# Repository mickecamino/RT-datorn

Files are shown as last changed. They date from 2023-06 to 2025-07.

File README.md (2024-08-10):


# RT-datorn
## En 6809-dator designad av Åke Holm (CÅ-Elektronik) på 80-talet. Den presenterades i tidningen Radio & Television, därav namnet RT-datorn. Operativsystemet var FLEX 9 eller FLEX 3.01 från Technical Systems Consultants 
### Med tillstånd av Åke Holm att publicera alla detaljer om RT-datorn
Två versioner finns av denna dator:

Den "gamla" som publicerades i ett antal artiklar i tidningen Radio & Television

Den "nya" som fanns i en artikel i tidningen Elektronikvärlden nr 4 1983.

## Följande kort fanns till den "gamla" RT-datorn:
* CÅ-790  - Videoterminal
* CÅ-800  - Första versionen av moderkortet
* CÅ-801  - Andra versionen av moderkortet
* CÅ-6819 - CPU-kort
* CÅ-6848 - Minneskort 48kb med dynamiska RAM-kretsar
* CÅ-8001 - ACIA, 2 st serieportar
* CÅ-8002 - PIA, 2 parallella portar
* CÅ-8003 - KCS-modem 300/1200 baud
* CÅ-8004 - Programmerbar timer med 6840
* CÅ-8005 - Digitalklocka med MM5318
* CÅ-8006 - HEX-display & tangenter
* CÅ-8008 - 16 ingångars 8-bitars A/D-omvandlare
* CÅ-8010 - EPROM-programmerare
* CÅ-8013 - Korthållsmodem 300 baud
* CÅ-8014 - Centronics-parallell
* Cå-8015 - Ny version av klock-kort med MSM5832
* CÅ-8016 - Ljudeffektskrets med SN76477
* CÅ-8017 - Flexskivekort
* CÅ-8018 - IEEE-488-bus anpassning
* CÅ-8020 - DEBUG-kort
* CÅ-8025 - EPROM-kort
* CÅ-8027 - Flyttalsprocessor AM9511
* CÅ-8030 - Okänt kort, donerat av Åke Holm. Funktion okänd.
* CÅ-8034 - Okänt kort, donerat av Åke Holm. Funktion okänd.
* CÅ-8043 - Färg-tv som dataskärm
* CÅ-8091 - Lab-kort med PIA
* CÅ-8092 - Lab-kort för ACIA/SSDA/ADLC
* CÅ-8095 - Förlängningskort för 22-polig buss
* CÅ-9000 - Förlängningskort för CPU-kort

## Följande kort fanns till den "nya" RT-datorn:

* CÅ-812 - CPU-kort
* CÅ-813 - Kommunikation
* CÅ-814 - Minneskort 48 kB med dynamiska RAM-kretsar
* CÅ-815 - Video-terminalkort
* CÅ-816 - EPROM-kort
* CÅ-817 - Diskett-interface
* CÅ-831 - Terminalkort enkelt
* CÅ-833 - Nyare kommunikationskort/RTC med MSM5832, ACIA och Centronics-port
* CÅ-834 - Minneskort med statiska RAM-kretsar
* CÅ-836 - Nydesignat 192 kb EPROM-kort med 1 kb RAM 
* CÅ-837 - Diskettinterface med Double Density

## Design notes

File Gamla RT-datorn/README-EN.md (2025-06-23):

## The following arcticles were published in the Swedish magazine Radio & Television
```
* Video terminal CA-790
* Part 1 - RT 1979-8
* Part 2 - RT 1979-9

* CPU and peripheral cards    
* Part 1  - RT 1979-12  - CA-6819 CPU board
* Part 2  - RT 1980-1   - CA-800 motherboard, CA-8001 ACIA (serial board)
* Part 3  - RT 1980-2   - CA-8004 Timer, CA-8091 PIA Lab board
* Part 4  - RT 1980-3   - CA-8017 Floppy interface
* Part 5  - RT 1980-5   - CA-8006 HEX terminal
* Part 6  - RT 1980-6/7 - CA-8003 cassette modem
* Part 7  - RT 1980-10  - CA-8005 Real Time Clock
* Part 8  - RT 1981-12  - CA-8010 EPROM-programmer
* Part 9  - RT 1981-1   - CA-8025 EPROM board
* Part 10 - RT 1981-3   - CA-8018 IEEE board
* Part 11 - RT-1981-9   - CA-8043 Color-TV as monitor

```

## The following boards was available to the "old" RT-computer:
* CA-790  - Video terminal
* CA-800  - First version of motherboard
* CA-801  - Second version of motherboard
* CA-6819 - CPU board
* CA-6848 - Memory board2 48kB with DRAM
* CA-8001 - ACIA, 2 st serial ports
* CA-8002 - PIA, 2 parallel ports
* CA-8003 - KCS-modem 300/1200 baud
* CA-8004 - Programmable timer with 6840
* CA-8005 - Real Time Clock with MM5318
* CA-8006 - HEX-display & keyboard
* CA-8008 - 16 input 8-bita A/D-converter
* CA-8010 - EPROM-programmer
* CA-8013 - 300 baud modem
* CA-8014 - Centronics-parallel
* CA-8015 - New Real time Clock with MSM5832
* CA-8016 - Sound board with SN76477
* CA-8017 - Floppy controller
* CA-8018 - IEEE-488-bus
* CA-8020 - DEBUG board
* CA-8025 - EPROM board
* CA-8027 - Floating Point Processor with AM9511
* CA-8030 - Unknown board, donated by Åke Holm. Function unknown
* CA-8034 - Unknown board, donated by Åke Holm. Function unknown
* CA-8043 - Color-TV as monitor
* CA-8091 - Lab board with PIA
* CA-8092 - Lab board for ACIA/SSDA/ADLC
* CA-8095 - Riser board for 22-pin bus
* CA-9000 - Riser board for CPU card

### The peripheral boards position on the motherboard determines the address:
RT-computer addressing
* J1  - E000-E00F = CA-8001 ACIA
* J2  - E010-E01F = CA-8017 Floppy controller
* J3  - E020-E02F = 
* J4  - E030-E03F = CA-8004 Timer 6840
* J5  - E040-E04F = 
* J6  - E050-E05F = CA-8005 RTC
* J7  - E060-E06F = CA-8010 EPROM-programmer
* J8  - E070-E07F = 
* J9  - E080-E08F = CA-8008 A/D-converter
* J10 - E090-E09F = 
* J11 - E0A0-E0AF = 
* J12 - E0B0-E0BF = CA-8003 cassette modem
* J13 - E0C0-E0CF = CA-8025 EPROM-card
* J14 - E0D0-E0DF = 
* J15 - E0E0-E0EF = CA-8006 HEX-terminal card

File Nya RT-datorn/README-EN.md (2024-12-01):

# The New RT-computer
## A FLEX 6809 computer designed by Åke Holm (CÅ-Elektronik) during the 1980's. It was featured in the magazine Radio & Television, hence the name RT-computer.
### With permission by Åke Holm to publish all details about the RT-computer

## The following boards were made for the "new" RT-computer:

* CÅ-812 - CPU-board  
The CPU-board featured static RAM addressed at $C000 - DFFF.  
Two sockets for EPROM's addressed at $F000 to FFFF. The CPU-board handles the decoding for the peripheral boards located at address $E000 - $E0FF. An extra RAM is addressed between $E100 and $E3FF to be used for the monitor and terminal software without interfering with the operating system FLEX 9.1.  

* CÅ-813 - I/O  
The new board for serial communication is called CÅ-813 and it replaces the older boards 8001, 8014 and 8015.  
It features a programmable serial communication IC for V24, a printer connection with parallel interface (Centronics) and a Real Time Clock with battery backup.  
The connection for printer and serial is via a 60-pin connector. 36 pins for the printer and 24 for the serial interface.  
See also CÅ-833

* CÅ-814 - memory board  
The memory board 814 replaces CÅ-6848. It is identical with one exception, the refresh for the dynamic memory chips is made continuously, instead as before, with 32 kHz. The memory size is 48 kB.  
Sea also CÅ-834

* CÅ-815 - Video terminal
The terminal is a completely new design. It is a memory mapped terminal, 24 lines and 80 columns. The board features the Motorola MC6845, display memory and a PIA for connecting the keyboard via a 26-pin connector. The pin out for the keyboard is identical with the CÅ-790. The display memory is located between $E800 and $EFFF, the CPU on board 812 is responsible for all terminal functions. All characters between computer and terminal is done without serial communication. The speed is much faster due to this. The character setup in the terminal is Swedish. 

* CÅ-816 - EPROM-board  
The new EPROM-board is called 816 and has 16 EPROM-sockets for 2532 EPROM's, each EPROM contains 4 kb. A total of 64 kb permanent memory is possible.. 
The board can hold for example the operating system FLEX and a BASIC interpreter. The addressing of the EPROM board is done via one single address. With a small software routine, loading from the boards EPROM to computer RAM is really simple.  
The board replaces the 8025-board.  
Se also CÅ-836  

* CÅ-817 - Floppy Controller  
The driver IC's for floppy drives on board 817 is equal to the board 8017. Up to four floppy drives, either single or double sided, single density can be connected.  
See also CÅ-837.  

* CÅ-831 - Terminal board - simple  
The simple hexadecimal terminal 8006 is replaced by 831, almost identical except that 831 also have a PIA for lab use.  

* CÅ-833 - I/O  
A newer design that replaces CÅ-813.  
Serial communication with 6850, a parallel printer output (Centronics) and a Real Time Clock with battery backup.  

* CÅ-834 - memory board  
New memory board for static memory, 6116 2k or EPROM 2716. Replaces CÅ-814.  

* CÅ-836 - 192 kb EPROM-board with 1 kb RAM.  
A new board for the RT-computer, designed by me. Three 27512 EPROM's gives 192 kb resident program memory in the computer, 1 kb RAM addressed at $E400-E7FF for a command table used by FLEX.   
With a small program, re-written by me based on a program from the magazine MPU-laren 1983-2, creates a command table for FLEX to load utilities from EPROM instead of floppy drives.  
FLEX can also be stored on this card and loaded from a new X command in CBUG. NOTE! Requires the updated CBUG4.4.  

* CÅ-837 - Floppy Controller with support for Double Density  
Replaces CÅ-817

### Memory mapping
```
Adres Function             board
$FFFF ----------------------------
      2k EPROM             CPU 812
$F800 ----------------------------
      2k EPROM             CPU 812
$F000 ----------------------------
      2k terminal RAM      CRT 815
$E800 ----------------------------
      1k RAM                   836
$E400 ----------------------------
      768 bytes RAM        CPU 812
$E100 ----------------------------
      CRTC + PIA           CRT 815
$E0F0 ----------------------------
      spare
$E0DF ----------------------------
      EPROM #3             816/836
$E0D0 ----------------------------
      EPROM #2             816/836
$E0C0 ----------------------------
      EPROM-board #1       816/836
$E0B0 ----------------------------
      spare
$E01F ----------------------------
      Floppy Controller    817/837
$E010 ---------------------------
      I/O                  813/833
$E000 ----------------------------
      8k static RAM        CPU 812
$C000 ----------------------------
      48k dynamic RAM      814/834
$0000 ----------------------------
```

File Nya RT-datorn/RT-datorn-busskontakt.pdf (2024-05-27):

C64 Europakontakt
1a | GND | GND | 1c
2a | GND | GND | 2c
3a | GND | GND | 3c
4a | -12V | -12V | 4c
5a | +12V | +12V | 5c
6a | -------- | EXT-RESET | 6c
7a | A | B | 7c
8a | BA | HALT | 8c
9a | -------- | -------- | 9c
10a | E400 | E800 | 10c
11a | A14 | A15 | 11c
12a | A12 | A14 | 12c
13a | A10 | A11 | 13c
14a | A8 | A9 | 14c
15a | A6 | A7 | 15c
16a | A4 | A5 | 16c
17a | A2 | A3 | 17c
18a | A0 | A1 | 18c
19a | I/O-SEL | R/W | 19c
20a | RESET | E | 20c
21a | IRQ | GND | 21c
22a | GND | D0 | 22c
23a | GND | D1 | 23c
24a | GND | D2 | 24c
25a | GND | D3 | 25c
26a | GND | D4 | 26c
27a | GND | D5 | 27c
28a | GND | D6 | 28c
29a | GND | D7 | 29c
30a | +5V | +5V | 30c
31a | +5V | +5V | 31c
32a | +5V | +5V | 32c

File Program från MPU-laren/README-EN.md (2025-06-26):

# Program from MPU-laren
## A collection of software presentd in MPU-laren 
Hare are some programs presented in MPU-laren from # 1 - 1978 to the last number #1 - 1990 
### 1978-1
```
MASTER.BAS  - Mastermind - text based
MONLAND.BAS - Classic game - land the lunar lander on the moon
```
### 1979-2
```
EIGHTMEN.BAS - Arcade game
```
### 1979-3
```
FODELSED.BAS - Date information for birthday
FODELSED.TXT - Information about the program (in Swedish)
```
### 1979-4
```
QUEST.BAS     - Adventure game
HEX.BAS       - Convert HEX to DECIMAL
```
### 1980-1
```
DJUR.BAS      - Guess the animal
DJURBIBL.SYS  - library for DJUR.BAS
```
### 1980-2
```
GENEO.BAS     - Genealogy program, Swedish
WHIST.BAS     - Card Game
```
### 1980-3
```
OTHELLO.BAS   - Othello
```
### 1980-4
```
INFO.TXT      - Address register, info text, NOTE: Swedish Only
EJCT-82.TXT   - Address register, other terminal than CT-92
DEL-1.BAS     - Address register, part 1
DEL-2.BAS     - Address register, part 2
HUVUD-1.BAS   - Address register, main program 1
HUVUD-2.BAS   - Address register, main program 2

SHOOTSTA.BAS  - Shoot stars - space game
KYRKA.BAS     - prints a church in ASCII on a matrix printer
```
### 1981-1
```
GOBANG.BAS    - Tic-tac-Toe with 19 x 19 squares
PATCHTS.ASM   - Patch a byte on specific track ans sector
```
### 1981-2
```
CLOCK.ASM     - IRQ-based clock
SYSTES.ASM    - System test of FLEX 9
```
### 1981-3
```
LOTTO.BAS     - Lotto program
RELOCATE.ASM  - Program for relocating binary files
```
### 1981-4
```
MASTER.BAS    - Mastermind
MATEMAT.BAS   - Match game
```
### 1982-1	
```
CLOCKSET.ASM  - Software for setting up the MSM5832 RTC
DIR.ASM       - Better version than CAT for listing files
FLEXPAT.ASM   - Patch for FLEX 2.65, read MSM5832
UNDEL.ASM     - Undeletes files
VOXMEM.ASM    - Program that speech - needs VS-1 Speaker Board
VOXMEM1.ASM   - Program that speech - needs VS-1 Speaker Board - alternative voice
```
### 1982-2
```
BACKUP.ASM    - Backup-program - backup from one diskette to another (0 to 1)
LOGG.BAS      - Log program for HAM radio
LOGG790.BAS   - Log program for HAM radio, for CÅ-790 terminal
```
### 1983-2
```
PROM.ASM      - Program that download PROM based files to RAM
PROM.TXT      - Information about PROM.ASM
```
### 1984-2
```
PIA.BAS       - Program to help initialize PIA
```
### 1984-3
```
BOK8.BAS      - Simple book keeping software
BOK8.TXT      - Information about the program.
```
### 1985-3
```
DSKSPD.ASM    - Program for measuring the speed of a diskette. For the CÅ-8017
```

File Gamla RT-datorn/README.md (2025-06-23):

## Följande artiklar publicerades i Radio & Television
```
* Videoterminalen CÅ-790
* Del 1 - RT 1979-8
* Del 2 - RT 1979-9

* CPU och periferikort    
* Del 1  - RT 1979-12  - CÅ-6819 CPU-kort
* Del 2  - RT 1980-1   - CÅ-800 moderkort, CÅ-8001 ACIA (seriekort)
* Del 3  - RT 1980-2   - CÅ-8004 Timer, CÅ-8091 PIA Labbkort
* Del 4  - RT 1980-3   - CÅ-8017 Flexskiveinterface
* Del 5  - RT 1980-5   - CÅ-8006 HEX terminalkort
* Del 6  - RT 1980-6/7 - CÅ-8003 kassettmodem
* Del 7  - RT 1980-10  - CÅ-8005 Realtidsklocka
* Del 8  - RT 1980-12  - CÅ-8010 EPROM-programmerare
* Del 9  - RT 1981-1   - CÅ-8025 EPROM-kort
* Del 10 - RT 1981-3   - CÅ-8018 IEEE-kort
* Del 11 - RT-1981-9   - CÅ-8043 Färg-TV som dataskärm
```

## Följande kort fanns till den "gamla" RT-datorn:
* CÅ-790  - Videoterminal
* CÅ-800  - Första versionen av moderkortet
* CÅ-801  - Andra versionen av moderkortet
* CÅ-6819 - CPU-kort
* CÅ-6848 - Minneskort 48kB med dynamiska RAM-kretsar
* CÅ-8001 - ACIA, 2 st serieportar
* CÅ-8002 - PIA, 2 parallella portar
* CÅ-8003 - KCS-modem 300/1200 baud
* CÅ-8004 - Programmerbar timer med 6840
* CÅ-8005 - Digitalklocka med MM5318
* CÅ-8006 - HEX-display & tangenter
* CÅ-8008 - 16 ingångars 8-bitars A/D-omvandlare
* CÅ-8010 - EPROM-programmerare
* CÅ-8013 - Korthållsmodem 300 baud
* CÅ-8014 - Centronics-parallell
* Cå-8015 - Ny version av klock-kort med MSM5832
* CÅ-8016 - Ljudeffektskrets med SN76477
* CÅ-8017 - Flexskivekort
* CÅ-8018 - IEEE-488-bus anpassning
* CÅ-8020 - DEBUG-kort
* CÅ-8025 - EPROM-kort
* CÅ-8027 - Flyttalsprocessor AM9511
* CÅ-8030 - Okänt kort, donerat av Åke Holm. Funktion okänd.
* CÅ-8034 - Okänt kort, donerat av Åke Holm. Funktion okänd.
* CÅ-8043 - Färg-tv som dataskärm
* CÅ-8091 - Lab-kort med PIA
* CÅ-8092 - Lab-kort för ACIA/SSDA/ADLC
* CÅ-8095 - Förlängningskort för 22-polig buss
* CÅ-9000 - Förlängningskort för CPU-kort

### Kortens placering i moderkortet bestämmer dess adress:
RT-datorns addressering
* J1  - E000-E00F = CÅ-8001 ACIA
* J2  - E010-E01F = CÅ-8017 Flexskivekort
* J3  - E020-E02F = 
* J4  - E030-E03F = CÅ-8004 Timer 6840
* J5  - E040-E04F = 
* J6  - E050-E05F = CÅ-8005 RTC
* J7  - E060-E06F = CÅ-8010 EPROM-programmerare
* J8  - E070-E07F = 
* J9  - E080-E08F = CÅ-8008 A/D-omvandlare
* J10 - E090-E09F = 
* J11 - E0A0-E0AF = 
* J12 - E0B0-E0BF = CÅ-8003 kassettmodem
* J13 - E0C0-E0CF = CÅ-8025 EPROM-kort
* J14 - E0D0-E0DF = 
* J15 - E0E0-E0EF = CÅ-8006 HEX-terminalkort

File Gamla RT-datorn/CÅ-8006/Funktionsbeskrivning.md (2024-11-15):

# Funktionsbeskrivning

- De tidigare avsnitten i denna serie har direkt syftat till en komplett dator med terminal av videotyp och flexskivesystem för högnivåspråk. 
- Den som är nybörjare vill förmodligen göra en mjukstart och börja med en billigare dator utan avancerad terminal och flexskiva. 
- I avsnittet beskriver vi därför ett litet periferikort som terminal för nybörjaren. Med det samt ett processorkort enligt RT 1979 12 , monterade på ett moderkort, får man en liten dator som kan användas för utbildning och maskinkodsprogrammering. Funktionerna är i många avseenden samma som Motorolas D2-kit.  

Den som har tänkt att bygga en hobbydator enligt RT:s byggserie kommer snart underfund med att det fordras en terminal av något slag för att man skall kunna kommunicera med datorn. Terminalen kan vara en videoterminal med tangentbord och bildskärm eller en teletypemaskin av något slag. Båda typer är relativt dyra jämfört med de grundkomponenter som datorn består av. För att erbjuda en billigare grundvariant av datorn har ett nytt periferikort konstruerats. Det ger tillsammans med processorkortet, som beskrevs i RT 1979 nr 12, och moderkortet, som beskrevs i RT 1980 nr 1, en fungerande dator med ett litet tangentbord och sex lysdiodindikatorer. Funktionerna påminner starkt om Motorolas D2-kit, men det finns vissa förbättringar ifråga om expansionsmöjligheter och programhanteringen av tangenter och indikatorer. Indikatorkortet skall placeras i kontakten J15 på moderkortet. I sockeln IC34 på processorkortet placeras Eprom-kretsen med monitorprogrammet ECBUG och datorn är klar att användas.  

Med monitorprogrammet kan man ändra i minnesceller, beräkna offset för relativ adressering, lägga in brytpunkter, starta program och med ett anpassningskort för kassettspelare spela in och av data på en vanlig audiokassett. Det finns även en variant av monitorprogrammet för den som direkt vill arbeta med 6809-processorn. Monitorn kallas FOBUG och har samma kommandon som ECBUG. För att bruka datorn behövs till att börja med endast 1 k RAM på adress $A000-A3FF. 
## Periferikortets funktion 
Principschemat för det kombinerade indikator- och tangent-bordskortet återfinns i fig 1.  

För att ge en enkel programhantering och ökad användbarhet i andra tillämpningar än just terminalfunktionen används två specialkretsar från ***National Semiconductor***. Den ena kretsen har beteckningen MM74C917 och är en anpassningskrets för lysdiodindikatorer. På ena sidan av kretsen ansluts data och adress-signaler från mikroprocessorn och på den andra sidan sex lysdiodindikatorer av 7-segmenttyp. Kretsen innehåller minnen för de olika indikatorerna samt multiplexfunktion för att minska antalet förbindelser mellan indikatorerna och kretsen. Från mikroprocessorns synvinkel adresseras varje lysdiod-indikator som en minnescell av "write only"-typ. I kretsen sker hexadecimal avkodning av de fyra databitarna D0-D3 till de sju segmenten på indikatorerna. Databit 7 används för att tända decimalpunkten på varje indikator.  
I fig 2 finns blockschema för MM74C917 återgivet.  

Den andra specialkretsen har beteckningen MM74C923 och dess blockschema återfinns i fig 3.  

Till kretsen ansluts de 20 tangenterna i matrisform. IC2 är en avkodare, som ger varje funktion på kortet sin unika adress. De sex lysdiodindikatorerna har adresserna $80E0-80E5, data från tangentbordet hämtas på adress $80E6 och indikering på att någon tangent är nedtryckt finns på adress $80E8. De tre högsta adresserna $80EA, $80EC samt $80EE är lediga. I programmet ECBUG används dock utgången $80EE för att ge en puls till en "BELL"-krets av något slag. Tonsignaleringen används för att indikera fel i exempelvis "memory change"-rutinen.  

När någon tangent har tryckts ned, kommer utgången DA på IC3 att gå till hög nivå och ställa RS-vippan IC4 så att utgången på stift 3 blir hög. När processorn läser på adress $80E8, blir databit 7 låg, eftersom T7 fungerar som en grind. När basen är hög och emittern låg, blir kollektorn också låg. Adressen används vid test för att undersöka om någon tangent har tryckts ner. När data sedan hämtas kommer en läspuls på utgången stift 12 på IC2. Denna puls återställer RS-vippan IC4 och lägger ut värdet från IC3 över dess ingång OE (output enable). På databussen får man då ett hexadecimalt tal mellan $E0 och $F3 eftersom de tre högsta databitarna alltid är "1".  

Kretskortet återfinns i skala 1:1 i fig 4 sett från komponentsidan, och komponentplaceringen återfinns i fig 5. Om man vill placera indikatorerna och tangenterna i en låda för sig, kapas kortet vid den heldragna linjen och de båda kortdelarna förbinds med flatkabel. På grund av att indikatorerna är multiplexade bör flatkabeln inte vara längre än 50-60 cm, eftersom störningar annars kan komma in på tangentbordskretsen IC3. Om kortet skall monteras odelat i den enklare datorlådan kan man ta upp ett hål i fronten och placera ett rött filter framför lysdiodindikatorerna. Av fig 5 framgår var de olika uppmärkta tangenterna skall lödas in. Först måste dock alla byglingar, markerade med vita linjer, lödas. Indikatorerna löds direkt på kretskortet. Vill man kunna byta dem, bör emellertid socklar användas. IC1 och IC3 är av MOS-typ och skall ej sättas i förrän alla andra komponenter är inlödda. När kortet är färdigmonterat kan man prova datorn. På moderkortet skall indikatorkortet placeras i en kontakt på position J15. Kortet vänds så att lödsidan är vänd åt kontaktposition J14. I någon av kontakterna J16-21 placeras ett processorkort med MC6808. I sockel IC34 placeras monitorprogrammet ECBUG och i socklarna IC10 och IC11 skall två 2114-kretsar sitta. Byglingarna "RAM-adress" på processorkortet kopplas för A-B, och alla fyra byglarna vid omkopplaren S1 skall vara på plats. Omkopplaren S2 för vektorval kopplas för EC, dvs  den fjärde sektionen från vänster skall slås till. För den som skall använda MC 6809 gäller, att sektion fem (FO) också skall slås till. Monitorprogrammet för 6809 placeras i sockel IC26 och de båda kondensatorerna C1-2 samt kristallen X1 löds in innan IC36 sätts i hållaren. När spänningarna ansluts (+5, +12 och -12 V), skall de sex indikatorerna visa 0.00000 och decimalpunkten blinka långsamt på den första indikatorn. 
Monitorprogrammets funktioner 
De 20 tangenterna märkta 0-9 samt A, B, C, D, E, F, L, P, R och S används för att mata in hexadecimala tal för data och adresser samt för olika kommandon. För att ge en viss likhet med de monitorprogram vilka har en bildskärm som presentationsenhet har vissa funktioner införts för att förenkla handhavandet för användaren. Detta har även den fördelen, att det blir relativt lätt att vänja om sig vid senare övergång till en bildskärmsterminal. De fyra första indikatorerna används av monitorprogrammet för att visa adresser och andra 16-bitars tal. De två övriga används för att visa data och 8-bitars tal. Båda monitorprogrammen har samma kommandon och identiska egenskaper. Till varje monitorprogram medföljer en programlistning med kommentarer. När punkten på första indikatorn blinkar långsamt innebär det att programmet är i kontrollslingan och väntar på ett kommando. Det finns då åtta kommandon att välja mellan: 
- A, Alter Memory: 
Minnesmanipulering. Efter att ha tryckt pa A blinkar punkten med högre hastighet och det är nu bara att knappa in en 4-ställig hexadecimal adress till den minnescell man vill undersöka. Adressen visas på de fyra första indikatorerna och data i adressens minnescell på de två sista indikatorerna. Nu finns det fyra vägar att fortsätta på: Om data skall ändras på den aktuella minnespositionen gör man så enbart genom att ange två hexadecimala tecken (0-9, A-F). Om det nya värdet fastnar i minnet, dvs  om det fanns RAM-minne på den adressen, visas det nya värdet ett kort ögonblick varefter programmet stegar vidare till efterföljande minnesposition och visar datainnehållet i den minnescellen. Inmatning av maskinkod från en lista blir på det sättet enkel. Om man bara vill undersöka vad som finns i de olika minnes-cellerna, kan man stega genom minnet med L-tangenten. Med P-tangenten kan man stega baklänges i minnet. För att återgå till kontrollslingan trycker man på R. Om man försöker ändra data på en adress där det inte finns något RAM; det kanske är ROM, EPROM eller ett "write only"-register i en periferikrets, ger datorn en BELL-puls och ingen ändring av minnesadressen sker. Det är användbart särskilt om man skall mata in olika tal i en periferikrets register för att prova dess utgångar. Med S-tangenten kan man på ett enkelt sätt beräkna offset för relativ adressering. Det är annars ett tidsödande arbete, speciellt vid handskrivna program i maskinkod. Om vi exempelvis befinner oss i minnesposition A200 med instruktionen 26 (BEQ), skall på den efterföljande minnespositionen stå offset-värdet till den adress dit vi skall hoppa, om föregående instruktion gav ett resultat som blev noll. Vi antar, att adressen är A1BE. På minnesposition A201 trycker vi på S-tangenten och knappar in adressen A1BE. På dataindikatorn står därefter BC, vilket är det uträknade 2-komplements offsettal som datorn behöver för att hamna på rätt adress vid programmets körning. Eftersom det uträknade och visade offsetvärdet skall läggas in på den angivna minnesadressen så gör programmet det åt oss, varefter nästa minnesadress med innehåll visas på indikatorerna. Problemet med 2-komplement-offset behöver inte längre bekymra den som gör program i maskinkod med funktionen. Om det skulle visa sig att den inmatade adressen ligger för långt ifrån, anges det med en BELL-puls utan ändring av minnesadressen. 
- B, Set Breakpoint: 
En brytpunkt är ett slags programstopp, vilket används under avlusning (eng "debugging") av program. Funktionen åstadkoms genom att man ersätter den ursprungliga opkoden med opkoden för SWI. När programmet kommer till SWI, avbryts det och registren skrivs ut (se nedan under R). Inläggning av SWI sker automatiskt vid E- eller C-kommando. Borttagning av SWI sker också automatiskt, såvida inte programmet avbryts med ett tryck på reset-knappen. I så fall får man för hand ändra de minnesceller som var försedda med brytpunkter. Maximalt fem brytpunkter kan samtidigt anges. En brytpunkt inmatas genom att man trycker på B och en adress. Efter det återgår programmet till kontrollslingan. 

- C, Continue: 
Används för att fortsätta efter en brytpunkt. När registren har visats och programmet är i kontrollslingan, trycker man på C. Stackpekaren laddas då med det ursprungliga värdet, varefter en RTI utförs och programmet fortsätter. 
- D, Delete Breakpoints: 
Tar bort alla definierade brytpunkter från monitorprogrammets tabell. 
- E, Execute Program: 
Används för att starta program på en viss adress, t ex E 0100, vilken går till adress $0100 och startar det program som finns där. Eventuella brytpunkter har dessförinnan placerats in på sina platser. 
- L, Load: 
Ladda minnet med data från kassett. Rutinen förutsätter att ett KCS-modem finns placerat i kontakten J3 på moderkortet. Data följer Motorolas Si-format. Under laddningen visas adress till varje datainspelning på adressindikatorn och varje dataord återges på dataindikatorn. Det innebär, att man vet var i minnet laddning sker och att data verkligen kommer in. Laddningen avslutas när koden S9 kommer in från kassetten, varvid programmet återgår till kontrollslingan. 
- P, Punch Data: 
Spela in data mellan två adresser på kassett. Förutsätter KCS-modem, se ovan. Initieras genom att man efter P anger start- och slutadress för det minnesblock som skall spelas in. Eftersom data sänds så fort sista tecknet har matats in, bör man starta bandspelaren så fort P-tangenten har tryckts ner. Under inspelningen visas adress och data på indikatorerna på samma sätt som vid laddningsfunktionen. När alla data är utmatade, avslutas det hela med koden S9. Att lagra data enligt det här formatet har den stora fördelen att kassetterna kan användas och spelas upp även över andra terminaler utan att man behöver tillgripa specialrutiner. 
- R, Register Display: 
Tangenten visar registren i processorns stack. Först visas på dataindikatorn CC-registret (condition code), med ett tryck på S-knappen visas sedan i tur och ordning B-ackumulatorn, A-ackumula-torn, X-registret, PC-värdet och S-värdet. Vid fortsatt tryckning på S-knappen upprepas det hela och programmet återgår till kontrollslingan med R-knappen. För 6809-utförandet av monitorprogrammet presenteras registren i följande ordning: CC, A, B, DP, X, Y, U, PC och S. Till denna rutin kommer programmet automatiskt vid SWI, NMI och IRQ om RAM-vektorerna för dem ej har ändrats av användaren. Eftersom det kan komma att finnas flera varianter av monitorprogrammen återger vi inga adresser till dem eller andra rutiner. Adresserna framgår dock tydligt av programlistan. Övningsprogram Monitorprogrammet använder RAM-adresserna $A000- AO7F för att lagra konstanter och variabler. Till att göra egna program har man alltså minnesområdet $A080-A3FF fritt. I monitorprogrammet finns rutiner för att exempelvis presentera A-ackumulatorns innehåll på dataindikatorn, för att mata ut ett 16-bitars värde från indexregistret på adressindikatorn och för att hämta in ett tecken från tangentbordet. Rutinerna kan användas i egna program. Det blir därvid ganska enkelt att göra ett program för digitalklocka t ex. Att använda datorn som enbart digitalklocka är dock inte avsikten. Det är ändå en bra övning till att förstå mikroprocessorns arbetssätt och för att lägga en grund till mera avancerad programmering. I nästa avsnitt presenteras KCS-modemet för lagring av data på band.

### Fig 1
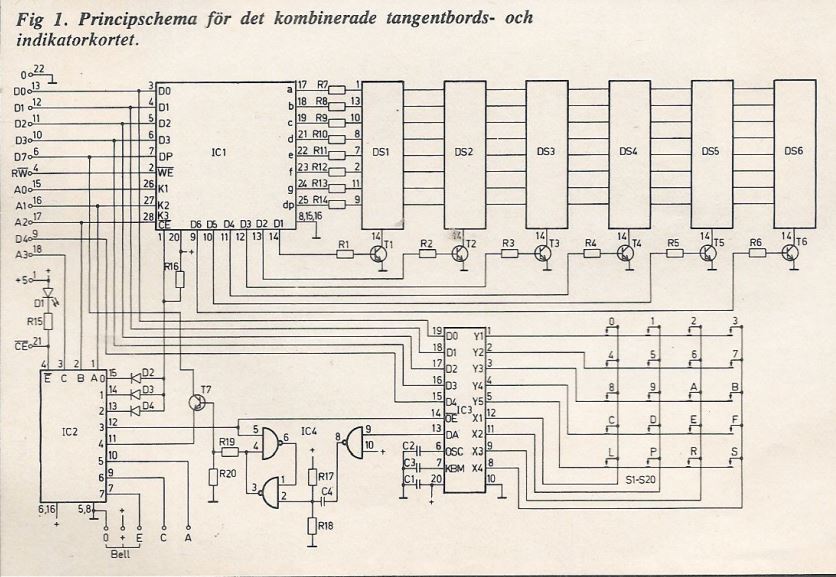
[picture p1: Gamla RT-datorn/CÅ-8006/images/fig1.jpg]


### Fig 2
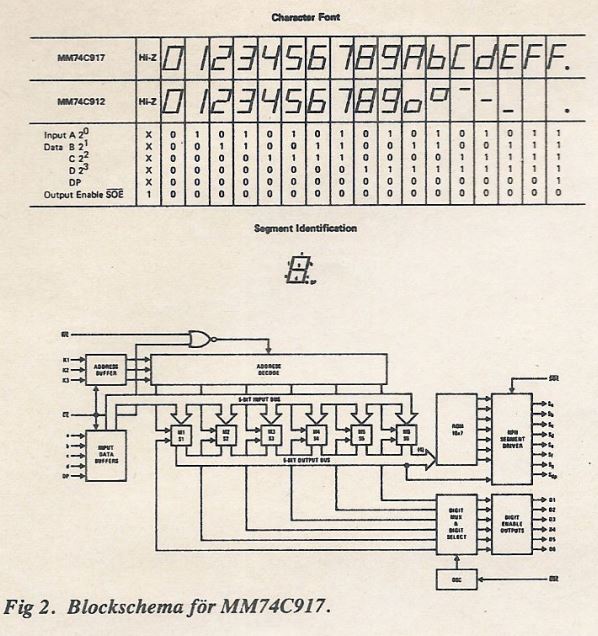
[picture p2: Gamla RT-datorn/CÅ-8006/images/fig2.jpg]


### Fig 3
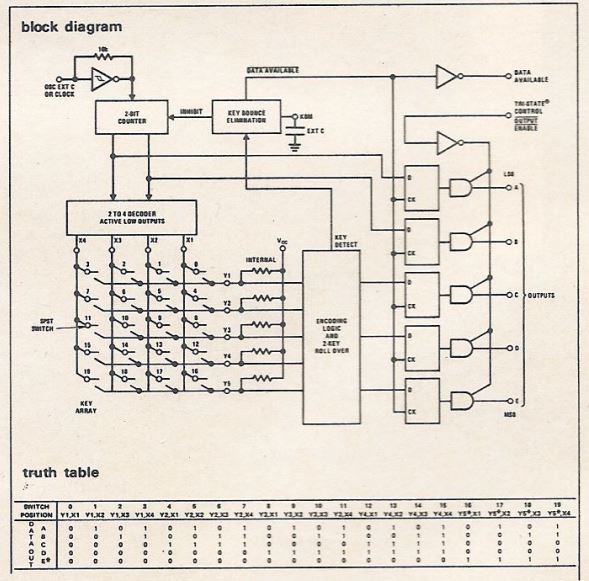
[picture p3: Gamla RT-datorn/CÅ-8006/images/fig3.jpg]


### Fig 4
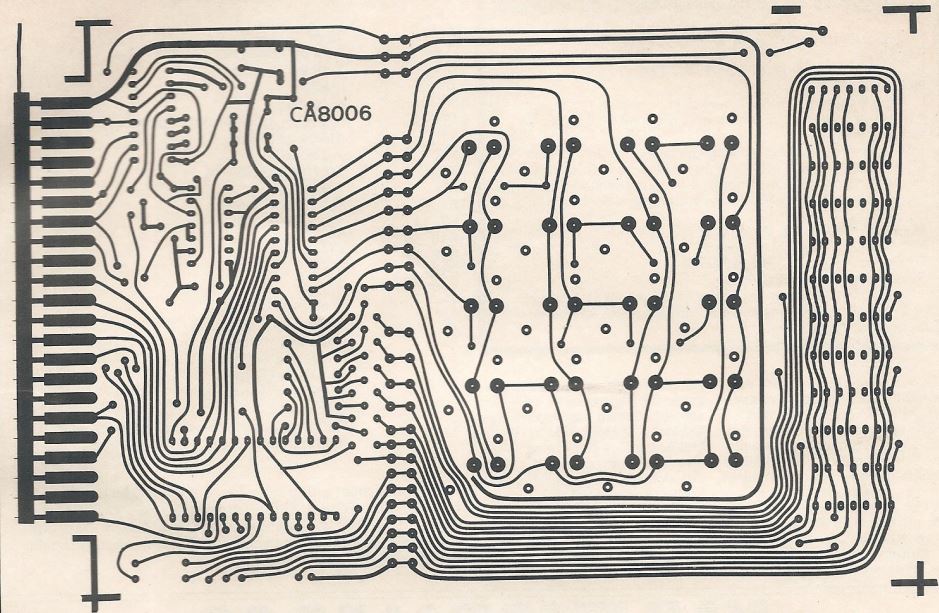
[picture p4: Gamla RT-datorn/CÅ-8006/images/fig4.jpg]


### Fig 5
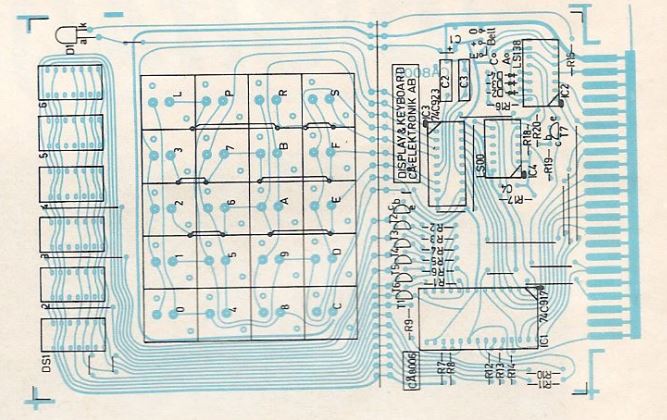
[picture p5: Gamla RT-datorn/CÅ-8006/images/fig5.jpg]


Kompletta satser enligt ovan kan beställas från CÅ-Elektronik AB, box 2010, 135 02 Tyresö, tel, 08-XXX XX XX, från Telko i Stockholm, Göteborg och Malmö, samt från Digitronic. En komplett sats med ett monitorprogram kostar 448 kr exkl. moms.  

Ett bygge av en komplett dator kräver följande:  
1 st moderkort typ 800, beskrivet i RT 1980 nr I. Pris 370 kr.  
1 st CPU-kort typ 6819, beskrivet i RT 1979 nr 12. Pris 945 kr.  
1 st indikatorkort typ 8006, beskrivet i detta RT-nummer, pris 448 kr, inklusive monitorprogram för 6808.  
Priserna är inklusive moms.  
Med dessa tre kort och en lämplig nätdel som lämnar +5 V 1,5 A, +12 V 100 mA och -12 V 100 mA har man grunddelarna till ett datorbygge med obegränsade expansionsmöjligheter. En del av de kort som behövs för utbyggnaden har redan beskrivits i RT.  
De är:  
Minneskort 16 k RAM, RT 1978 nr 11.  
Videoterminal, RT 1979 nr 8 och 9.  
Timerkrets och labkort, RT 1980 nr 2.  
Flexskiveanpassning, RT 1980 nr 3.  
I kommande nummer skall ytterligare kort till datorbygget beskrivas. Kort och komponenter till datorserien kan beställas från bl a Telko.

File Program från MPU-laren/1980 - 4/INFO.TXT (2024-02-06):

* * ADRESSREGISTER av ]ke Sten{ng * *

Det h{r programmet {r det f|rsta adressregistret i MPU-laren f|r TSC-basic och random datafil,
men hoppas att det inte {r det sista.
L|sningarna {r ju som alltid m}nga och det finns f|rst}s smartare s{tt att l|sa detta problem.
Om Du har ett adressprogram s} l}t oss f} se det!

F|r den som |nskar finns en upps{ttning av programmen p} PD-68, eller
skicka en diskett och adresserat kuvert till:

]ke Sten{ng
Ljungbergsv. 25
564 00  Bankeryd
------------------------------------------------------------

   Inneh}llsf|rteckning:
A) Allm{n beskrivning.
B) Anv{nda variabler.
C) Detaljbeskrivning.
D) Annan terminal {n CT-82.
E) F|rslag till l{mpliga filer p} disketterna i drive 0 och drive 1.
F) Bin{rfil f|r SORT/MERGE. Sorterar ],[,\\ i r{tt ordning.
G) Adresslista fr}n DEL-1, subrutin 3000.
H) Adresslista med SORT/MERGE i bokstavsordning.
I) Adresslista fr}n DEL-2, subrutin 3000.
J) Listning av samtliga basicprogram.
   HUVUD-1.BAS
   DEL-1  .BAS
   HUVUD-2.BAS
   DEL-2  .BAS
------------------------------------------------------------
 1
A) * * Allm{n beskrivning * *

Program 1. F|r max 320 namn (1 namn/sektor)
Program 2. F|r max 640 namn (2 namn/sektor)

Adressregistren {r avsedda f|r FLEX 2.0, TSC:s basic, minifloppy, CT-82 terminal och en printer (CENTRONICS 779).
Anv{ndarminnet m}ste vara 32 k plus minne f|r DOS.
F|r den som har annan terminal {n CT-82, se punkt D).
P} Centronics 779 {r teckenbredden st{llbar med en potentiometer.
Har man bara en teckenbredd m}ste rutinerna 3000 i DEL-1 och DEL-2 arrangeras om.
Programmen {r skrivna som kundregister, men {r l{tta att {ndra till
medlemsregister eller annat register!

Varje adressregister best}r av tv} BASIC programm, HUVUD-program och DEL-program plus en DATA-fil.
Man kan g} fr}n det ena basicprogrammet till det andra genom ett kommando.

HUVUD-programmet har hand om inmatning av nya namn, {ndring av variabler och borttagning av ett eller flera namn.
Rutinerna LISTNING och ETT NAMN I TAGET kan visas p} sk{rm.
Ingen printerrutin finns i HUVUD-programmet.

DEL-programmet {r endast ett utskriftsprogramm, antingen till printer eller p} sk{rm.
Rutinen LISTNING VERTIKALT kan anv{ndas f|r etiketter (en rad).
LISTNING ETT NAMN/TV} RADER kan anv{ndas f|r en fullst{ndig lista p} alla namn.

Inget av registren har automatisk ut|kning av datafilens sektorer.
Man f}r vid uppstartning reda p} hur m}nga sektorer som finns i datafilen och om den beh|ver ut|kas.
S{kerhet finns ocks} s} att man inte kan mata in fler namn {n det finns sektorer, ut|kning beg{rs d}!
Man f}r p} detta s{tt full kontroll |ver datafilens storlek.

Datafilen kan sorteras enligt n{stan varje |nskem}l, t.ex i bokstavsordning (eller annan ordning), efter postnummer eller
telefonnummer osv.
F|r denna sortering anv{nds TSC:s SORT/MERGE.
Att sortera inom basicprogrammen och med 32 k minne vore f|rst}s smart!
Kanske n}gon har en l|sning p} detta, t.ex. med "nycklar"!?
I punkt H) har parametrarna f|r sorteringen satts i en bin{rfil som
kallas PARA-1A f|r HUVUD-1.BAS.
Kommandot f|r sortering i punkt H) blir d}: +++P,PSORT,0.PARA-1A,REG-1.DAT.
Filerna p} disketterna m}ste d} vara ordnade enl punkt E).

Om max antal namn skall skrivas in, f}r disketten endast inneh}lla COPY.CMD och CAT.CMD
plus datafilen som d} l{mpligen ut|kas till full storlek vid f|rsta uppstartningen.
En kort presentation av de b}da adressregistrens kapacitet f|ljer nu:

Adressregister f|r 320 namn.
Varje kund anv{nder 1 sektor=252 tecken.
Vid inmatningen tilldelas kunden ett unikt nummer.
Om kunden tas bort blir numret vakant till n{sta inmatning av ny kund.
Datum f|r varje inmatning skrivs automatiskt in f|r varje kund.
I detta register finns det plats f|r fler variabler d} 87 tecken i varje
sektor inte anv{nds i programmet.

Programmets inmatningsrutin inneh}ller:
Efter- o f|rnamn ell f|retag  max 30 tecken
C/O                           max 20 tecken
Gata ell Box                  max 30 tecken
Postadress                    max 25 tecken
Tel nr                        max 13 tecken
Land                          max 25 tecken
Reserv                        max 87 tecken

Adressregister f|r 640 namn.
Varje kund anv{nder 1/2 sektor=126 tecken.
Vid inmatningen tilldelas kunden ett unikt nummer.
Om kunden tas bort blir numret vakant till n{sta inmatning av ny kund.
Datum skrivs ej in (f}r ej plats).

Programmets inmatningsrutin inneh}ller:
Efter- o f|rnamn ell f|retag  max 30 tecken
C/O                           max 20 tecken
Gata ell Box                  max 30 tecken
Postadress                    max 25 tecken
Tel nr                        max 13 tecken
------------------------------------------------------------

B) * * Anv{nda variabler * *

A,A$,AA$,A1$ = KUNDNUMMER (med b|rjan fr}n 1001)
  B$,BB$,A1$ = NAMN eller F\\RETAG
  C$,CC$,C1$ = C/O
  D$,DD$,D1$ = GATA eller BOX
  E$,EE$,E1$ = POSTADRESS
  F$,FF$,F1$ = LAND
  G$,GG$,G1$ = TEL NR

      TR,TR$ = Totala antal anv{nda records, inkl subrecords och borttagn.
      BO,BO$ = Antal borttagningar.
      SE,SE$ = Antal sektorer i datafilen.

  S$,SS$,S1$ = Datumstr{ng utan f|r- o efterspace, ]]-MM-DD.
      YY,YY$ = ]r
      MM,MM$ = M}n
      DD,DD$ = Dag

          KA = Kundantal
          Z4 = Ut|kningsvariabel f|r sektorer i datafilen.
          Z5 = Recordr{knare
           E = Recordnummer
           S = V{ljer subrecord 1 eller 2 i program 2.
         DA$ = Datafilens namn i rad 85.
         FA$ = Firmans namn i rad 86.
         AN$ = Anv{ndarens namn ell firma i rad 87
          AN = R{knar tecken i AN$
         CR$ = S{tter 0D sist i varje record f|r SORT/MERGE.
          UT = Om UT=1 m}ste datafilen ut|kas.
           H = Menyvariabel
           G = Till sk{rm eller printer.
         (Y) = F|r minnesintagning.
    B,D,Q,Q1 = R{knare f|r minnesintag. D ger antal namn till minne.
          SI = Sidnummer
         W,U = FOR NEXT variabel.
         AB$ = INPUTLINE variabel (div).

       T1-T5 = TAB-variabler i rutin 3000, rad 3315:
                                                            SID (T1=88)
NAMN         GATA (T3=31)         POSTADRESS (T4=62)        C/O (T5=88)
KUNDNR       DATUM                TEL NR                    LAND
------------------------------------------------------------

C) * * Detaljbeskrivning * *

Rad 35-45: St{ller CT-82 i mode 82*20, baude 38400, keyp.=numerisk.
Rad 50: DP=0
Rad 55-75: G|r en datumstr{ng utan f|r- o efterspace, ]]-MM-DD.

Rad 90,100,300-320: Programmet s|ker f|rst efter en gammal datafil och om inte den finns
g}r programmet genom rad rad 90 till rad 300.
D{r st{ngs den |ppnade filen och OPEN g|r en ny fil av storleken 4 sektorer
och SE s{tts d} till 10 sektorer som i rad 315 skrivs in i:
          program 1 i RECORD 1, SE$
          program 1 i RECORD 2, subrecord 1 RB$

Rad 120: FIELD. I program 1 anv{nds FIELD en g}ng vid programmets uppstartning. I program 2 m}ste FIELD initieras varje
g}ng subrecord skall {ndras.
D{rf|r {r FIELD som RETURN-rutin.
F|r |kad snabbhet i inmatningen av nya namn finns en separat FIELD i 3161.

Genom att st{lla S=1 eller 2 kan man f} FIELD att v{lja subrecord 1 ell 2.
I FIELD "126 ASZ$" f}r varje subrecord 126 tecken.

Rad 140-150: Tomma eller tidigare inskrivna variabler f|r:
TR= Totala antalet anv{nda RECORDS,inkl subrecords o borttagning(ar)
    som |kas i inmatningsrutinen.
BO= Antal borttagningar.
SE= Antal sektorer i datafilen som skrivs in dels vid f|rsta upp-
    startningen i rad 315 och senare vid varje ut|kning i 190-200.
TR minus BO blir kundantalet KA.
Rad 153,162: Se INMATNING.
Rad 164: Om SE <= totala RECORDS + 10 (som ut|kningsreserv), s}
visas "B\\R DATAFILEN UT\\KAS".

S\\KT RECORD:
I program 1 st{lls RECORD enkelt genom t.ex,
Z5=3:E=Z5:GET #1, RECORD E
I program 2 m}ste {ven subrecord 1 eller 2 best{mmas enl:
Oj{mnt kundnummer= subrecord 1
J{mnt  kundnummer= subrecord 2
        Subrecord= S     S=1   S=2
                          kundnr
            RECORD 1     1       2
            RECORD 2     3       4
            RECORD 3     5       6
            RECORD 4     7       8
                         osv
ex. rutinen EN KUND I TAGET:

I rad 1100 (Z5=A-1000) f}r man ett tal som {r ett kundnummer minus 1000.
Om talet {r st|rre {n TR g}r programmet tillbaks till 1080, annars unders|ks
i rad 1110 om talet {r oj{mnt "IF Z5/2<>INT(Z5/2) osv".
Vid oj{mnt tal blir subrecord=1 och s|kt RECORD blir d} det oj{mna talet
+1 dividerat med 2. (Z5+1)/2.
D{refter g}r programmet till FIELD (GOSUB 120) f|r initiering.

Om talet {r j{mnt s} st{lls i rad 1120 S=2 och talet divideras med 2
s} har man s|kt RECORD och subrecord.

LISTNING VERTIKALT:
F|r att slippa ha floppyn ig}ng hela tiden tar programmet in 25 namn i minnet,
rad 2300-2390 och skickar sedan ut dessa namn till sk{rm eller printer.
Rad 2335-2340 ordnar s} att listningen ej |verstiger kundantalet KA.

INMATNING:
Programmet g}r olika v{gar beroende p} om det {r 1) F|rsta inmatningen
 2) Annan inmatning (utan BO), 3) Om n}gon borttagning skett.

Inmatningen hindras helt om vissa flaggor st{llts!
Om KA=0 kan endast inmatningsrutinen anv{ndas!

1) F|rsta inmatning: Genom rad 3020 st{lls RECORD och kundnummer (i program 2 {ven subrecord).
I rad 3100 f|rs 20 namn (eller mindre) till minnet och sedan |ver till disketten.
Genom LSET skrivs de olika variablerna in p} disketten fr}n inmatningsrutinen 3300.
TR$, BO$, SE$, Z$ och RB$(program 2) s{tts tomma i varje RECORD d{rf|r att inget f{lt
f}r best} av null om datafilen skall anv{ndas i SORT/MERGE.
Till sist skrivs aktuella data till TR, BO, SE in i resp RECORD enl FIELD-listningen.

2) Annan inmatning: Om inmatning skett tidigare och ingen borttagning finns
s} g}r programmet till 3025 resp 3025,3026 (program 2).
TR {r nu st|rre {n 0 s} d{rf|r anv{nds samma unders|kning (i program 2) som i EN KUND I TAGET f|r att hitta RECORD resp subrecord.
H{r m}ste dock RECORDS och subrecords |kas med 1, d} det ju {r f|ljande RECORD som skall anv{ndas.

3) Om borttagning skett tidigare anv{nds rutinen 3030-3085(3090).
H{r sker en sekventiell s|kning i 3045(3046).
Ny inmatning i det vakanta numret sker sedan p} vanligt s{tt.
Rutinen anv{nds s} l{nge n}got vakant nummer finns (rad 3080 resp 3085).
F|r att kunna skriva in nya namn efter borttagning och filen {r slut
(UT=1) finns rad 3002,3102.
Genom att hoppa |ver 3007 (som st{nger f|r inmatning vid UT=1) kan nu
ett nytt namn l{sas in p} ett vakant nummer.
Ett stopp m}ste dock s{ttas i 3102, annars kan man forts{tta att l{sa in helt nya namn
efter en inmatning i borttagningsrutinen.
I 3085 s{tts ju TR+1 och genom att d} s{tta TR+5 i 3102 s} {r stoppet klart
och ny inmatning i 3105 kan aldrig n}s.
Fr}n 3211 g}r programmet direkt till 520 (MENY), d} man i detta fall
inte beh|ver veta om datafilen {r slut eftersom vakant(a) nummer finns.

Inmatningsrutinen 3300: Rad 3305-3327 skrivs ut direkt och sedan g}r
cursorn till f|rsta variabeln.
Snedstreck (/) visar max tecken som kan anv{ndas.
I rad 3330 g}r cursorn upp 5 resp 6 rader och sedan till h|ger 46 steg,
och i 3335 kopplas cursorn till.
Aktuell variabel skrivs nu in och cursorn st{ngs av.
D{refter g}r cursorn en rad ner, 46 till h|ger osv.

Programmen 1 och 2 kan ta emot max 320 resp 640 namn.
F|r att hindra vidare inmatning (disketten slut), s} s{tts flaggor f|r detta i 162,3005,3132.

Inmatningen f}r ju inte heller |verstiga antal sektorer i datafilen.
Detta r{knas ut och flaggor s{tts f|r att f|rhindra inmatning och ursp}rning i 153,3007,3133 och i 3212.
Om inmatning |nskas i detta fall beg{rs ut|kning av datafilen.
DOS-systemet ger datafilen 2 tomma sektorer allra f|rst i filen och kan ej anv{ndas f|r data.
Sj{lva basicprogrammen s{tter som s{kerhet 2 tomma sektorer sist i varje datafil.
D{rf|r " +4 " i dessa flaggrutiner.

BORTTAGNING: Samtliga variabler enl inmatningsrutinen 3300 s{tts h{r tomma.
BO |kas med 1 vid varje borttagning och BO skrivs in i resp RECORD.

[NDRING: Varje inmatningsvariabel kan {ndras i denna rutin.

LISTNING, ETT NAMN/TV] RADER: Principen med sekventiell s|kning {r densamma som i LISTNING,VERTIKALT.
Utskriften {r till f|r 72 raders papper i bana.
Sidnumrering ing}r.
------------------------------------------------------------
D) * * Annan terminal {n CT-82 * *

[ndra enl f|ljande i HUVUD-programmen:
Ta bort rad 35-45.
Ta bort rad 2040.
2700 IF C=KA THEN 520
10010 END

[ndra enl f|ljande i DEL-programmen:
Ta bort rad 35-45.
2070 IF G=1 THEN 2300
3070 IF G=1 THEN 3300
10010 END
Ta bort rad 2882 och 3882.

Ta bort 3300-3375 och 5800-5890 och ers{tt med f|ljande:
F|r HUVUD-1.BAS g{ller hela rutinerna enl nedan.
F|r HUVUD-2.BAS , ta bort 3360-3365 och 5880-5890.
3300 PRINT:PRINT"* * INMATNING * *":PRINT
3305 PRINT"NR";A
3310 INPUT "MAX 30 TECKEN!  EFTER- o F\\RNAMN ell F\\RETAG ";BB$
3315 IF LEN(BB$)>30 THEN PRINT CHR$(7):PRINT">30 G\\R OM":GOTO 3310
3320 PRINT "MAX 20 TECKEN!  C/O (skriv {v C/O).......... ";:INPUT LINE CC$
3325 IF LEN(CC$)>20 THENP RINT CHR$(7):PRINT">20 G\\R OM":GOTO 3320
3330 PRINT "MAX 30 TECKEN!  GATA ell BOX (skriv {v BOX). ";:INPUT LINE DD$
3335 IF LEN(DD$)>30 THEN PRINT CHR$(7):PRINT">30 G\\R OM":GOTO 3330
3340 PRINT "MAX 25 TECKEN!  POSTADRESS.................. ";:INPUT LINE EE$
3345 IF LEN(EE$)>25THEN PRINT CHR$(7):PRINT">25 G\\R OM":GOTO 3340
3350 PRINT "MAX 13 TECKEN!  TEL NR...................... ";:INPUT LINE GG$
3355 IF LEN(GG$)>13THEN PRINT CHR$(7):PRINT">13 G\\R OM":GOTO 3350
3360 PRINT "MAX 25 TECKEN!  LAND........................ ";:INPUT LINE FF$
3365 IF LEN(FF$)>25 THEN PRINT CHR$(7):PRINT">25 G\\R OM":GOTO 3360
3370 PRINT:PRINT"TRYCK RETURN F\\R FORTSATT INMATNING!"
3375 PRINT "SKRIV 'S' F\\R SLUT!";:INPUT LINEAB$:PRINT:RETURN

5800 PRINT B$;"  -[NDRAS TILL";
5810 INPUT BB$:LSET B$=BB$:RETURN
5820 PRINT C$;"  -[NDRAS TILL";
5830 INPUT LINE CC$:LSET C$=CC$:RETURN
5840 PRINT D$;"  -[NDRAS TILL";
5850 INPUT LINE DD$:LSET D$=DD$:RETURN
5860 PRINT E$;"  -[NDRAS TILL";
5870 INPUT LINE EE$:LSET E$=EE$:RETURN
5875 PRINT G$;"  -[NDRAS TILL";
5876 INPUT LINE GG$:LSET G$=GG$:RETURN
5880 PRINT F$;"  -[NDRAS TILL";
5890 INPUT LINE FF$:LSET F$=FF$:RETURN

5800-5890 b|r kanske begr{nsas enl INMATNING med max tecken!
------------------------------------------------------------

E) * * F|rslag till l{mpliga filer i drive 0 och drive 1. * *

CATALOG OF DRIVE NUMBER 0
DISK: ADRESS-1  #1

 NAME   TYPE  SIZE  PRT

ERRORS  .SYS     9
FLEX2   .SYS    25
PRINT   .SYS     1
CAT     .CMD     5
LIST    .CMD     3
COPY    .CMD     5
TTYSET  .CMD     2
RENAME  .CMD     1
DELETE  .CMD     2
ASN     .CMD     1
BUILD   .CMD     1
P       .CMD     1
EXEC    .CMD     1
DATE    .CMD     2
LINK    .CMD     1
NEWDISK .CMD     7
MAKEDISK.TXT     1
BASIC   .CMD    56
RENUMBER.CMD     2
CT-82   .CMD     1    (\\nskad uppstartning av CT-82 terminal)
TIME    .CMD     1
STARTUP .TXT     1    (t.ex.  ASN,W=1,S=0:BASIC,0.HUVUD-1 )
COLL    .BIN     1
SRTMRG  .SYS    19
SORT    .CMD    14
PSORT   .CMD     3
HUVUD-1 .BAC    36    (Kompilerat program)
DEL-1   .BAC    22
PARA-1A .BIN     2

SECTORS LEFT = 114

CATALOG OF DRIVE NUMBER 1
DISK: REG-1  #2

 NAME   TYPE  SIZE  PRT

COPY    .CMD     5
CAT     .CMD     5
REG-1   .DAT   326

SECTORS LEFT = 4
-------------------------------------------------------------
F) * * Bin{rfil f|r SORT/MERGE * *

               * NAME: COLL.BIN
               * ALTERNATE COLLATING SEQUENCE FILE FOR SORT/MERGE
               * RIGHT SORT OF SWEDISH ],[,\\. By ]. Sten{ng
               *
                        OPT    NOG
 0600                   ORG    $0600
 0600 41                FCC    /ABCDEFGHIJKLMNOPQRSTUVWXYZ][\\/
 061D 61                FCC    /abcdefghijklmnopqrstuvwxyz}{|/
 063A 30                FCC    /0123456789/
 0644 21                FCC    /!"#$%&'()*+/
 064F 2C                FCB    $2C,$2D,$2E,$2F
 0653 3A                FCC    /:;<=>?@/
 065A 5E                FCC    /^_/
 065C 60                FCB    $60,$7E,$7F
 065F 00                FCB    0,1,2,3,4,5,6,7,8,9,10,11,12
 066C 0D                FCB    13,14,15,16,17,18,19,20,21,22
 0676 17                FCB    23,24,25,26,27,28,29,30,31
                        END

NO ERROR(S) DETECTED

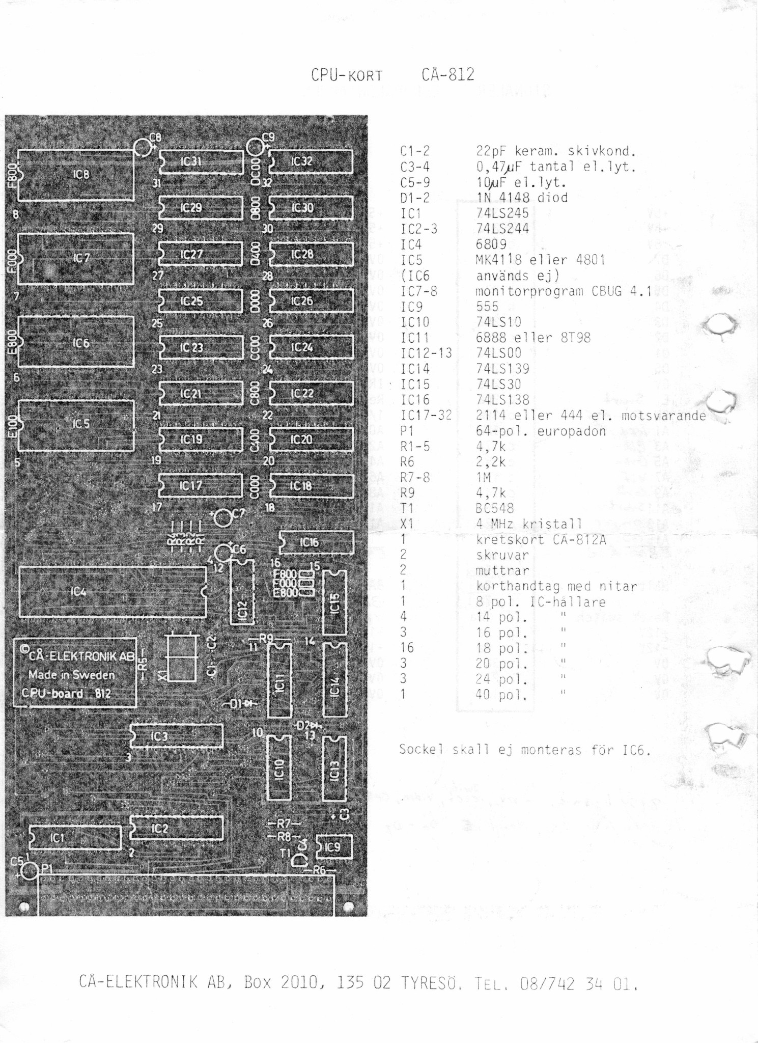
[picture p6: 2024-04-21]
Nya RT-datorn/CÅ-812/CÅ-812-info.jpg

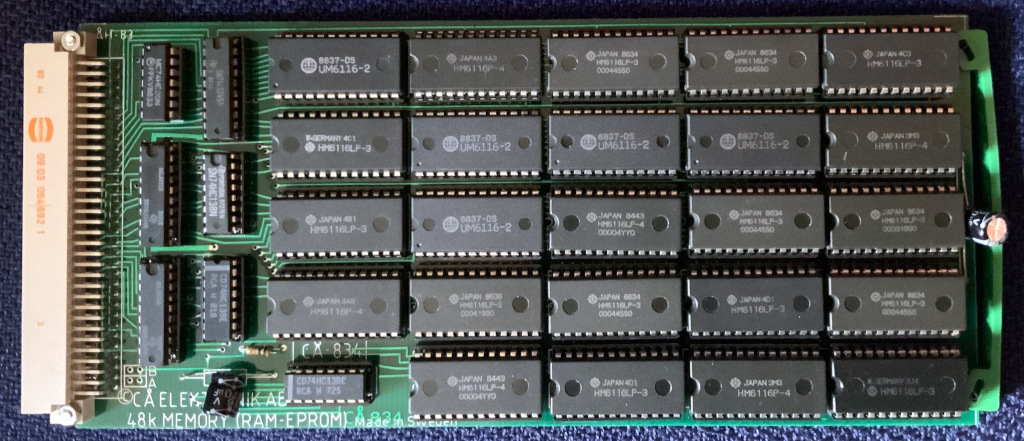
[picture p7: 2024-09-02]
Nya RT-datorn/CÅ-834/CÅ-834-bestyckat.jpg

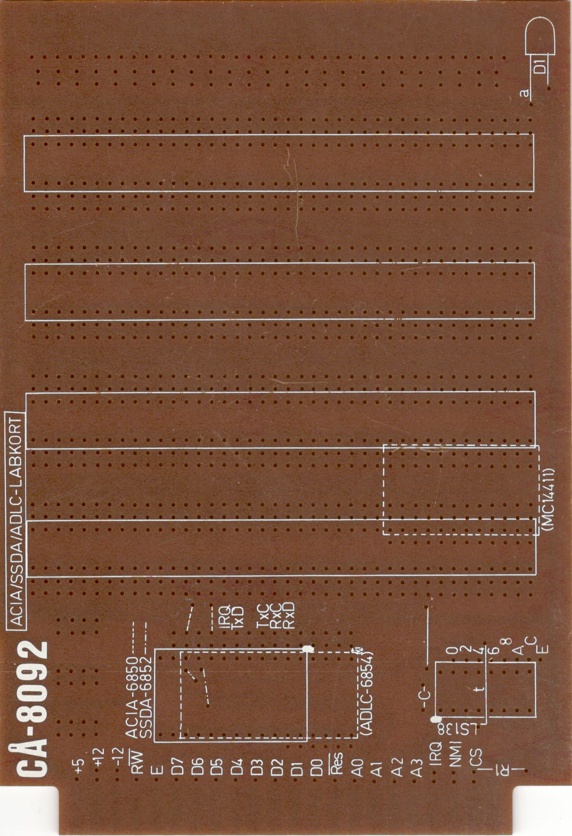
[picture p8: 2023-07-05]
Gamla RT-datorn/CÅ-8092/CÅ-8092.jpg

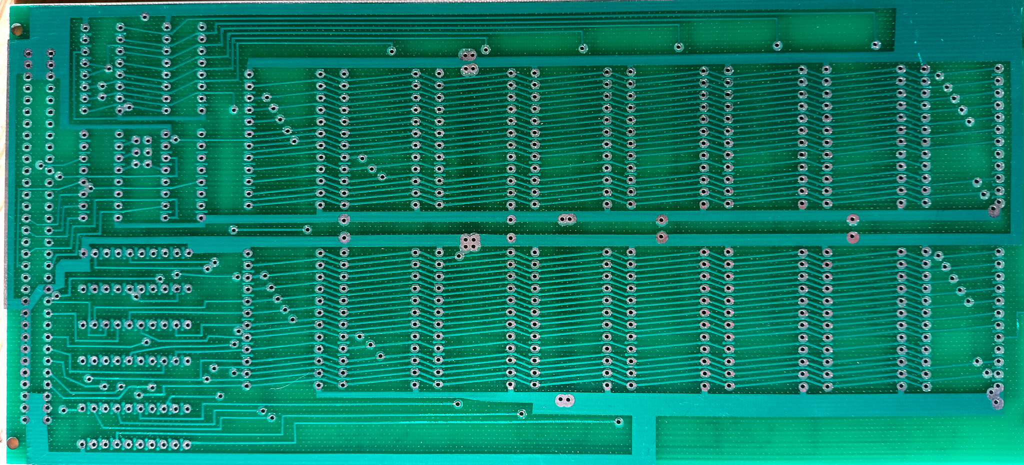
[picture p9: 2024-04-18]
Nya RT-datorn/CÅ-816/CÅ-816-pcb-back.jpg

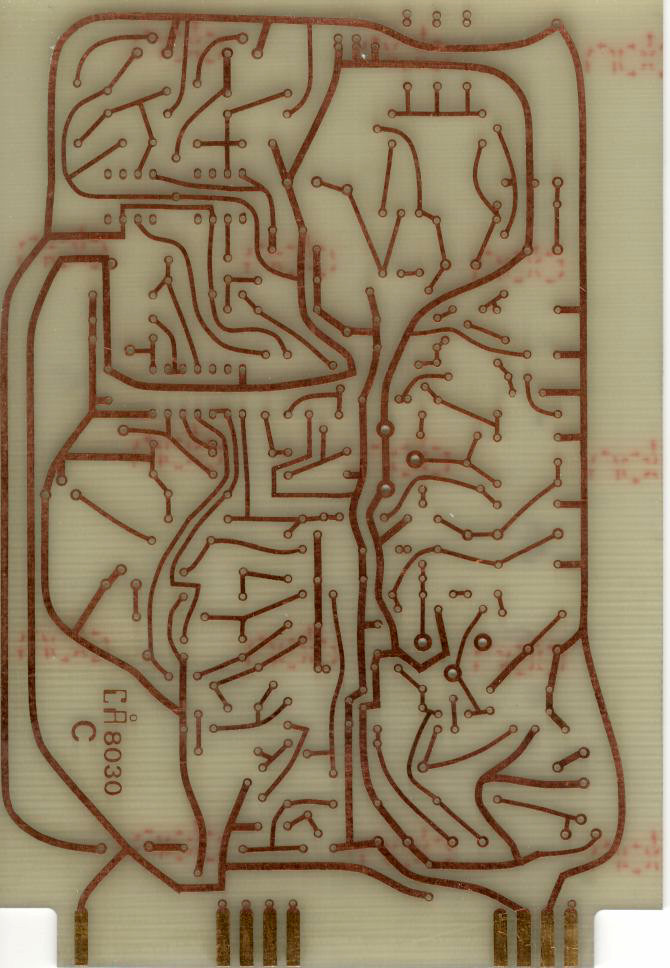
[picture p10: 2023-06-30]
Gamla RT-datorn/CÅ-8030/CÅ-8030-baksida.jpg

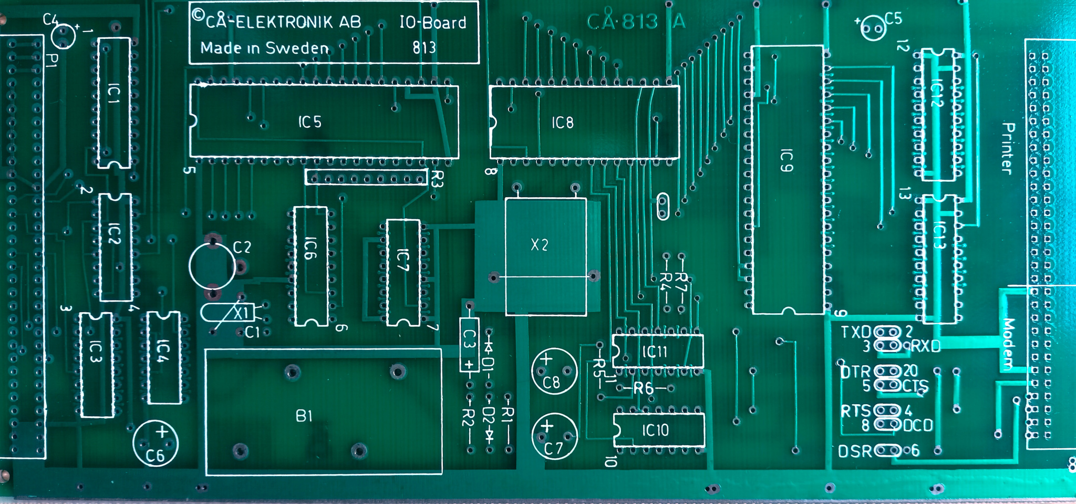
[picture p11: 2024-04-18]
Nya RT-datorn/CÅ-813/CÅ-813-pcb-front.jpg

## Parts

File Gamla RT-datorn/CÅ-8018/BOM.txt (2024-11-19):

C1      47 uF 25 V el lyt
Dl      röd lysdiod
IC1     MC 68488 (Motorola)
IC2     74LS240
IC3     74LS00
IC4-7   MC 3448A (Motorola)
R1      220 ohm
R2      4,7 k
R3      7x4,7 k
SI      8-pol dip-omkopplare
l       kretskort CÅ-8018
1       IC-hållare l4-pin
4       IC-hållare l6-pin
l       IC-hållare 20-pin
1       IC-hållare 40-pin

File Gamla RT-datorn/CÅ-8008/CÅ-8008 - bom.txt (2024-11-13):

CÅ-8008 BOM
C1  - 0,1 uF polyester
C2  - 220 pF styrol
D1  - röd lysdiod
IC1 - 6821
IC2 - ADC 0817 eller ADC 0816
IC3 - 4001 eller 4011
(IC4 - 74LS138)
R1  - 220 ohm
R2  - 4,7 k
R3 - R18 - 100 k trimpot

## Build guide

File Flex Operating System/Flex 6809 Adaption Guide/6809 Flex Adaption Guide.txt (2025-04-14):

6809 FLEX™ Adaptation Guide

Technical Systems Consultants, Inc.

6809 FLEX™ Adaptation Guide

Copyright © 1980 by
Technical Systems Consultants, Inc.
111 Providence Road
Chapel Hill, North Carolina 27514
All Rights Reserved.

™FLEX is a trademark of Technical Systems Consultants, Inc.

COPYRIGHT INFORMATION
This entire manual is provided for the personal use and enjoyment of the purchaser. Its
contents are copyrighted by Technical Systems Consultants, Inc., and reproduction, in
whole or in part, by any means is prohibited. Use of this program, or any part thereof,
for any purpose other than single end use by the purchaser Is prohiwteds

DISCLAIMER
The supplied software is intended for use only as described in this manual. Use of
undocumented features or parameters may cause unpredictable results for which Technical
Systems Consultants, Inc. cannot assume responsibility. Although every effort has been
made to make the supplied software and its documentation as accurate and functional as
possible, Technical Systems Consultants, Inc. will not assume responsibility for any
damages incurred or generated by such material. Technical Systems Consultants, Inc.
reserves the right to make changes In such material at any time without notice.

DISCLAIMER
PLEASE READ BEFORE OPENING THE DISKETTE ENVELOPE!
This version of FLEX is not for beginners. It is assumed that the user
has a good knowledge of assembly programming and of his hardware.
Technical Systems Consultants, Inc, cannot and will not be held
responsible for the adaptation of FLEX nor for the operation of the
resulting product. FLEX has been proven in the field for over two years
and the adaptation procedure has been tested on numerous systems.
For
these reasons:
NO TECHNICAL ASSISTANCE FOR THE ADAPTATION OF FLEX WILL
BE PROVIDED BY TECHNICAL SYSTEMS CONSULTANTS, INC!
Knowing this, read the FLEX Adaptation Guide thoroughly and make a
decision as to whether or not you are capable of performing the
adaptation without assistance. If not, Technical Systems Consultants,
Inc, will refund your money (less shipping and damage charges) if you
return the manual and diskettes IN THEIR UNOPENED ENVELOPE.
Once the
diskette envelope has been opened, no returns will be accepted!

iii

TABLE of CONTENTS
Section

Page

1.0 Introduction
. . . . . . . . . . . . . . . . . . . . . . . .
1.1 Important Documents
1.2 What You Receive
1.3 System Requirements
1.4 How to Use the Adaptation Guide

1
1
1
1
2

2.0 The FLEX Disk Operating System
. . . . . . . . . . . . . . .
2.1 Disk Operating System Concepts
2.2 A Brief Overview of FLEX Adaptation
2.3 FLEX Disk Format

3
3
4
5

3.0 The Console I/O Driver Package
. . . . . . . . . . . . . . .
3.1 Console Driver Routine Descriptions
3.2 Implementing the Console I/O Drivers

6
6
8

4.0 The Disk Driver Package
. . . . . . . . . . . . . . . . . .
4.1 The Disk Driver Routines
4.2 Disk Driver Routine Specifications
4.3 Developing the Disk Driver Routines
4.4 Overflowing the Disk Driver Area

9
9
10
12
14

5.0 Testing the Disk Driver Routines
. . . . . . . . . . . . . .
5.1 Preparing a Disk
5.2 Tests Without Using a Supplied Disk
5.3 Testing the READ Routine
5.4 Testing the WRITE Routine
5.5 Testing the VERIFY Routine

15
15
16
17
19
21

6.0 Bringing Up the Initial Version of FLEX
. . . . . . . . . .
6.1 Loading FLEX with QLOAD
6.2 Testing FLEX with Read-Only Commands
6.3 Testing FLEX with Write Commands
6.4 Using this Version of FLEX

22
22
23
23
24

7.0 Preparing a Bootable Version of FLEX

. . . . . . . . . . . .

25

8.0 Bootstrap Loading of FLEX
. . . . . . . . . . . . . . . . .
8.1 The Concept of Bootstrap Loading
8.2 Writing a ROM Boot Program
8.3 Writing a FLEX Loader Program
8.4 Hints on a Two Sector FLEX Loader

26
26
27
28
29

9.0 The NEWDISK Routine
. . . . . . . . . . . . . . . . . . . .
9.1 The General NEWDISK Procedure
9.2 A Western Digital NEWDISK Example
9.3 Hints on a Non-Western Digital NEWDISK
9.4 Sector Interleaving

30
30
33
33
34

vii

TABLE of CONTENTS (Continued)
Section

Page

10.0 Printer Spooling and Interrupt Handling
. . . . . . . . .
10.1 Hardware Requirements
10.2 Firmware Requirements
10.3 Console I/O Drivers for Printer Spooling
10.4 Disk Driver Changes for Printer Spooling

36
36
36
37
38

11.0 Advanced Disk Adaptation
. . . . . . . . . . . . . . . . .
11.1 Double-Sided Disks
11.2 Double-Density Disks
11.3 Other Disk Configurations
11.4 NEWDISK Routines

39
39
40
42
42

12.0 Additional Customization
. . . . . . . . . . . . . . . . .
12.1 Setting a Default MEMEND
12.2 Altering the FLEX Date Prompt
12.3 Replacing Printer Spooler Code
12.4 Mapping Filenames to Upper Case

43
43
43
44
45

13.0 Miscellaneous Suggestions
. . . . . . . . . . . . . . . . .
13.1 Replacement Master FLEX Disks
13.2 Initialized Disks Available
13.3 The FLEX Newsletter
13.4 Single Drive Copy Program
13.5 Give Us Some Feedback

46
46
46
46
47
47

APPENDICES
Appendix A - 6809 FLEX Memory Map
. . . . . . . . . . . . . . .
Appendix B - Disk Formats
. . . . . . . . . . . . . . . . . . .
Appendix C - READ/WRITE Test Utility
. . . . . . . . . . . . . .
Appendix D - Quick FLEX Loader Utility
. . . . . . . . . . . . .
Appendix E - Skeletal FLEX Loader
. . . . . . . . . . . . . . .
Appendix F - Skeletal NEWDISK Routine
. . . . . . . . . . . . .
Appendix G - Sample Adaptation for SWTPc MF-68
. . . . . . . . .
1) Console I/O Driver Package
2) Disk Driver Package
3) ROM Boot Program
4) FLEX Loader Program
5) NEWDISK Program

viii

48
49
51
55
57
59
75
78
81
86
87
90

6809 FLEX Adaptation Guide
1.0 INTRODUCTION

1.1 Important Documents
There are two very important documents which ABSOLUTELY MUST be read
before continuing. The first is a yellow disclaimer document and the
second is a green copyright information sheet. They should be the first
two sheets of this manual. These two documents are perhaps the most
important reading in the entire set of FLEX documentation and it is
imperative that the user read and fully understand them
before
attempting any adaptation of FLEX.
1.2 What You Received
The general version of FLEX should include the following items:
1) FLEX Adaptation Guide
2) FLEX User's Guide
3) FLEX Advanced Programmer's Guide
4) Text Editing System Manual
5) Assembler Manual
6) Two diskettes sealed in an envelope
7) Yellow Disclaimer Sheet
8) Green Copyright Information Sheet
9) Loose-leaf binder
If you
are
immediately.

missing

any of these items, contact our order department

1.3 System Requirements
In order to perform the adaptations and to run FLEX, there are certain
hardware and software or firmware requirements. Specifically they are:
1) Computer system with 8K of RAM at $C000 and at least 12K of
RAM beginning at location $0000.
2) A system console or terminal such as a CRT terminal or printer
terminal.
3) A single 8 or 5 1/4 inch disk drive with controller capable of
running soft-sectored format with 256 byte sectors.
4) A monitor ROM or some program affording the ability to begin
execution at any desired point and to enter code into the
system. This coding may be done by hand, but some sort of
storage method such as cassette or paper tape would be
helpful. Additionally, since the user is required to write
several routines, an editor/assembler package will make the
adaptation much easier.

Page 1

Section 1

6809 FLEX Adaptation Guide
1.4 How to use the Adaptation Guide
This
manual contains all of the necessary instructions for the
adaptation of FLEX to any system meeting the requirements listed above.
This adaptation is not a simple step, however, and you may save some
headaches by beginning the process in the correct order as explained
shortly.
Before attempting to install FLEX, the manuals should be read
and understood. A good order for reading the manuals is to read section
2 of this Adaptation Guide titled 'The FLEX Disk Operating System', then
read the FLEX User's Guide (not necessarily reading all the command
descriptions therein), and then read the remainder of this Adaptation
Guide. After reading all this material, be sure to re-read the yellow
disclaimer sheet and decide whether you are capable of performing the
adaptations.
One suggestion that will be made often in this manual is to keep things
simple. Since you are starting from the ground up, it will be best to
keep all routines simple at first.
Once things are running in the
simplest, lowest level form, it will be much easier, using the now
available FLEX facilities, to improve the routines and add new devices.

Page 2

Section 1

6809 FLEX Adaptation Guide
2.0

The FLEX DISK OPERATING SYSTEM

2.1 Disk Operating System Concepts
For those users who are new to disk operating systems, it might be
appropriate to briefly discuss some basic concepts. There are two major
reasons to have an operating system. First is that it relieves the
programmer from the task of writing the low-level I/O and file
management routines each time a piece of software is written. That work
has all been done by the authors of the operating system allowing the
user to concentrate on his application software. The second major
reason is that it removes all hardware interfacing from the application
program. This, of course, makes application programs shorter and easier
to write, and has the added advantage of making the application program
transportable to any computer system running the same operating system.
The advantages of software transportability should be immediately
obvious.
The FLEX Disk Operating System was originally designed to support a
single-user system with floppy disks. As we shall see however, it is
not restricted to floppy disks only. FLEX contains routines to handle
all the "low-level" tasks associated with maintaining data on disks.
Rather than having to write programs which must keep track of what data
is where on the disk, worry about how much space is available, control
the selection of drives, seek to tracks, load the head, etc., the
programmer can let FLEX take care of these duties and merely keep track
of his data by named files. A "file" is simply a collection of data
which is stored on the disk under a unique "filename". It can contain
anything from a source listing to a collection of data from a BASIC
program to the text for a letter. FLEX maintains a directory on track 0
(the outermost track) which contains the name and starting address
(track and sector number) of each file stored on the disk. The user
program can call on FLEX routines to create such files, write data to
them, read data from them, delete them, load them into memory, rename
them, etc. FLEX also has several user-accessible "convenience" routines
which have nothing to do with the disk, but allow the user to do things
like print a string, get a decimal number from the input line, classify
a character, etc. In general, FLEX is a very powerful tool which saves
application programs (and programmers) from doing a lot of housekeeping
chores.

Page 3 - Section 2

6809 FLEX Adaptation Guide
2.2 A Brief Overview of FLEX Adaptation
To make things more clear as you progress through the adaptation
procedure, let's go through a brief summary of the steps involved.
The
whole idea of the adaptation process is to perform the necessary steps
to interface FLEX to your particular hardware. The main body or core of
FLEX does not care what kind of hardware it is running on. It
communicates with the actual hardware through two packages of routines
which must be user written and which are unique for various hardware
configurations. The core of FLEX doesn't change - only these two
hardware interface packages. These packages are a set of low-level disk
driver routines and a set of console or terminal I/O routines.
Throughout the manual we will refer to these packages as the DISK
DRIVERS and the CONSOLE DRIVERS respectively. As an example, when FLEX
wants to read a sector of information from the disk, the core of FLEX
doesn't care what kind of disk it is or where it is located.
The core
of FLEX simply asks the disk driver package to read sector number 4 on
track number 18 and expects it to do whatever it must to read that
sector.
Thus the heart of the adaptation process is writing the
routines for the Console Driver and Disk Driver packages.
(1) The first step is to write "Console I/0 Driver" and "Disk Driver"
routines for interfacing to the system console or termina l and to the
disk controller.
The development of these routines may be carried out
in a number of ways. If the user has access to another 6809 development
system with editor and assembler, he should by all means take advantage
of that power. Alternatively, it may be necessary to write the routines
on the system being adapted. This implies that either some sort of tape
editor and assembler must be used or the routines must be hand-assembled
into object code.
In either case, it is convenient to have a mass
storage device on-line to save and load the drivers during development.
(2) Once the drivers are written, they must be fully tested.
is provided to aid in testing the Disk Drivers.

A program

(3) After the drivers have been proven functional, a short program is
supplied which will allow FLEX to be loaded in from disk. The FLEX on
disk has no drivers, but when loaded into memory will make use of the
resident, user supplied drivers.
Once this FLEX is in memory and
running, any of the features of FLEX can be utilized. For example the
disk editor and assembler can be used to develop the remaining software
required for a complete system.
(4) The user will now save his drivers on disk and append them onto the
core of FLEX to produce a complete version of FLEX on the disk.
(5) In order to load the full version of FLEX, a couple of bootstrap
loader routines are required. Once these are written and tested, the
FLEX system is basically complete and may be easily booted up at will.
(6) There is one further routine that must be user supplied which
communicates directly with the disk hardware.
That is the "NEWDISK"
routine which initializes a blank disk to the format required by FLEX.
Page 4 - Section 2

6809 FLEX Adaptation Guide
When the NEWDISK routine is functional, the user has a complete, fully
interfaced version of FLEX!
At this point the user may go back and
upgrade the initial driver packages to include advanced features such as
double-sided double-density disks, printer spooling, hard disks, etc.
Appendices E and F have listings of skeletal bootstrap loader and
NEWDISK routines. The source listings of these routines are also on the
supplied FLEX disks. Once FLEX is running, the user may wish to make
use of these source files as a starting point for his own loader and
NEWDISK routines.
2.3 FLEX Disk Format
There is a defined format for FLEX disks which is essentially IBM floppy
disk compatible, but uses 256 bytes per sector. Track number 0 (the
outermost track) is reserved for system information and directory.
The
remainder is available for user files. Each file may be thought of as a
chain of sectors which are linked together.
This
linking
is
accomplished by placing the track and sector address of the next sector
in the chain into the first two bytes of a sector's data. The third and
fourth bytes of each sector are reserved for a value used in random file
accessing techniques. Thus each data sector on the disk is actually
only capable of holding 252 bytes of user data. The last sector in a
file chain has a forward link (track and sector address) of zero which
marks it as the last sector. All the sectors on the disk which are not
part of a file are linked together in the same fashion as a file, but
are collectively called the "free-chain" and are not treated as a normal
file. The directory, which starts with sector number 5 on track 0, is
also just a chain of sectors. This chain initially contains all the
sectors from number 5 up on track 0, but can grow out onto other tracks
if necessary.
Track 0 sector 3 is called the "System Information
Record" and maintains certain data about the disk such as where the
free-chain is located, the number of sectors per track, the disk name,
etc. Sectors 1 and 2 on track 0 are reserved for a bootstrap loader.
Further details about disk formats for double-sided and double-density
disks may be found in Appendix B.

Page 5 - Section 2

6809 FLEX Adaptation Guide
3.0

The CONSOLE I/O DRIVER PACKAGE

In order to operate FLEX, it is necessary to have a system console or
terminal connected to the computer. This unit can be a CRT terminal,
printing terminal, or most any keyboard/display device. Since this
device can differ from installation to installation, it is necessary
that the user adapt his particular console to FLEX. This adaptation is
done through the Console I/O Driver package or simply the Console
Drivers.
Anytime FLEX must perform input or output to the system
console, it does so by using the routines provided in this package.
As we shall see later, FLEX has the ability to perform printer spooling.
Printer spooling requires the use of interrupts and a hardware interval
timer. This timer can vary from installation to installation as can the
interrupt routine handling procedure. Thus the interrupt handling and
timer control routines must be user supplied. These routines are also
included in what is called the Console I/O Driver package even though
they really are not associated with the console. In this section, we
will merely point out where these interrupt routines are located.
Full
descriptions will be given in a later section. It is not necessary to
have them in order to bring up FLEX and in fact many users will not be
able or will not desire to implement the printer spooling feature.
3.1 Console Driver Routine Descriptions
A small portion of the 8K space where FLEX resides has been set aside
for the Console Drivers. This area begins at $D370 and runs through
$D3E4.
If the user's driver routines do not fit in this space, the
overflow will have to be placed somewhere outside the 8K FLEX area.
To
inform FLEX where each routine begins, there is a table of addresses
located between $D3E5 and $D3FC. This table has 12 two-byte entries,
each entry being the address of a particular routine in the Console I/O
Driver package. It should look something like this:
* CONSOLE I/O DRIVER VECTOR TABLE
INCHNE
IHNDLR
SWIVEC
IRQVEC
TMOFF
TMON
TMINT
MONITR
TINIT
STAT
OUTCH
INCH

ORG
FDB
FDB
FDB
FDB
FDB
FDB
FDB
FDB
FDB
FDB
FDB
FDB

$D3E5
XXXXX
XXXXX
XXXXX
XXXXX
XXXXX
XXXXX
XXXXX
XXXXX
XXXXX
XXXXX
XXXXX
XXXXX

TABLE STARTS AT $D3E5
INPUT CHARACTER W/O ECHO
IRQ INTERRUPT HANDLER
SWI3 VECTOR LOCATION
IRQ VECTOR LOCATION
TIMER OFF ROUTINE
TIMER ON ROUTINE
TIMER INITIALIZATION
MONITOR ENTRY ADDRESS
TERMINAL INITIALIZATION
CHECK TERMINAL STATUS
OUTPUT CHARACTER
INPUT CHARACTER W/ ECHO

The 'XXXXX's represent the address of the particular routine listed.
Page 6 - Section 3

6809 FLEX Adaptation Guide
The individual routines associated with actual console I/O are described
here. Those associated with the timer and interrupts are deferred to a
later section. They will simply be disabled for now.
INCH

Address at $D3FB
This routine should get one ASCII input character from the
terminal and return it in the 'A' accumulator with the parity
bit (the highest order bit) cleared. If no character has been
typed when the routine is started, it must wait for the
character.
The character should also be echoed to the output
device. Only 'A' and the condition codes may be modified.

INCHNE

Address at $D3E5
This routine inputs a single character exactly like the INCH
routine described above with the one exception that it does
NOT echo the input character to the output device.
As with
INCH, only 'A' and the condition codes may be modified.

OUTCH

Address at $D3F9
This routine should output the character found in the 'A'
accumulator to the output' device.
If the output device
requires the parity bit to be cleared, that can be done here.
No registers should be modified except condition codes.

STAT

Address at $D3F7
This routine checks the status of the input device.
That is
to say, it checks to see if a character has been typed on the
keyboard. If so, a Not-Equal condition should be returned (a
subsequent BNE instruction would cause a branch). If no
character has been typed, an Equal to zero condition should be
returned.
No registers may be modified except condition
codes.

TINIT

Address at $D3F5
This routine performs any necessary
initialization
for
terminal I/O to take place. All registers may be destroyed
except for the stack pointer.

MONITR

Address at $D3F3
This is the address to which execution will transfer when FLEX
is exited via the MON command. It is generally the reentry
point of the system's monitor ROM. If no monitor is present,
this address could be set to FLEX's warm start ($CD03) which
effectively nullifies this command.

The remaining routines are all associated with interrupt handling and
timer control for printer spooling.
For now these routines should
simply be disabled.
The three timer control routine vectors (TMINT,
TMON, TMOFF) should point to an RTS instruction. The interrupt handler
routine vector (IHNDLR) should point to an RTI. The two interrupt
vector addresses (SWIVEC and IRQVEC) should point to some area in ROM or
some unused address space such that when FLEX tries to store values into
those points, nothing will happen. An example of these routines may be
found in Appendix G.
Page 7 - Section 3

6809 FLEX Adaptation Guide
3.2 Implementing the Console I/O Driver Routines
At this point, the user should develop the driver routines described
above. The code produced should be entered into the memory spaces
named.
If using a terminal which is interfaced through an ACIA (which is the
preferred type), the code can be identical to that given in the sample
Console Drivers found in Appendix G.
The only change that may be
required would be the address of the ACIA defined in the EQU statement
near the beginning.
Note that it may be possible to utilize I/O routines already contained
in your system's monitor ROM.
If those routines fully meet the
specifications given above, you could simply place the address of each
applicable ROM routine into the vector table.
Once the routines have been entered, test them fully to ensure that they
are functioning properly.

Page 8 - Section 3

6809 FLEX Adaptation Guide
4.0

The DISK DRIVER PACKAGE

All communication between FLEX and the disk hardware controller(s) is
done through a set of 10 routines which comprise the Disk Driver
Package.
The main body or core of FLEX is totally isolated from the
disk controller except via these driver routines. In other words, FLEX
does not care what the disk controller or drives look like. It simply
calls on these routines and expects them to do all interfacing with the
disk hardware.
Since the disk hardware can vary from installation to
installation, the user must supply these disk driver routines for his
particular
system.
They control the very basic, low-level disk
operations associated with reading and writing physical disk sectors.
All file handling and character-at-a-time I/O which FLEX performs is
built upon these simple driver routines.
4.1 The Disk Driver Routines
There is memory set aside for the drivers from DE00 to DFFF hex.
If
necessary, the routines can overflow into other portions of memory such
as the top of the user RAM area or on top of the printer spooling
section of FLEX if that function will not be used. There are hints
later in the manual for where and how to overflow the allotted driver
routine space.
The individual routines can be placed anywhere, but in
order for FLEX to know where they are, a jump table must be defined in
the area from $DE00 to $DE1D. It appears as follows.
*
* DISK DRIVER ROUTINE JUMP TABLE
*
DE00
ORG $DE00
DE00 7E XXXX
READ
JMP XXXXX
Read a single sector
DE03 7E XXXX
WRITE
JMP XXXXX
Write a single sector
DE06 7E XXXX
VERIFY JMP XXXXX
Verify last sector written
DE09 7E XXXX
RESTORE JMP XXXXX
Restore head to track #0
DE0C 7E XXXX
DRIVE
JMP XXXXX
Select the specified drive
DE0F 7E XXXX
CHKRDY JMP XXXXX
Check for drive ready
DE12 7E XXXX
QUICK
JMP XXXXX
Quick check for drive ready
DE15 7E XXXX
INIT
JMP XXXXX
Driver initialize (cold start)
DE18 7E XXXX
WARM
JMP XXXXX
Driver initialize (warm start)
DE1B 7E XXXX
SEEK
JMP XXXXX
Seek to specified track
A full description of each of the above mentioned routines follows.
Each lists the necessary entry parameters and what exit conditions must
exist. Note that "(Z)" represents the Zero condition code bit and "(C)"
represents
the Carry condition code bit.
All other letters in
parentheses represent CPU registers. In most cases the B register is
reserved for "Error Conditions" upon return. If there is no error, the
B register may be.destroyed. The "Error Condition" referred to is the
status returned by a Western Digital 1771 or 1791 floppy disk controller
chip. Those statuses are briefly described here. An error is indicated
by a "1" in the indicated bit position.
Page 9 - Section 4

6809 FLEX Adaptation Guide
BIT
7
6
5
4
3
2
1
0

READ
not ready
0
0
not found
CRC error
lost data
0
0

If the Western Digital chip is
simulated by the user s routines.

WRITE
not ready
write protect
0
not found
CRC error
lost data
0
0
not

used,

OTHER
not ready
write protect
0
seek error
CRC error
0
0
0
these

statuses must be

4.2 Disk Driver Routine Specifications
Each description lists any necessary entry parameters and the proper
state of certain registers on exit. Unless stated otherwise, the 'Y',
'U', and 'S' registers must NOT be altered by any of the routines.
READ

This routine reads the specified sector into memory at the
specified address.
This routine should perform a
seek
operation if necessary. A sector is 256 bytes in length.
ENTRY - (X) = Address in memory where sector is to be placed.
(A) = Track Number
(B) = Sector Number
EXIT - (X) May be destroyed
(A) May be destroyed
(B) = Error condition
(Z) = 1 if no error
= 0 if an error

WRITE

This routine writes the information from the specifed memory
buffer area to the disk sector specified. This routine should
perform a seek operation if necessary. A sector is 256 bytes
in length.
ENTRY - (X) = Address of 256 memory buffer containing data
to be written to disk
(A) = Track Number
(B) = Sector Number
EXIT - (X) May be destroyed
(A) May be destroyed
(B) = Error condition
(Z) = 1 if no error
= 0 if an error

VERIFY

The sector just written to the disk is to be verified to
determine if there are CRC errors. No seek is required as
this routine will only be called immediately after a write
single sector operation.
ENTRY - No entry parameters
EXIT - (X) May be destroyed
(A) May be destroyed
(B) = Error condition
Page 10 - Section 4

6809 FLEX Adaptation Guide
(Z) = 1 if no error
= 0 if an error
RESTORE

A restore operation (also known as a "seek to track 00") is to
be performed on the specified drive. The drive is specified
in the FCB pointed to by the contents of the X register. Note
that the drive number is the 4th byte of the FCB.
This
routine should select the drive before executing the restore
operation.
ENTRY - (X) = FCB address (3,X contains drive number)
EXIT - (X) May be destroyed
(A) May be destroyed
(B) = Error condition
(Z) = 1 if no error
= 0 if an error

DRIVE

The specified drive is to be selected. The drive is specified
in the FCB pointed to by the contents of the X register. Note
that the drive number is the 4th byte of the FCB.
ENTRY - (X) = FCB address (3,X contains drive number)
EXIT - (X) May be destroyed
(A) May be destroyed
(B) = $0F if non-existent drive
= Error condition otherwise
(Z) =1 if no error
=0 if an error
(C) =0 if no error
=1 if an error

CHKRDY

Check for a drive ready condition. The drive number is found
in the specified FCB (at 3,X). If the user's controller turns
the drive motors off after some time delay, this routine
should first check for a drive ready condition and if it is
not ready, should delay long enough for the motors to come up
to speed, then check again. This delay should be done ONLY if
not ready on the first try and ONLY if necessary for the
particular drives and controller!
If the hardware always
leaves the drive motors on, this routine should perform a
single check for drive ready and immediately return the
resulting status.
Systems which do not have the ability to
check for a drive ready condition should simply always return
a ready status if the drive number is valid.
ENTRY - (X) = FCB address (3,X contains drive number)
EXIT - (X) May be destroyed
(A) May be destroyed
(B) = Error condition
(Z) = 1 if drive ready
= 0 if not ready
(C) = 0 if drive ready
= 1 if not ready

Page 11 - Section 4

6809 FLEX Adaptation Guide
QUICK

This routine performs a "quick" drive ready check.
Its
function is exactly like the CHKRDY routine above except that
no delay should be done. If the drive does not give a ready
condition on the first check, a not ready condition is
immediately returned. Entry and exit are as above.

INIT

This routine performs any necessary initialization of the
drivers during cold start (at boot time).
Actually, any
operation which must be done when the system is first booted
can be done here.
ENTRY - No parameters
EXIT - A, B, X, Y, and U may be destroyed

WARM

Performs any necessary functions during FLEX warmstart. FLEX
calls this routine each time it goes thru the warm start
procedure
(after
every command).
As an example, some
controllers use PIA's for communication with the processor.
If FLEX is exited with a CPU reset, these PIA's may also be
reset such that the controller would not function properly
upon
a jump to the FLEX warm start entry point. This routine
could re-initialize the PIA when the warm start was executed.
ENTRY - No parameters
EXIT - A, B, X, Y, and U may be destroyed

SEEK

Seeks to the track specified in the 'A' accumulator. In
double-sided systems, this routine should also select the
correct side depending on the sector number supplied in 'B'.
ENTRY - (A) = Track Number
(B) = Sector Number
EXIT - (X) May be destroyed (See text)
(A) May be destroyed (See text)
(B) = Error condition
(Z) = 1 if no error
= 0 if an error

4.3 Developing the Disk Driver Routines
It should be reiterated that the best approach to use in writing these
disk driver routines is one of simplicity in the beginning. The first
set of drivers written should be for a single-sided, single-density
floppy disk.
Once these drivers are fully functional and FLEX is
up-and-running, it will be much easier to upgrade them to double-sided
or double-density and to add hard disks or whatever.
The READ and WRITE single sector routines are the heart of the Disk
Driver Package. As mentioned, they must perform a seek operation to the
proper track. It will probably be easiest and most efficient to call on
the SEEK routine described above to perform this operation. If this is
the case, it is important that the user ensure that the exit conditions
of the SEEK routine are compatible with the READ and WRITE routines.
For example, it may be desirable for the SEEK routine to preserve the X
register so that READ and WRITE can assume the memory address for the
Page 12 - Section 4

6809 FLEX Adaptation Guide
sector remains intact across a seek call.
The READ and WRITE routines need not be concerned with retries when
errors are encountered.
FLEX
takes
care
of
this
operation
automatically.
CHKRDY and QUICK are used by FLEX to determine if a disk is ready to
carry out some operation. If not, FLEX will report a "drive not ready"
error. Some systems (many minifloppy systems) do not provide the
ability to check for a drive being ready. If this is the case, the best
solution is to simply be sure the drive specified is a valid number and
if so, immediately signal the drive as ready. Thus if a drive is not
actually ready when accessed, it will most likely "hang up" waiting for
a disk to be inserted and the door closed.
In multi-drive systems, it is important that the drivers keep tabs on
which track each drive is left on. This is at least true in the case of
the Western Digital controller chips. On these chips, there is only one
track register and that is for the currently selected drive. If the
user selects another drive and seeks to some track on it, when he comes
back to the first drive he will not know which track he is on. To
overcome this, it will probably be necessary to keep a list of what
track each drive was last on. Whenever the current drive is changed,
the current track for that drive should be saved and the track which the
new drive was last on should be picked up and put in the controller's
actual track register.
The SEEK routine itself should not attempt any reading. Specifically,
it should not attempt to read the sector ID field to determine if it is
actually at the correct track. It simply seeks until it is positioned
over what it thinks is the correct track. If something is wrong and it
is not really on the correct track, the read or write routine will find
out about it and report such an error. Now if this is the case (the
drivers have lost track of what track they are actually on), all should
eventually be corrected by FLEX. When FLEX gets a read or write error
(which may be due to being on the wrong track), it retries several times
on the same track. If none of these tries are successful, FLEX performs
a restore operation and then re-seeks to the specified track. After
re-seeking, FLEX attempts several more reads or writes and if still
unsuccessful, the whole procedure of restoring and re-seeking is
repeated. A total of three such re-seeks and associated retries are
attempted before FLEX finally gives up and reports a read or write
error. It is the restoring and re-seeking that will get the drivers
back on the right track number if they were lost. When a restore
operation is performed, the controller knows exactly which track it is
on (track 0) and can start anew with this correct track number.
If there is enough room, the user may wish to put a check in the SEEK
routine to assure that an illegal track number is not specified. In
such a case, SEEK would have to know what the highest track number
should be and if a supplied track number is greater, an error should be
returned. This error would be a record not found type error.

Page 13 - Section 4

6809 FLEX Adaptation Guide
The RESTORE routine is the only one which must perform a drive select
before carrying out its function (except of course for DRIVE whose
function is to select a drive). All other routines can assume that the
drive has been selected before they were called.
Once the disk driver routines have been written, they should be entered
into memory in the space provided. Also, be sure the jump table is
entered into memory as shown. You should now have a set of Console I/O
Drivers and Disk Drivers in memory. At this point you are ready to test
the routines.
4.4 Overflowing the Disk Driver Area
If the user is unable to fit his disk driver routines in the space
allotted ($DE00 to $DFFF except for the jump table), it is possible to
overflow the routines into other areas.
As long as the jump table
points to the beginning of each routine, they can be placed anywhere in
memory.
Obviously, it would be best if the routines can be fit in the
reserved space. If not, they could overflow into one of three places:
the upper end of user memory, the printer spooler area (if printer
spooling is not implemented), or additional RAM memory placed above
FLEX's $DFFF upper limit.
If the third case is possible. there is
absolutely no problem as that memory would not be used by FLEX or any of
its support software. Using the printer spooler area is a good solution
if the printer spooling feature will not be implemented, but there is
one complication.
FLEX has assembled code in the printer spooler area
and when FLEX is loaded, this code is loaded.
Thus if the user has
placed driver routine code in this area, loading FLEX will overwrite
that code. In later versions of the drivers, this is no real problem
since the drivers will be appended onto the end of the FLEX file. This
means that the drivers would be loaded over the top of any FLEX code if
assembled to the same addresses.
For more information on using the
printer spooler area, see Section 12.
At this stage of the development of FLEX, the best place to overflow the
drivers (assuming there is no RAM above FLEX) is at the top of user
memory. For example, if you have 32K of user memory (besides the 8K for
FLEX), you might reserve 256 bytes from 7F00 to 7FFF for drivers. Since
your initial drivers are stored in memory, this would put the overflow
out of the way such that no code in FLEX will load over your drivers.
One caution about this technique - it requires that a different MEMEND
value be set. For our example, the new MEMEND should be $7EFF.
For
more information on changing the MEMEND value. consult the FLEX Advanced
Programmer's Guide or see Section 12.
These same overflow techniques can also be applied to the Console I/O
Driver Package if necessary.

Page 14 - Section 4

6809 FLEX Adaptation Guide
5.0

TESTING THE DISK DRIVER ROUTINES

Once the disk driver and console I/O driver routines have all been
written and entered into the computer, we are ready to test the driver
routines.
Before doing so, however, it would be wise to save the code
for all the routines onto some mass storage device such as cassette or
paper tape if available.
This will allow you to quickly reload the
routines should something go wrong which wipes out memory.
The user
should attempt to test these driver routines as fully as possible. Some
patience and thoroughness in this step could save a lot of frustration
and delay later.
5.1 Preparing a Disk
At this point we are finally ready to use one of the supplied disks. If
you have read the manual and the yellow disclaimer and feel confident
that you can handle the FLEX adaptation procedure, open the envelope
containing the two disks. The two disks are identical in terms of the
data which has been stored on them. Each contains all the standard FLEX
utility commands and, of course, the core of FLEX itself.
Hopefully,
you will only need one of the disks - the second is provided only as a
backup should the first be destroyed. The intent is that only one of
the two disks be used for all testing and development unless it is
hopelessly destroyed. Note that Section 13 describes how you can
purchase additional General FLEX disks should you destroy both of the
supplied ones.
Select one of the two disks and be certain that it is write-protected.
The first several steps of testing will not require writing anything to
the disk and keeping it write-protected will prevent your routines from
writing when they should
not.
8"
and
5 1/4"
floppies
are
write-protected
in
different
ways.
The
8 inch floppies are
write-protected when a cutout notch on the leading edge of the disk (as
it is inserted into a drive) is left exposed. If the cutout is covered
with a piece of opaque tape, the disk is "write-enabled" or NOT
write-protected.
5 1/4 inch floppies are just the opposite of the 8
inch. 5 1/4 inch disks are write-protected when a cutout notch on the
side of the disk is covered with opaque tape, and they are write-enabled
if the cutout is left exposed. Be sure the disk you are using is
write-protected.
The disk is now ready for use in the ensuing test
procedure.

Page 15 - Section 5

6809 FLEX Adaptation Guide
5.2 Tests Without Using a Supplied Disk
Throughout this section, we will refer to the supplied FLEX disk as the
"FLEX Disk". You should obtain a blank or non-FLEX disk for use in the
testing and we will refer to it as the "Scratch Disk".
Some of the
driver routines can be tested without inserting the FLEX Disk or by
using a Scratch Disk. In particular they are DRIVE, RESTORE, CHKRDY,
QUICK, SEEK, and probably INIT and WARM. Now let's go through the
routines one at a time.
INIT and WARM These routines are not specifically defined for the
general case. Their function depends entirely on what is
required by the particular controller and disks in use. Since
the user defined and developed these routines, it is assumed
the user will be able to determine how they might best be
tested. Indeed, these routines may not even be required for
your particular installation.
DRIVE

The Drive Select routine can probably be tested with no disk
installed whatsoever.
To be sure, however, it is suggested
that a scratch disk be installed during the test.
This
routine is easy to test if the disk drives in use have LED's
or lights which indicate the drive is selected.
If this is
the case, simply write a little routine which calls the DRIVE
routine with the proper entry parameters (see section 4.2) and
then returns to your monitor.
If the routine functions
properly, the light should come on on the selected drive.
Switch back and forth from one drive to the other (if you have
more than one drive) to ensure you can select any connected
drive. If your drives do not have a drive selected indicator,
this routine will be much more difficult to test.
You might
just try calling it and being sure it returns properly. If
so, assume it is working. If it is not, you will find that
out as we proceed.

RESTORE

The Restore routine is a relatively easy routine to test.
It
should be tested with a scratch disk installed in the drive
and the door closed.
Before a restore operation can be
performed on a drive, the desired drive must be selected by
the DRIVE routine.
Thus to test RESTORE, write a short
routine which first calls DRIVE to select the desired drive
and then calls RESTORE to restore the head to track zero. The
proper entry parameters must be setup for these calls as
outlined in section 4.2.
If the
RESTORE
routine
is
functioning properly, you should see the disk drive head move
to the outside edge of the disk (assuming you have removed the
cover on your disk system, of course). If the head is already
at track zero before testing the command, or to retry the
RESTORE
command
after one restore, it is possible to
physically move the head out from track zero.
To do this,
remove the disk, turn off the power to the disk drive, remove
the cover so that the head assembly is exposed, and gently
push the head assembly away from track zero (toward the hub)
with your fingers. The head itself is delicate, so be sure
Page 16 - Section 5

6809 FLEX Adaptation Guide
you are pushing on some solid part of the head assembly (not
the head itself) and do not force it if it resists. Once the
head is away from track zero, power the drive back up and test
the RESTORE routine.
CHKRDY and QUICK These routines simply return a status - either "ready"
or "not ready". They are quite simple to test. To test the
drive "not ready" case, open the door on the drive under test.
To test the drive "ready" case, insert a scratch disk and
close the door. Note that a drive select must be done before
checking the status.
SEEK

The SEEK routine must be tested with a disk installed. The
user should be able to get positive feedback as to whether or
not the routine is functioning properly by watching the
movement of the disk drive head. Before testing seek, it may
be necessary to perform a RESTORE operation. This is to
ensure that the controller is not lost as to which track it is
on.
For example, if the controller track register says it is
on track #6 but the head is actually positioned on track #32,
there could be problems if a seek to track #73 was attempted.
By performing a restore operation, the controller will be able
to get back on track (pun intended) such that the track
register says #0 and the head is actually on track #0. Once a
single restore has been performed, the controller and drivers
should be able to keep up-to-date as to which track they're on
without subsequent restores.
So to test the SEEK routine,
first perform a restore operation, then write a routine to
select the desired drive and then call the SEEK routine with
the proper entry parameters to seek to some random track on
the disk.
Test this routine fully to see that-it seeks
properly in both directions and visually seems to go to the
correct track position.

5.3 Testing the READ Routine
Now we've come to the real thing! Testing the READ routine is perhaps
the most important step in adapting FLEX to your hardware. As mentioned
before, the READ and WRITE single sector routines are the heart of the
whole Disk Driver Package. Your WRITE routine is probably very similar
to your READ routine, so most of the testing you do here will probably
also apply to the WRITE routine without having to actually perform
dangerous disk writes. The READ routine does rely on some other
routines like SEEK, so be certain that they are functioning properly
before testing READ.
For the first time, you will be using a FLEX Disk. As stated earlier,
be certain it is write-protected and that you only use one of the two
supplied disks if possible.

Page 17 - Section 5

6809 FLEX Adaptation Guide
If desired, the READ routine can be tested by writing a short routine to
select the drive and then call the READ routine with the desired entry
paramters.
As a convenience for testing, however, we have provided the
listing for a short single sector test utility appropriately called
"TEST".
This assembled source listing is found in Appendix C. Using
your system's monitor ROM or whatever means you have, enter the code
listed for this program.
TEST assumes that all the Disk Driver and
Console I/O routines are also installed in memory. Once this code is
entered, begin execution of TEST by jumping to location $0100. You
should see a carriage return and line feed output to the console,
followed by this prompt:
F?
This is a prompt for the "Function" desired. The function may be a READ
single sector, a WRITE single sector, or a return to the system monitor.
To perform a READ, type an "R" (upper case); to perform a WRITE, type a
"W" (upper case); to return to the monitor, type any other character.
!!! FOR THE TIME BEING, DO NOT ATTEMPT A WRITE COMMAND (W) !!!
Enter an "R" to do a READ command and TEST should respond with:
D?
This is a prompt for the desired drive number (a single digit from 0
3). After entering a drive number you should be prompted with:

to

T?
Thi
is a prompt for a two-digit, hexadecimal track number. You can
select any track you like, but be sure it is not a higher number than
the number of tracks on the disk. Next you will receive the prompt:
S?
which is a prompt for a two-digit, hexadecimal sector number.
sector number may be given since an error should be returned if
drivers can't find the desired sector.

Any
the

The sector number prompt is the last one, and once entered, the selected
function should be carried out. Under a READ command, if there was no
error, the data from the sector will be. displayed on the console in
hexadecimal.
There will be 16 rows of 16 bytes each. This display can
be examined to see if the data was read correctly. If an error occurs
in the READ operation, instead of displaying data TEST will print:
E=XX
This signifys an Error occurred and the "XX" represents the hexadecimal
value in the 'B' accumulator (the error condition) on return. In either
case, TEST will immediately start all over again with the function
prompt.

Page 18 - Section 5

6809 FLEX Adaptation Guide
With a FLEX Disk inserted, begin by reading sector #01 on track #00.
This is where a bootstrap loader program will reside in the final
system, but for testing purposes this sector has been setup with a
special data pattern. The first byte in the sector is $00, the second
is $01, the third is $02, and so on to the last byte which should be
$FF. Once you are able to read this sector, try other random sectors on
the disk.
You can be certain you have read the correct sector in most
cases by looking at the first two bytes of the data.
In most sectors
these two bytes point to the next sector in the chain of sectors (see
section 2.3). Thus if not the last sector on a track, the first byte
should be the track number and the second byte should be the sector
number plus one. The last sector on the track will have the first byte
equal to the track number plus one and the second byte equal to $01.
The only exception to this is any sector which is at the end of a file's
chain of sectors, at the end of the directory (the last sector on track
#0 on the FLEX Disk), the System Information Record (track #0 sector
#3), or at the end of the free chain (the last sector on a FLEX Disk).
These sectors have zeroes in both bytes one and two. On the FLEX Disk,
any sector which does not have data stored in it (a free sector) should
have all zeroes past bytes one and two.
Test the READ routine thoroughly! Be sure you test the limiting cases
such as the first and last sectors on several tracks, especially on
track #0 and on the last track on the disk. Do not continue with the
FLEX adaptation until you have firmly convinced yourself that the READ
routine and all of the other supporting routines tested are functioning
perfectly!
5.4 Testing the WRITE Routine
Now we come to the most dangerous part of the FLEX adaptation process
the WRITE routine.
If this routine runs wild, portions of data on a
FLEX Disk could be destroyed. For this reason, it is suggested that you
thoroughly examine your WRITE routine code to make certain there are no
visible bugs before running it. Where possible, make sure it does the
same things as the now functioning READ routine (such as seeking and
possibly setting up the controller chip or DMA device).
If the WRITE
routine does fail and that failure causes indiscriminate writing to the
disk, chances are that only one track will be destroyed.
Thus before
switching to the supplied backup FLEX Disk, continue testing the WRITE
routine on the damaged disk by attempting to write to different tracks.
As with the READ routine, the user can develop his own testing procedure
for the WRITE routine or the supplied TEST program can be entered and
used if desired. If the TEST program is used, it differs from the READ
command testing as follows. To perform a WRITE operation the "F?"
prompt should be answered with an upper case 'W'. The subsequent Drive,
Track, and Sector prompts are then answered as before. The data buffer
which should be written to the disk is assumed by TEST to be at $1000.
Before entering TEST to do the WRITE command, the user can go to the 256
bytes found at $1000 and setup whatever data he would like written to
the disk sector. Another method of setting up this data buffer is by
doing a READ command in TEST. The data read from the specified disk

Page 19 - Section 5

6809 FLEX Adaptation Guide
sector is placed into memory at $1000. Thus, after a read operation,
the data is all setup for writing back to the disk. In order that you
do not mess up the data which is stored on the disk, the best method of
testing would be to read some sector with the 'R' function and then
immediately write it back out without changes via the 'W' command.
When the sector number has been given to TEST, it immediately attempts
to write the data to the disk.
If the write procedure functions
properly and there are no errors, TEST will print an "OK" on the screen
and start all over by prompting for another command.
If errors occur
during the write, the same error messages described under the READ
command are given.
For the initial testing of the WRITE command place a scratch disk in a
drive and attempt a write of any data to it. Since your scratch disk is
not likely to be formatted in FLEX's 256 byte format, an error should
result from the attempted write. The point here is to see that the
WRITE routine does peform the seek, load the head, and try to write
data. If the routine is going to blow up it is best that it happen on a
scratch disk and not one of the FLEX disks. Ensure that the routine
properly returns with a valid error code.
Before attempting a write to the FLEX disk, it is important to note that
there is data stored on the disk (FLEX itself as well as several utility
commands) and that almost all the sectors are linked together by the
first two bytes of each sector. Thus when writing to this disk it is
important that you do not write over the data which is presently stored
in a sector or over the link bytes if the sector is empty. This can be
avoided as follows.
There are three sectors on track zero which are
unused on the FLEX Disk. Sectors number one and two are reserved for a
bootstrap loader program and sector number four is reserved on all FLEX
disks for future expansion. These three sectors are not linked to any
other (or don't need to be); thus any desired data can be written to
these sectors. For example, you might read sector #1 on track #0 which
was setup with a special data pattern and attempt to write this data to
sector #4 on track #0. Be sure you do not alter any other sectors on
track zero.
All other sectors on the disk are part of a chain of sectors and their
first two bytes are a link address to the next sector in the chain. If
data is written to any of these sectors, it is imperative that the first
two bytes remain unchanged! You will always be safe to read a sector
and write it back out without changes (safe, that is, if your write
routine functions properly). If you wish to change some of the data to
make sure you actually are writing the sector, do so on a sector which
is empty. The FLEX Disk is not full, only the first several tracks have
files stored on them. If you write to sectors which are on the last few
tracks, you will most likely be writing into free sectors. Initially,
all the free sectors will be filled with zeroes (except, of course, for
the first two link bytes). It will not hurt for you to change any of
the zero bytes in a free sector and they may be left non-zero after
testing.

Page 20 - Section 5

6809 FLEX Adaptation Guide
Now you are ready to attempt writing to a supplied FLEX disk.
Remove
the write-protection from the disk (cover the cutout on an 8 inch disk;
uncover the cutout on a 5 1/4 inch disk) and insert it in a drive.
Perform several write commands as outlined above. After writing a
sector, the data should always be read back to be certain that it was
actually written as desired. Firmly convince yourself that your WRITE
single sector routine is functioning exactly as it should.
5.5 Testing the VERIFY Routine
The VERIFY routine is a difficult one to test. VERIFY is only called by
FLEX directly after performing a WRITE single sector operation. If the
write operation functioned properly and didn't report an error, then
chances are the VERIFY routine will not find an error in the data. It
is used as a security measure to guarantee that all data is valid.
Since VERIFY won't likely find an error, it is difficult to test to see
if it really would report an error.
It is recommended that you
basically assume VERIFY to be OK and skip thorough testing of it. Do
try calling it directly after doing a single sector WRITE operation to
see that it returns properly and reports no error. If it does that,
simply assume it to be functional. The VERIFY routine will probably be
very similar to the READ routine anyway, with the exception of what is
done with the data. READ places the 256 bytes into memory; VERIFY tests
to be sure they can be read and simply discards them if so. If your
READ and VERIFY routines are similar, this is more justification to
assume the VERIFY routine is good.

Page 21 - Section 5

6809 FLEX Adaptation Guide
6.0

BRINGUP UP THE INITIAL VERSION OF FLEX

At this point, all the driver routines for the Console I/O Driver
package and the Disk Driver package should have been written, fully
debugged, and should be resident in memory. If possible, these routines
should be saved onto some mass storage device such as cassette or paper
tape for quick reloading should problems arise. We are now ready to
load up FLEX and, using these driver routines, test the operation of the
entire operating system.
6.1 Loading FLEX with QLOAD
A short program has been supplied to load the core of FLEX from the disk
into its place in memory.
The program is called 'QLOAD' for Quick
Loader and is listed in Appendix D.
The code for QLOAD should be
entered into memory at $C100 as given in the assembled listing. QLOAD
is really a complete FLEX file loader that directly calls upon the
routines in the Disk Driver Package. It differs from loaders that we
will use later in that it assumes that the file it is to load is stored
on the disk beginning with sector #1 on track #1. On the supplied FLEX
disks, the file which begins there is called "FLEX.COR". This file is
the main body or "core" of FLEX as the filename extension implies. It
contains everything FLEX needs to run in a system except for the Disk
Drivers and the Console I/O Drivers.
Since we already have these
drivers in memory, we need only load FLEX.COR by using QLOAD in order to
run our first version of FLEX.
Once the code for QLOAD has been entered, write-protect a
FLEX Disk,
insert it into drive #0, and jump to location $C100 which is the
starting address of QLOAD. If all works well, QLOAD should read the
file from the disk and jump to your system monitor. The FLEX.COR file
is over twenty sectors in length, so it will probably take a couple of
seconds to read.
If QLOAD does not perform as described, reload your
drivers, carefully check the QLOAD program code in memory, and try
again. If it still fails, there may be something wrong in your drivers.
If the load does take place, and QLOAD returns control to your system
monitor, you are ready to begin execution of FLEX. This is done by
jumping to $CD00. At $CD00 there is a short initialization routine
which sets up several pointers for FLEX, checks to see how much memory
is in the system, and then prompts for the date.
After the date has
been entered, the disk in drive #0 is scanned for a file called
"STARTUP.TXT" as explained in the FLEX User's Guide.
There is no
startup file on the supplied disks, so the initialization routine will
finally jump to FLEX's warm start address and you will receive the three
plus-sign prompt. If FLEX does not come up for you, you either did not
actually get a complete load of FLEX or there still may be errors in
your drivers. In either case, you would have to go back and try again.

Page 22 - Section 6

6809 FLEX Adaptation Guide
6.2 Testing FLEX with Read-Only Commands
Assuming FLEX loaded OK and you received the three plus-sign prompt, you
are now ready to use FLEX.
The first tests should only involve
operations which perform reads from the disk.
Do not attempt any
writing until you are convinced the reads are functioning. You can be
sure you are only reading by leaving the disk write-protected. That way
if you do inadvertently attempt a write, the disk will be protected.
The best method of testing the read operations of FLEX is to simply sit
down and begin executing commands which perform reads.
Some of these
commands are CAT, ASN, DATE, LIST, TTYSET, and VERSION. For proper
syntax and use of these commands, read the FLEX User's Guide.
To use
the LIST command you might try the following:
+++LIST 0.ERRORS.SYS
This should list
error messages.

the

system

error file which contains all of FLEX's

6.3 Testing FLEX with Write Commands
Now you are ready to use FLEX to write information on the disk.
Remove
the write-protection from a supplied FLEX disk and insert it into drive
#0. A convenient method of writing some information into a sector is to
create a short text file using the BUILD command. Read over the
description of that command and when understood, type the following
command to FLEX:
+++BUILD JUNK
FLEX should perform some disk activity associated with loading the BUILD
command and preparing a file called 'JUNK.TXT' and then print BUILD's
prompt which is an equals sign ('='). When that prompt is received,
type a short line of text as follows:
=THIS IS A FILE CALLED JUNK.
When a carriage return is hit after typing the period, FLEX should load
the head and perform some disk activity. This is actually where FLEX is
opening the file called JUNK. If all goes well, you should receive
another equals sign prompt almost immediately. Type three more lines in
like this:
=THIS IS THE SECOND LINE.
=THIS IS THE THIRD AND FINAL LINE.
=#
When the last carriage return is hit (after the pound sign), FLEX will
attempt to write the three lines of data to the file and proceed to
close it. If everything works, you should see FLEX's prompt ('+++')
after a second or two. Do a CAT command on the disk to see if the file
'JUNK.TXT' was placed in the directory. Now view the contents of that
Page 23 - Section 6

6809 FLEX Adaptation Guide
file by executing a list command like this:
+++LIST JUNK
You should see the three lines typed into JUNK displayed on the console.
If this test of BUILD all went as described, you are well on your way to
finishing the FLEX adaptation! If things did not work as described, you
will have to go back and look for bugs in your routines. Your FLEX disk
may be destroyed and it may be necessary to break out the second FLEX
disk supplied.
6.4 Using this Version of FLEX
Assuming that all the functions of FLEX have been tested to the best of
your ability and that no problems have arisen, you may now wish to use
this version of FLEX in the remainder of the adaptation process.
The
utilities included with FLEX include a disk editor and assembler. These
will save you much time if you have been assembling code by hand.

Page 24 - Section 6

6809 FLEX Adaptation Guide
7.0 PREPARING A BOOTABLE VERSION OF FLEX

The only version of FLEX itself on the supplied disks is the file,
FLEX.COR. This file is the core of FLEX and does not contain any disk
or console drivers.
The final version of FLEX on a disk which may be
"bootstrap loaded" must also contain the disk and console driver
routines.
In this section we will create a new file on the disk called
"FLEX.SYS" which contains the core of FLEX and all the driver routines.
Of course in order to do this, the FLEX setup in memory in section 6
must be running properly. All we need do is save the two driver
packages on disk as two files and then append them onto the FLEX.COR
file. These steps can all be accomplished with simple FLEX commands.
The first step is to save the code for your Disk Driver routines as a
file called 'DISK.BIN'. This is done with the following FLEX command:
+++SAVE DISK,<SSSS>,<EEEE>
Where <SSSS> and <EEEE> represent the Starting and Ending addresses of
your Disk Drivers code. After executing the command you might double
check that the file was really saved by doing a CAT command and making
sure there is a file called 'DISK.BIN'.
Next, save your Console I/O Driver routines
'CONSOLE.BIN' with the following command:

in

a

file

called

+++SAVE CONSOLE,<SSSS>,<EEEE>,CD00
where <SSSS> and <EEEE> represent the Starting and Ending addresses of
your Console I/O Drivers code. The 'CD00' is a "transfer address" for
the file. A transfer address is an address saved with a binary file to
tell it where to begin execution. The final version of FLEX is just a
standard binary file on the disk and as such must have a transfer
address so the bootstrap loader will know where to begin execution once
FLEX has been loaded. Since we are going to append the CONSOLE file
(and DISK file) onto the core of FLEX, this transfer address will
eventually get into the final, bootable version of FLEX. Perform a CAT
@ommand to be sure that the CONSOLE.BIN file now exists on the disk.
The APPEND command in FLEX allows two or more files to be appended
together to create a new file. We can use it to prepare our final,
bootable version of FLEX with the following command:
+++APPEND FLEX.COR,DISK.BIN,CONSOLE.BIN,FLEX.SYS
If all goes well, you should now have a file called 'FLEX.SYS' on the
disk. It is a complete version of FLEX which you will be able to boot
up after completing the next section.

Page 25 - Section 7

6809 FLEX Adaptation Guide
8.0

BOOTSTRAP LOADING OF FLEX

At this point, the user should have a fully functional version of the
FLEX Disk Operating System stored on disk. Now you are faced with the
problem of loading that operating system into memory and beginning
execution of it. Generally, loading FLEX will be the first thing done
after powering the computer on, but short of loading all the Disk and
Console driver routines along with the QLOAD we have no way of
performing this load. That is where a "bootstrap loader" is needed. In
this section the user will be instructed to write a bootstrap loader for
his system.
8.1 The Concept of Bootstrap Loading
The problem we face is obvious. When the computer is first powered on,
FLEX is not resident and there is no way of loading it. The solution is
to write a short program whose only purpose is to load FLEX and begin
execution of it.
This type of program is referred to as a "bootstrap
loader" since the system is essentially "pulling itself up by its
bootstraps".
Once this bootstrap loader has been developed, it can be
used to load FLEX. However, we still have the same problem - how do we
get
the
bootstrap loader into the computer after powering on?
Fortunately, this problem is not as great since the bootstrap program is
much smaller than FLEX. There are three obvious solutions.
1) The bootstrap program could be hand-entered each time the
system was powered on.
2) The bootstrap program could be loaded from cassette or paper
tape each time the system was powered on.
3) The bootstrap program could be entirely stored in ROM.
The first two are obviously very undesirable. The third is feasible,
but a typical bootstrap program will be close to 256 bytes and this
might be considered a waste of ROM space.
There is another solution which is not quite so obvious, but which is
perhaps the best and most used solution. That is to use a two-stage
booting process. The idea is to put the bootstrap loader which we have
been discussing on the disk and then write another dumb, very short
bootstrap program to read in the intelligent FLEX bootstrap loader.
This dumb bootstrap program should be very small since it will only have
to read in one sector which is defined to contain the intelligent FLEX
bootstrap loader (assuming that loader fits in 256 bytes or one sector).
On a FLEX disk, this defined boot program sector is sector #1 on track
#0. If absolutely necessary, the boot can overflow onto sector #2 which
has also been reserved. Since the dumb bootstrap program is so short it
is now feasible to place it in ROM.

Page 26 - Section 8

6809 FLEX Adaptation Guide
Before going any further. let's review some nomenclature.
Throughout
the manual when "booting FLEX", "booting up", or simply "booting" is
mentioned, it refers to the entire procedure of loading FLEX which
involves the two stages of bootstrap loading. To avoid confusion in the
remainder of this section, we must come up with a way to differentiate
between the two bootstrap programs or operations. When we refer to the
intelligent bootstrap program which resides on disk and which loads
FLEX, we will use the term "FLEX loader" or simply "loader". The dumb
bootstrap program which resides in ROM we shall refer to as the "ROM
boot".
8.2 Writing a "ROM Boot" Program
The ROM boot program can be written and debugged before writing the FLEX
loader. Assuming the FLEX loader will fit in one sector (256 bytes or
less), our ROM boot will only have to read sector #1 from track #0 into
memory and then jump to the beginning of the loader.
One thing that
makes this ROM boot short and simple is that no seeking operation need
be done. Since the only sector to be read is on track #0, a restore
operation can be performed to get there. Thus the basic steps to be
performed by the ROM boot program are:
1) Select drive #0
2) Do a restore to track #0 operation
3) Read sector #1 into memory at $C100
4) Jump to $C100
As can be seen, the FLEX loader which we are reading is assumed to be
assembled for operation at $C100. That loader will assume that the ROM
boot has already selected drive #0, so don't de-select the drive before
jumping to $C100.
At this point the user should develop his ROM boot program. Note that
the FLEX editor and assembler can be used for this work. An example of
a ROM boot program may be seen in Appendix G. The ROM boot program can
be located anywhere outside the 8K reserved for FLEX.
It may be
advantageous to initially assemble the boot somewhere in low memory
(like $0100) for testing purposes and when debugged, reassemble it to
some high address for burning into ROM. For testing purposes, it is
suggested that step 4 in the instructions above should be changed to a
jump to your monitor. Thus you could execute the ROM boot which when
finished would return to your monitor. This would allow you to use your
system monitor to examine the 256 bytes at $C100 to be sure you are
actually reading the correct data in from the disk. In any event the
data you read will not yet be a valid FLEX loader program and you will
therefore not want to attempt to execute it.

Page 27 - Section 8

6809 FLEX Adaptation Guide
When you are convinced that the ROM boot is functioning properly, save
the code on tape or on disk using the SAVE command. It should not be
burned into ROM until actually tested with the FLEX loader on disk. We
will test this ROM boot further after the FLEX loader has been written.
8.3 Writing a "FLEX Loader" Program
The sole purpose of the FLEX Loader is to load FLEX from the disk and
begin its execution. This is actually a simple file loader since FLEX
resides on the disk just like any other file. The only major difference
in this FLEX loader and the standard file load routine used within FLEX
is that no filename is specified. Instead, it is assumed that the FLEX
loader already knows where FLEX resides on the disk when called.
Specifically, the FLEX loader (which resides at $C100) assumes that the
track and sector location of FLEX is at $C105 and $C106 respectively.
Since FLEX can reside anywhere on the disk, we need a way to tell the
FLEX loader just exactly where FLEX is on the particular disk in use.
That is the function of the LINK command found in FLEX.
It looks up
FLEX in the directory to find the starting track and sector and writes
this information into the sixth and seventh bytes of track #0 sector #1.
When the FLEX loader is read in from that sector, those two bytes will
be placed at $C105 and $C106 and the loader thus knows exactly where to
go to get FLEX.
Now that you know how the FLEX loader works, it is time to write one.
Actually, most of the writing has already been done for you. The
skeletal FLEX Loader program listed in Appendix E has the entire loader
with the exception of a single sector read routine. The loader resides
at $C100. The user need only replace the READ routine found in that
listing with one of his own writing. This single sector read routine
should be almost exactly like the one developed for the Disk Driver
Package.
It is called with the track and sector numbers in 'A' and 'B'
and the address of where to read the data into memory in 'X'.
A
NOT-EQUAL status should be returned if an error occurred. Note that no
error code need be returned in the 'B' register. If there is an error,
the FLEX loader will just start all over with the loading process. If
there was no error, the routine should return an EQUAL status.
Note
that the read routine is responsible for any necessary track seeking.
There are around 128 bytes of space for this read sector routine. If at
all possible the user should fit the read sector routine within this
space so that the entire FLEX loader will fit in one sector. If this is
not possible see section 8.4.
Once the user has developed his-FLEX loader routine and has the code
residing at $C100, it can be put onto the disk on track #0 sector #1 by
use of the PUTLDR command found on the FLEX Disk. The syntax for the
command is quite simply:
+++PUTLDR

Page 28 - Section 8

6809 FLEX Adaptation Guide
It assumes that there is a 256 byte (or less) loader program resident in
memory at $C100. PUTLDR simply writes this data out to sector #1 of
track #0. As described earlier, we must now tell the FLEX loader where
FLEX resides. This is done with the LINK command as follows:
+++LINK FLEX
This assumes your final version of FLEX (which includes all the drivers)
has been called FLEX.SYS. The LINK command will look up FLEX.SYS in the
directory, find its starting address, and write the starting track and
sector number into the sixth and seventh bytes of the FLEX loader in
track #0 sector #1.
Your FLEX disk is now ready for booting or at least for testing prior to
booting. Reload the ROM boot you prepared earlier and execute it with
the FLEX disk in drive #0. It should pull the FLEX loader into memory
at $C100 and jump to it. The FLEX loader should then in turn load and
execute FLEX. If this process does not take place, you probably have an
error in your FLEX loader and will have to redo your code.
Once you have the boot operation working properly such that you can
bring FLEX up having only the ROM boot program in memory, you should
reassemble the ROM boot to a convenient location and burn it into PROM.
When this is done, you will have a complete, bootable version of FLEX
ready for normal use!
8.4 Hints on a Two Sector FLEX Loader
If you were able to fit your FLEX loader program into 2@6 bytes or one
sector, you can skip this section completely.
If not, you should
attempt to develop a FLEX loader that will fit in 512 bytes or 2
sectors. If you can do this, the loader can be stored on track #0
sectors #1 and 2. Sector #2 on track #0 has been reserved for just this
purpose. You will have to write your own routine to write the loader to
these two sectors however, since the supplied PUTLDR command only writes
256 bytes. The other problem is that the ROM boot must now be able to
read both sectors from the disk. This can certainly be done, it just
means that your ROM boot will take up more space. If the ROM boot ends
up being very large, you may decide it is just as easy to put the entire
FLEX loader in ROM and execute it directly without having to load it
from disk with a ROM boot.

Page 29 - Section 8

6809 FLEX Adaptation Guide
9.0

THE NEWDISK ROUTINE

FLEX has its own defined format for diskettes.
All disks must be
prepared with this format before they can be used by FLEX. One
distinguishing characteristic of the FLEX format is that FLEX uses 256
byte sectors. This fact along with the necessity of setting up special
information on FLEX disks requires that all disks be formatted or
initialized with the FLEX format before use.
This initialization
procedure is done with the "NEWDISK" command. Since the NEWDISK command
deals directly with the disk controller to write entire tracks of data,
it must be user supplied. If the disk controller in use is either a
Western Digital 1771 or 1791 based floppy disk controller, the supplied
skeletal NEWDISK routine in Appendix F can be used with only minor
modifications. If not, the skeletal NEWDISK may be used as a guide, but
the user's NEWDISK routine will have to essentially be written from the
ground up.
The NEWDISK routine is not a simple one and may take
considerable effort to develop. It is, however, essential to the use of
FLEX.
9.1 The General NEWDISK Procedure
Let us begin by discussing the actual functions of a NEWDISK routine.
They are six in number:
1) Formatting a blank disk with 256 byte sectors linked together
by the first two bytes of data in each.
2) Testing all the sectors written and removing any bad sectors
by altering their links such that they are removed from the
free chain.
3) Establishing the end of the free chain by writing a forward
link of 0.
4) Initializing the directory on track #0.
5) Setting up the required information in the System Information
Record (sector #3 on track #0).
6) Storing the FLEX boot loader program on track #0 sector #1.
Now let's discuss each step in more detail.
9.1.1 Formatting the disk with 256 byte sectors.
This step is the most difficult part of the NEWDISK process.
Each track must be written so that there are a certain number
of 256 byte sectors on each track. With most controllers it
is necessary for such a routine to do all the track setup
including gaps, sector ID fields, data fields, and CRC values.
The actual data in each sector is really not critical. IBM
puts a hex E5 in each byte, Technical Systems Consultants
generally puts zeroes in each byte. This step of the NEWDISK
routine is also where all the sector linking takes place.
As
discussed previously, all the sectors are linked together by
addresses stored in the first two bytes of the data field of
Page 30 - Section 9

6809 FLEX Adaptation Guide
each sector.
The first byte is the track on which the next
sector in the chain is found, and the second byte is the
sector number of the next sector on that track. For example,
the first two data bytes of sector #1 on track #1 should be
$01 and $02 which says the next sector in the chain is on
track number $01 and sector number $02.
If a disk has 15
($0F) sectors on each track, the last sector on track #1
(sector #15) should have $02 and $01 as its first two data
bytes.
This means the next sector in the chain is on track
number $02 and sector number $01. When this step is complete,
you should have a disk with one long chain of linked sectors
beginning with sector #1 on track #0 and ending with the last
sector on the last track. It may be desirable to implement
"sector interleaving" in this formatting step.
See section
9.4 for a description of this technique.
9.1.2 Testing and removing bad sectors.
This step is intended to verify that all the sectors written
in the first step can be properly read. This simply requires
attempting to read every sector on the disk and checking for
errors. If there are no errors, this step is complete.
If
there are bad sectors found on track #0 and the sector number
is #5 or less, a fatal error should be reported and the
NEWDISK routine aborted. If bad sectors are found elsewhere,
they should be linked out of the chain of sectors. This means
the forward link in the sector preceding the bad one should be
changed so that it points to the next sector after the bad
one. This is not a trivial task if the bad sector is the last
one on a track or if there are two bad sectors in a row.
Before starting this check for bad sectors, you should have a
count of the number of data sectors on the disk. Data sectors
are all sectors except those on track #0. As bad data sectors
are found and effectively removed by the re-linking process,
this count of total data sectors should be decremented. In
the end, this count will be placed in the System Information
Record so that FLEX can know when a disk is full.
9.1.3 Establishing the end of the free chain.
The
end of the free chain of data sectors is easily
established by changing the forward link (first two data
bytes) of the last good sector on the disk to zeroes. The
single sector read and write routines from FLEX can be used
for this purpose.
9.1.4 Initializing the directory.
The directory starts with sector #5 on track #0 and initially
ends with the last sector on track #0.
This step should
establish the end of the chain of directory sectors by
changing the forward link of the last good sector on track #0
to zeroes.
The 252 data bytes in all directory sectors must
also be zeroes. The single sector read and write routines

Page 31 - Section 9

6809 FLEX Adaptation Guide
from FLEX can be used for these purposes.
9.1.5 Setting up the System Information Record (SIR).
The SIR contains specific information about the disk which
should be setup by this step. Each item of information stored
in the SIR has a defined offset or location within the sector.
The following table gives the beginning and ending offset of
each piece of information in decimal. Note that the first
byte of the SIR is an offset of 0.
Begin
0
16
27
29
31
33
35
38
39

End
1
26
28
30
32
34
37
38
39

Information
Two bytes of zeroes (Clears forward link)
Volume name in ASCII
Volume number in binary
Address of first data sector (Track-Sector)
Address of last data sector (Track-Sector)
Total number of data sectors in binary
Current date (Month-Day-Year) in binary
Highest track number on disk in binary
Highest sector number on a track in binary

The volume name and number are arbitrary as supplied by the
user. If they weren't bad, the first and last data sectors
will be sector #1 on track #1 and the last sector on the last
track. The total number of available data sectors does not
include any sectors from track #0. The highest track number
is the actual number of the last track.
For example, there
are 77 tracks on a standard eight inch disk but since the
first one is numbered as #0, the highest track number would be
#76 or hex 4C.
9.1.6 Storing the FLEX boot loader on the disk.
So that any disk can be used for booting purposes, we must
have the FLEX loader program stored on track #0 sector #1.
The NEWDISK routine is a logical place to do this, although
this step may be omitted if the disk will not be used for
booting.
A convenient way to store the loader on disk is to
let NEWDISK assume that the loader is in memory at $C100.
Thus NEWDISK need only write a single sector of data to sector
#1 on track #0 beginning at $C100.
The actual FLEX loader
program can then be simply appended onto the NEWDISK program
so that whenever NEWDISK is loaded, the FLEX loader code is
also loaded.
Of course, if your FLEX loader is larger than
256 bytes, you would have to save two sectors on the disk.

Page 32 - Section 9

6809 FLEX Adaptation Guide
9.2 A Western Digital NEWDISK Example
If your disk controller hardware utilizes either a Western Digital 1771
or 1791 floppy disk controller chip, you should be able to use the
skeletal NEWDISK supplied in Appendix F and on the supplied FLEX disks.
The only part of this skeletal NEWDISK which must be added is the Write
Track routine near the end. A full specification of the write track
routine is give.n in the listing comments.
This NEWDISK will write 256 bytes of data found at $C100 onto the disk
after it is formatted. It is assuming that a FLEX loader program is
resident in that memory area when NEWDISK is executed.
For testing
purposes, it is not necessary that any meaningful data be at location
$C100. NEWDISK will still write the data to disk, but since you are
only in a testing stage and will not be attempting to boot from the new
disk, it makes no difference what is on track #0 sector #1.
When you
finally have NEWDISK working, you can add the FLEX loader routine to be
saved on disk. Assuming you have the FLEX loader code in a binary file
on disk, the easiest way to put it and NEWDISK together is with the
APPEND command. Thus when this appended version of NEWDISK is loaded,
the FLEX loader will'also be loaded into the $C100 area. The command to
do this appending should look something like this:
+++APPEND NEWDISK.BIN,LOADER.BIN,NEWDISK.CMD
where the version of NEWDISK you have been working on is assumed to be
called NEWDISK.BIN and the FLEX loader file is called LOADER.BIN. The
resulting file is a completed NEWDISK ready for use and is called
NEWDISK.CMD.
9.3 Hints on a Non-Western Digital NEWDISK
If the user does not have a Western Digital based disk controller, he
will essentially have to write his NEWDISK from the ground up using the
description given in section 9.1. It may be helpful to use the Western
Digital NEWDISK found in Appendix F as a guide.
There is a large
section of that sample which can be used in a non-Western Digital
NEWDISK.
There are two major sections to the skeletal NEWDISK. The first
actually does the disk formatting as described in section 9.1.1.
It
calls on the Write Track routine documented in the NEWDISK listing.
This section can probably not be used at all in a non-Western Digital
NEWDISK.
The second section performs steps 2 through 6 as described in
section 9.1. It can probably be used as is in any NEWDISK the user may
write.
The only changes will probably be the locations from where the
values written into the SIR are picked up.

Page 33 - Section 9

6809 FLEX Adaptation Guide
9.4 Sector Interleaving
Sector interleaving is a technique which can be applied to floppy disks
to maximize the speed with which sequential disk data can be read. For
the most part, files are stored in contiguous groups of sectors on a
disk. For example, a file may occupy six sectors on a single track with
numbers 3 through 8. If this file was read by FLEX, sector 3 would be
read first, followed by sector 4, then sector 5, etc. If these sectors
are physically sequential on the disk, we would see a phenomenon often
referred to as "missing revolutions". This is a consequence of FLEX not
being able to read all the sectors in one revolution of the disk.
It
takes a certain amount of time for the data to be handled by FLEX and
the address of the next sector to be readied. In this time, the next
physical sector or sectors after the one just read will have already
passed the read head. In fact, our hypothetical 6 sector file would
require 6 revolutions of the disk to read. Now with a disk spinning at
360 RPM this may not sound like much, but it does add up and is very
noticeable.
A simple solution to this problem is sector interleaving.
This refers
to the technique of placing the sectors on a track in an order which is
not physically contiguous. In other words, while the first physical
sector on the track may be numbered as #1, the second physical sector
would not be #2. Sector number 2 (the second "logical" sector) will be
placed a few physical sectors away from the first logical sector so that
FLEX has time to do its processing before that sector comes under the
read head.
Thus logical sector number 2 may be put in physical sector
number 6. The logical sectors are thus "interleaved".
The distance (number of physical sectors) between logical sectors for
maximum performance is dependant on several factors.
These factors
include how fast the disk is rotating, how many sectors are on a track,
and most importantly whether the user wishes to optimize the system for
reading or writing and whether for binary or text files since it takes
different times for FLEX to process the data.
The distance or
interleaving amount used is best found by experimentation. Technical
Systems Consultants usually formats disks with interleaving optimized
for reading text files. As an example, the following are interleaving
schemes used by Technical Systems Consultants
for
single-sided,
single-density 8 and 5 1/4 inch disks.

Page 34 - Section 9

6809 FLEX Adaptation Guide
Eight inch disk
physical
logical
sector #
sector #
1
1
2
6
3
11
4
3
5
8
6
13
7
5
8
10
9
15
10
2
11
7
12
12
13
4
14
9
15
14

Five inch disk
physial
logical
sector # sector #
1
1
2
3
3
5
4
7
5
9
6
2
7
4
8
6
9
8
10
10

The user may want
to experiment
with
different
configurations to determine the best setup for his needs.

Page 35 - Section 9

interleaving

6809 FLEX Adaptation Guide
10.0

PRINTER SPOOLING and INTERRUPT HANDLING

Printer spooling is a term which refers to the process of sending a disk
file to the printer for output while other use is being made of the
system. In effect, this is a dedicated multi-tasking operation.
There
are two dedicated tasks: the normal operation of FLEX and the spooling
of a disk file out to a printer. Normally only the first of these two
tasks is being executed, that being the normal running of FLEX.
However, when a PRINT command is executed under FLEX, the second task is
started and both tasks appear to be running at the same time. In
actuality there must be a hardware interval timer in the system capable
of producing interrupts. The PRINT command starts the printer spooling
process and turns this timer on. Basically what happens from there is
that each time an interrupt comes through, FLEX switches to the other
task so that both appear to be occurring simultaneously.
This section
covers the implementation of this printer spooling feature and the
interrupt handling required.
10.1 Hardware Requirements
As mentioned, the system must have a hardware interval timer capable of
producing interrupts in order to implement printer spooling. The
interrupts produced must be IRQ type interrupts.
This timer must be
able to be turned on or off by the system under software control (either
producing interrupts or not). The routines for controlling this timer
must be user supplied and are discussed in section 10.3.
The time interval between interrupts can vary considerably, but a
recommended value is 10 milliseconds.
If the printer in use is a
buffered parallel type printer, this interval can be higher but should
not go over 100 milliseconds.
10.2 Firmware Requirements
If printer spooling is to be implemented, FLEX must obviously have
control of the interrupts. Both the IRQ and the SWI3 interrupts are
used, the IRQ's coming from the hardware timer and the SWI3's coming
from FLEX software and drivers. FLEX requires that there be a specific
location in RAM memory for each interrupt into which the address of an
interrupt handling routine can be stored. These locations could be the
actual interrupt vectors for the CPU, but generally the system's monitor
ROM has defined locations in lower RAM where the interrupt handling
routine vectors can be stored.

Page 36 - Section 10

6809 FLEX Adaptation Guide
10.3 Additional Console I/O Drivers for Printer Spooling
In order to implement the printer spooling feature, it is necessary to
complete the remaining routines in the Console I/O Driver Package.
These are the routines associated with controlling the timer and
handling the interrupts. There is an entry for the address of each of
these routines in the Console I/O Driver package's vector table as seen
in Section 3.
TMINT

Address at $D3F1
This routine performs any necessary initialization for
interrupt timer used by the printer tpooling process.
registers may be modified.

the
Any

TMON

Address at $D3EF
This routines "turns the timer on" or in other words starts
the interval IRQ interrupts. Any registers may be modified.

TMOFF

Address at $D3ED
This routine "turns the timer off" or in other words stops the
interval IRQ interrupts. Any registers may be modified.

IRQVEC

Address at $D3EB
The IRQ vector is the address of a two byte location in RAM
where FLEX can stuff the address of its IRQ interrupt handler
routine. In other words, when an IRQ interrupt occurs control
should be transferred to the address stored at the location
specified by the IRQ vector.
This IRQ vector location
(address) should be placed in the Console I/O Driver vector
table.

SWIVEC

Address at $D3E9
The SWI3 vector is the address of a two byte location in RAM
where FLEX can stuff the address of its SWI3 interrupt handler
routine. In other words, when an SWI3 interrupt occurs
control should be transferred to the address stored at the
location specified by the SW13 vector.
This SWI3 vector
location (address) should be placed in the Console I/O Driver
vector table.

IHNDLR

Address at $D3E7
The Interrupt Handler routine is the one which will be
executed when an IRQ interrupt occurs.
If using printer
spooling, the routine should first clear the
interrupt
condition and then jump to the 'change process' routine of the
printer spooler at $C700. If not using printer spooling, this
routine can be setup to do whatever the user desires. If it
is desirable to do both printer spooling and have IRQ's from
another device (besides,the spooler timer), this routine would
have to determine which device had caused the interrupt and
handle it accordingly.

Page 37 - Section 10

6809 FLEX Adaptation Guide
10.4 Disk Driver Changes for Printer Spooling
There is one set of changes which should be added to your disk driver
routines if printer spooling is implemented. As described earlier, when
printer spooling it taking place, FLEX is essentially a two task system.
Now for the best possible performance and to ensure that FLEX does not
miss characters typed on the console while it is busy printing, the
printer task should have less priority than the task which is the
running of FLEX. One way to give the printer task less priority is to
never wait for disk operations to take place while executing the printer
task.
For example, if we are currently running the printer task (the
FLEX task is inactive) and it is necessary to read a sector of data from
the file to be printed, we should not wait for the sector read operation
to take place. Instead we should initiate the sector read and then
immediately switch back to the FLEX task. This switch to the other task
is performed with a software interrupt (SWI3). The drivers can tell if
they are running the printer task by checking a byte called PRCNT at
$CC34. If non-zero, the printer task is the one currently executing.
Thus, the code which must be added to the drivers should look something
like this:

CONTIN

TST PRCNT
BEQ CONTIN
SWI3
...

EXECUTING PRINTER TASK?
SKIP IF NOT PRINTING
IF PRINTING, SWITCH TASKS
CONTINUE WITH OPERATION

This test should be placed just before each point in your drivers which
could possibly take a long time to execute. The following points are
likely candidates for this test:
1) A sector read operation
2) A sector write'operation
3) A seek operation
4) The delay in CHKRDY (if there is one)
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

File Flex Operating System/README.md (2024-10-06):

# Flex Operating System
## Drivrutiner och annat för att kunna starta RT-datorn
RT-datorn, både den gamla (i 6809 läge) och den nya, ska köra FLEX 9.1 eller FLEX 3.01.  
Då original FLEX 9.1 kör I/O via serieporten på adress $E004/$E005 fungerar detta inte på RT-datorn.  
En Quick-And-Dirty lösning är att boota FLEX 9.1, vänta tills diskettstationen slocknat + 5 sekunder.  
Tryck sedan Reset för att komma in i CBUG-monitor.  
Tryck D för att dumpa minne, skriv D3E0 D3FF och se om det står $E005 och $E004 i någon adress.  
Kör M och modifiera adresserna till $E009 och $E008.  
Skriv G CD00 och du ska få +++ på skärmen.  

Nu kan du mata in IO.ASM i en texteditor och assemblera den med följande rad:  
```
ASMB IO.ASM +LSGY  
```
Du ska nu spara ner drivrutinen för diskettkontrollern med följande kommando:  
```
SAVE DISK,DE00,DFFF  
```
Skapa ny Flex för RT-datorn:  
```
APPEND FLEX.COR,DISK.BIN,IO.BIN,RTFLEX.SYS  
LINK RTFLEX.SYS 
```
Tryck Reset, och boota flex med F  
Du ska nu få en prompt med fråga om datum. Mata in dagens datum med mellanslag mellan månad, dag och år, t.ex 03 11 24, tryck Enter.  
Du ska nu få upp +++  

Om du använder den "gamla" RT-datorn, eller den "nya" med CÅ-817 är du klar och kan köra FLEX 9.1  
Om du använder den "nya" RT-datorn med CÅ-837 (Double Density Floppy Controller) måste du knappa in DISK.ASM och kompilera med följande kommando:  
```
ASMB DISK.ASM +LSGY  
```
Svara Yes på att skriva över den gamla DISK.BIN.  
Repetera ovanstående APPEND och LINK för att lägga till denna drivrutin till FLEX. Boota om och du har en FLEX som stöder enkel eller dubbelsidiga disketter och enkel eller dubbel densitetr, 35, 40 eller 80 spår.  
I mappen Utilities har jag samlat lite olika program som är "bra att ha".

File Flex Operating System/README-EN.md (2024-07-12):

# Flex Operating System
## IO and DISK drivers for RT-datorn
RT-datorn, the "old" one (running 6809) and the "new" one, can run FLEX 9.1 and 3.01.  
Original FLEX 9.1 and 3.01 uses the serial port at address $E004/$E005. This will not work with RT-datorn.  
A Quick-And-Dirty solution is to boot FLEX 9.1 or 3.01 then wait until the disk drive has stopped loading.  
Then press Reset to go to CBUG-monitor.  
Press D for dumping memory, enter D3E0 D3FF and look for $E005 and $E004.  
Press M and modify these addresses and enter $E009 and $E008 to replace $E005 and $E004.  
Press G CD00 and you will get +++ on the screen.  

You can now type in IO.ASM in the editor and assemble it with this command:  
```
ASMB IO.ASM +LSGY  
```
Now save the disk driver with the following command:  
```
SAVE DISK,DE00,DFFF  
```
Create a new FLEX for RT-datorn:  
```
APPEND FLEX.COR,DISK.BIN,IO.BIN,RTFLEX.SYS  
LINK RTFLEX.SYS 
```
Press Reset, and boot with F.  
If all goes well you will get a prompt asking for the date. Enter it with a space character between Month, Year and Day, i.e. 03 11 24, press Enter.  
You will get the FLEX prompt +++  

If you are using the "old" RT-datorn, or the "new" with CÅ-817 you are all set.  
If you are using the "new" RT-datorn with CÅ-837 (Double Density Floppy Controller) you need to enter DISK.ASM and compile it with this command:  
```
ASMB DISK.ASM +LSGY  
```
Answer Yes to overwrite the old DISK.BIN.  
Repeat the above to append the new disk driver to FLEX. Reboot and you have a FLEX that support Single and Double Sided disk, with Single or Double Density and 35, 40 or 80 tracks.  

In the folder Utilities I have gathered some program that are "nice to have".

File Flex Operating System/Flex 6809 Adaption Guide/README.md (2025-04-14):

# 6809 Flex Adaption Guide
```
6809 Flex Adaption Guide.pdf 
6809 Flex Adaption Guide.txt - Contains the extracted raw text from the PDF.
```

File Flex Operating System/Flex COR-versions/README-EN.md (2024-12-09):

# Flex Operating System
## FLEX.COR-versions
The file FLEX COR-versions.ods contains a list of all FLEX.COR from Flex Archive.  
Sorted by MD5 and FLEX version.
| MD5SUM | Size | Path | Version | Date | Info |
| --- | ---- | ---- | --- | ---- | ---- |
| c66475842bfb4825c6602802ebd04a52 | 6048 | 6800FLEX/FLEX.COR | 2.0 | 1979-04-12 | Differs a lot against the other 
| c66475842bfb4825c6602802ebd04a52 | 6048 | BB012/FLEX.COR | 2.0 | 1984-03-17 | 2.0
| c66475842bfb4825c6602802ebd04a52 | 6048 | FLEX2-01/FLEX.COR | 2.0 | 1979-04-12 | 
| c66475842bfb4825c6602802ebd04a52 | 6048 | FLEXSYS/ZFLEX.COR | 2.0 | 1981-03-08 | 
| c66475842bfb4825c6602802ebd04a52 | 6048 | ORG00-01/FLEX.COR | 2.0 | 1979-12-13 | 
|  |  |  |  | 
| 7e7aff69c23ac0b82ca94508da33dc3f | 6048 | AB115/FLEX.COR | 2.0 | 1980-10-26 | FF in this file
|  |  |  |  | 
| f1bf948886c930801c65135250c78f3a | 6048 | AB186/FLEX.COR | 2.0 | 1980-05-30 | Same as 2.0 above
| f1bf948886c930801c65135250c78f3a | 6048 | FL2_0SWT/FLEX.COR | 2.0 | 1979-02-27 | Differs at 0x292, 0xD1A and
| f1bf948886c930801c65135250c78f3a | 6048 | MSIFLX20/FLEX.COR | 2.0 | 1979-12-09 | 0xF68, FE in these files
|  |  |  |  | 
| f4796f5dc618c4e1adb785cb8a2275d8 | 4788 | FLEX_IBM/FLEX.COR | 2.7:3 | 1980-12-12 | 
| f4796f5dc618c4e1adb785cb8a2275d8 | 4788 | FLX2IBM/FLEX.COR | 2.7:3 | 1980-12-12 | 
| f4796f5dc618c4e1adb785cb8a2275d8 | 4788 | SWTFL273/FLEX.COR | 2.7:3 | 1980-12-12 | 
|  |  |  |  | 
| 5ebefa5478f33e199bb3a0134717d798 | 5040 | FLEX283/FLEX.COR | 2.8:3 | 1982-03-08 | Patched for BS and DEL
| 5ebefa5478f33e199bb3a0134717d798 | 5040 | SJT007/FLEX.COR | 2.8:3 | 1981-03-08 | Patched for BS and DEL
| 5ebefa5478f33e199bb3a0134717d798 | 5040 | SWTFL283/FLEX.COR | 2.8:3 | 1981-03-08 | Patched for BS and DEL
| 5ebefa5478f33e199bb3a0134717d798 | 5040 | SWTPF283/FLEX.COR | 2.8:3 | 1981-03-08 | Patched for BS and DEL
| 617b67e772e7655605033fc4339c3935 | 5040 | HDSYS/FLEX.COR | 2.8:3 | 1981-03-08 | Patched for BS and DEL
| 7e8b3eb51d3f8dc3f748b052b6e44cf5 | 5040 | SJT029/FLEX.COR | 2.8:3 | 1981-03-08 | Patched for BS and DEL
| 8190d193ee7ad5791060e038eff4e27b | 5040 | KN05/FLEX.COR | 2.8:3 | 1981-03-08 | Patched for DEL
| ab220490f90f7b4493d1895daba3e757 | 5040 | FLX2_8_1/FLEX.COR | 2.8:3 | 1981-03-08 | Patched for BS and DEL
| e3714323f7e21203e14fe350a7b19d32 | 5040 | DISK08/FLEX.COR | 2.8:3 | 1981-03-08 | Patched for BS and DEL
| e3714323f7e21203e14fe350a7b19d32 | 5040 | FLEX291/FLEX.COR | 2.8:3 | 1981-03-08 | Patched for BS and DEL
|  |  |  |  | 
| 245dd3f62197e7efdc735db41c288b4e | 4536 | AB083/FLEX.COR | 2.9:1 | 1985-05-25 | Same as 2.9.2
| 245dd3f62197e7efdc735db41c288b4e | 4536 | AB160/FLEX.COR | 2.9:1 | 1985-05-24 | One byte at 0x762 differs
| 245dd3f62197e7efdc735db41c288b4e | 4536 | BB019/FLEX.COR | 2.9:1 | 1985-07-28 | C6, 2.9.1 has  C4
| 245dd3f62197e7efdc735db41c288b4e | 4536 | FLEX-291/FLEX.COR | 2.9:1 | 1991-03-08 | 
| 245dd3f62197e7efdc735db41c288b4e | 4536 | S09-000/FLEX.COR | 2.9:1 | 1983-01-26 | 
| 245dd3f62197e7efdc735db41c288b4e | 4536 | S09-012/FLEX.COR | 2.9:1 | 1983-01-26 | 
| 245dd3f62197e7efdc735db41c288b4e | 4536 | S09-020/FLEX.COR | 2.9:1 | 1983-01-26 | 
|  |  |  |  | 
| 6f5f0867598252db7bc61694e1401647 | 4536 | 1024X8X32/Partition_000/FLEX.COR | 2.9:2 |  | Same as 2.9.1
| 6f5f0867598252db7bc61694e1401647 | 4536 | 2048X18X32/Partition_000/FLEX.COR | 2.9:2 |  | One byte at 0x762 differs
| 6f5f0867598252db7bc61694e1401647 | 4536 | 2048X8X32/Partition_000/FLEX.COR | 2.9:2 |  | C4 (ANDB)
| 6f5f0867598252db7bc61694e1401647 | 4536 | 6809BOOT/FLEX.COR | 2.9:2 | 1997-06-27 | 2.9.1 has  C6 (LDB)
| 6f5f0867598252db7bc61694e1401647 | 4536 | DISK111/FLEX.COR | 2.9:2 | 1983-01-26 | 
| 6f5f0867598252db7bc61694e1401647 | 4536 | DMAF2_BOOT/FLEX.COR | 2.9:2 | 1983-01-26 | 
| 6f5f0867598252db7bc61694e1401647 | 4536 | FLEX09/FLEX.COR | 2.9:2 | 1983-01-26 | 
| 6f5f0867598252db7bc61694e1401647 | 4536 | FLEX09BT/FLEX.COR | 2.9:2 | 1997-06-27 | 
| 6f5f0867598252db7bc61694e1401647 | 4536 | FLEX292F/FLEX.COR | 2.9:2 | 1983-01-26 | 
| 6f5f0867598252db7bc61694e1401647 | 4536 | FLEX292HD/FLEX.COR | 2.9:2 | 1983-01-26 | 
| 6f5f0867598252db7bc61694e1401647 | 4536 | FLEX9MST/FLEX.COR | 2.9:2 | 1983-01-26 | 
| 6f5f0867598252db7bc61694e1401647 | 4536 | FLEX9SYS/FLEX.COR | 2.9:2 | 1983-01-26 | 
| 6f5f0867598252db7bc61694e1401647 | 4536 | FLEX9WIN/FLEX.COR | 2.9:2 | 1987-08-10 | 
| 6f5f0867598252db7bc61694e1401647 | 4536 | HIERBOOT/FLEX.COR | 2.9:2 | 1983-01-26 | 
| 6f5f0867598252db7bc61694e1401647 | 4536 | KP1/FLEX.COR | 2.9:2 | 1987-09-10 | 
| 6f5f0867598252db7bc61694e1401647 | 4536 | PL9_MACE/FLEX.COR | 2.9:2 | 1983-01-26 | 
| 6f5f0867598252db7bc61694e1401647 | 4536 | PL9_TEST/FLEX.COR | 2.9:2 | 1983-01-26 | 
|  |  |  |  | 
| cccb62b4d0acea5852d2f3feda986ed6 | 5292 | FLEX/FLEX.COR | 3.01 | 1999-03-21 | 
| cccb62b4d0acea5852d2f3feda986ed6 | 5292 | FLEX_SRCES/FLEX.COR | 3.01 | 1999-03-21 | 
|  |  |  |  | 
| 612619398f32e525e8054c362f41a169 | 5544 | FLXMASTE/FLEX.COR | 3.01 | 1980-10-03 | 
|  |  |  |  | 
| 6ed938b629932138c4a40d0517ff4f9f | 5040 | FL265/FLEX.COR | 9.0 | 1980-04-01 | 
| 6ed938b629932138c4a40d0517ff4f9f | 5040 | FLEXCMDS/FLEX.COR | 9.0 | 1999-03-21 | 
| 6ed938b629932138c4a40d0517ff4f9f | 5040 | FLX_269/FLEX.COR | 9.0 | 1999-10-25 | 
| 6ed938b629932138c4a40d0517ff4f9f | 5040 | FL_2_6SY/FLEX.COR | 9.0 | 1980-04-01 | 
| 6ed938b629932138c4a40d0517ff4f9f | 5040 | KN13/FLEX.COR | 9.0 | 1980-04-01 | 
| 6ed938b629932138c4a40d0517ff4f9f | 5040 | SWFLEX9/FLEX.COR | 9.0 | 2009-10-02 | 
| 6ed938b629932138c4a40d0517ff4f9f | 5040 | WORK18/FLEX26.COR | 9.0 | 1980-04-01 | 
|  |  |  |  | 
| 0ff97473604e5c92daa5b0fe6525913b | 5796 | BRUNO10/FLEX.COR | 9.0 | 1980-01-05 | 
|  |  |  |  | 
| 206f36d8f7192776bd94dae79f0cabf8 | 5040 | LAKELAND/FLEX.COR | 9.0 | 1980-05-06 | 
| 206f36d8f7192776bd94dae79f0cabf8 | 5040 | WORK18/FLEX24.COR |  | 1981-03-15 | 
|  |  |  |  | 
| f095172b1a8faf256d5811a4578afe56 | 5544 | AB088/FLEX.COR | 9.1 | 1985-10-13 | 
| f095172b1a8faf256d5811a4578afe56 | 5544 | AB089/FLEX.COR | 9.1 | 1985-05-12 | 
| f095172b1a8faf256d5811a4578afe56 | 5544 | AB094/FLEX.COR | 9.1 | 1984-04-11 | 
| f095172b1a8faf256d5811a4578afe56 | 5544 | AB096/FLEX.COR | 9.1 | 1982-04-11 | 
| f095172b1a8faf256d5811a4578afe56 | 5544 | AB102/FLEX.COR | 9.1 | 1985-06-30 | 
| f095172b1a8faf256d5811a4578afe56 | 5544 | AB168/FLEX.COR | 9.1 | 1985-10-13 | 
| f095172b1a8faf256d5811a4578afe56 | 5544 | AB178/FLEX.COR | 9.1 | 1981-04-11 | 
| f095172b1a8faf256d5811a4578afe56 | 5544 | ORIGINAL_FLEX09_AB168/FLEX.COR | 9.1 | 1985-10-13 | 
| f095172b1a8faf256d5811a4578afe56 | 5544 | ORIGINAL_FLEX09_AB178/FLEX.COR | 9.1 | 1981-04-11 | 
| f095172b1a8faf256d5811a4578afe56 | 5544 | SYSTEM4/FLEX.COR | 9.1 | 1986-03-07 | 
| f095172b1a8faf256d5811a4578afe56 | 5544 | TSCFLX09/FLEX.COR | 9.1 | 1980-10-03 | 
| f095172b1a8faf256d5811a4578afe56 | 5544 | WORK33/FLEX.COR | 9.1 | 1984-08-09 | 
|  |  |  |  | 
| 591884b5896a027f6b323b05c85eaf14 | 6374 | PT69-HD/FLEX.COR | 9.1 | 1981-03-08 | 
|  |  |  |  | 
| f88756878fd8389f79decf69cd329c2b | 5544 | 1024X8X32/Partition_000/FLEX-91P.COR | 9.1 |  | 
| f88756878fd8389f79decf69cd329c2b | 5544 | 2048X18X32/Partition_000/FLEX-91P.COR | 9.1 |  | 
| f88756878fd8389f79decf69cd329c2b | 5544 | 2048X18X32/Partition_002/FLEX-91P.COR | 9.1 |  | 
| f88756878fd8389f79decf69cd329c2b | 5544 | 2048X8X32/Partition_000/FLEX-91P.COR | 9.1 |  | 
| f88756878fd8389f79decf69cd329c2b | 5544 | PT69-HD/FLEX-91P.COR | 9.1 |  | 
| f88756878fd8389f79decf69cd329c2b | 5544 | PTFLXMON/FLEX-91P.COR | 9.1 |  | 
| f88756878fd8389f79decf69cd329c2b | 5544 | PTHD_SYS/FLEX-91P.COR | 9.1 |  |

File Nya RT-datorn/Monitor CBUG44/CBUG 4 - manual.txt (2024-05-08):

MONITORPROGRAM   CBUG 4
CBUG4 är ett kombinerat monitor- och terminalprogram till
"nya" RT-datorn uppbyggd kring ett CPU-kort CÅ-812 och ett
terminalkort CÅ-815.

CBUG 4 består av 2 st Eprom 2716, vilka placeras på kortet
CÅ-812 i socklarna märkta F000 och F800. För att få CBUG 4
att fungera, erfordras endast RAM mellan $ E100 - E3FF (IC5
på kort CÅ-812). Skall Flex operativsystem användas, måste
dock alla RAM-kretsarna (IC17-32) på kretskortet CÅ-812 monteras.

Till kretskort CÅ-815 ansluts ett standard ACII-kodat tangent-
bord och en videomonitor.

Vid start skrivs "CBUG 4.4" ut och man har därefter nedan-
stående kommandon att välja bland. På vissa kommandon skall
start- och stoppadresser inmatas. Dessa är angivna som ex.vis
aaaa bbbb.

@   Gå till Flex varmstartsadress $ CD03. Fungerar endast om 
    det på denna adress står $ 7E

B   Visa adresserna till insatta brytpunkter. Om inte någon bryt-
    punkt är insatt skrivs "0".

C   Continue. Fortsätt programexekveringen eter brytpunkt. Vid
    "C" läggs alla brytpunkter in i programmet, varefter pro-
    cessorns register laddas från användarstacken.

D   Dumpa minnesinnehållet på bildskärmen med 16 bytes per rad
    mellan adresserna aaaa och bbbb.

E   Extended instruktionssökning. sök efter de adresser mellan
    aaaa och bbbb där opcode cc finns.

F   "Bootstrap"-laddade för Flex 9. Kräver kort CÅ-817 (flex-
    kontroll) och minst en flexskiveenhet.

G   Gå till adress aaaa och exekvera program. Processorns re-
    gister laddas från användarstacken och eventuella bryt-
    punkter läggs in.

H   Beräkna kontrollsumma mellan minnesadresserna aaaa och bbbb.

I   Ändra innehållen på användarstacken. Först visas CC-registret.
    Skall detta ej ändras tryck på ".". Skall det ändras skriv
    in två hexadecimala tecken. Varje register visas med en bok-
    stav (A, B, C, X, Y, U, S och PC). 16-bits registren fordrar
    4 hexadecimala tecken.
 
J   Subrutinanrop på adress aaaa. Processorns register laddas
    först från användarstacken.

K   Kopiera minnesinnehållet mellan aaaa och bbbb till cccc.
    Om RAM ej finns på destinationsadressen, skrivs detta ut.

L   Ladda Flex 9 från epromkort CÅ-816. Laddas från adress
    $ 0C00 - $ 1FFF på epromkortet till $ CC00 - $ DFFF i
    ram.

M   Minnesmanipulering på aaaa. Efter adressen skriv minnes-
    innehållet ut. vill man ändra innehållet anger man det
    nya värdet som två hexadecimala tecken. Om detta nya värde
    fastnar i minnet. d v s då det finns RAM på den adressen,
    skrivs nästa adressposition med sitt minnesinnehåll ut på
    nästa rad. Om det nya värdet inte fastnar, det kan då vara
    fråga om ROM eller ett kontrollregister på en periferikrets,
    skrivs ett frågetecken och samma adress med minnesinnehåll
    på nästa rad. Med en punkt skrivs nästa minnesposition ut
    utan att något ändras. Efter ett tryck på retur-tangenten
    återgår programmet till kontrollslingan. Vill man titta
    på föregående minnesposition trycker man på minustecken.
    det går även att beräkna offset, vilket är behändigt vid
    handassemblering av relativa adresser. Efter minnesinne-
    hållet skriver man ett O (bokstaven O) följt av en 4-
    ställig adress. Det beräknade offsetvärdet skriv ut i 
    tvåkomponentform. programmet avgör själv om kort eller
    lång offset skall användas.

O   Fyll minnet mellan aaaa och bbbb med en byte cc.

PL  Flytta data från epromkortet CÅ-816 (start = aaaa, slut =
    bbbb) till ram.minnet (start cccc).

PH  Beräkna kontrollsumman mellan adresserna aaaa och bbbb på
    epromkortet.

PR  Programslinga som kontinuerligt läser av epromkortet mellan
    aaaa och bbbb. Avbryts med "Q". Används enbart vid felsök-
    ning på kort CÅ-816

Q   Mät ram-minnets storlek.

R   Skriv ut registren i användarstacken.

S   Sök efter 16 bitars värdet cccc mellan adresserna aaaa
    och bbbb.

U   Ta bort alla brytpunkter, även de som finns kvar, om re-
    start-knappen har intryckts under programexekvering.

V   Sätt in en brytpunkt på adress aaaa. Max 5 brytpunkter kan
    sättas in.

W   Minnestest mellan adresserna aaaa och bbbb. Vid varje felfri
    testloop skriv "+" på skärmen. Avbryts med valfri tangent.

X   Ladda Flex 9.1 från epromkort 836. Laddas från adress
    $ 0000 - $ 18D7 på epromkortet till ram.

Y   Verifiering av minnesinnehåll, adressangivelser som vid
    "K".

Z   Dumpa minnesinnehåll som "D" men utskrifter sker på skrivare
    ansluten till kort CÅ-813.

    Utskriften vid kommandona D, E, S, Y och X kan stoppas
    med "0" (noll), återstartas med "9" och avbrytas med "Q"
    eller "q".

Användbara rutiner

Följande rutiner kan användas i egna program. en del återfinns
på två adresser. De med $ F800 och uppåt är indirekta subrutin-
anrop och finns med endast för kompatibilitet med CBUG 2.

$ F000    INCH    Hämta tecken från tangentbordet, paritetsbiten
                  borttagen. Inget eko till bildskärmen.

$ F003    INCHK   Test om något tecken finns att hämta från tan-
{$ F808}          gentbordet. Nollkondition = inget tecken.

$ F006    OUTCH   Sänd ett tecken till bildskärmen.
($ F80A)         

$ F009    INCHA   Som INKEY med med små bokstäver görs om till stora.
                  Eka ut tecknen till bildskärmen.

$ F00C    CBUG    Återgå till monitorprogrammets kontrollslinga.
($ F802)

$ F00F    PDATA   Skriv ut en textsträng. Avsluta med "4".
                  X-reg. pekar på första tecknet.

$ F012    OUT2HS  Skriv ut 2 hexadecimala tecken från en minnes-
                  cell. X-reg. skall peka på minnescellen.

$ F015    OUT4HS  Skriv ut 4 hexadecimala tecken.

$ F018    PCRLF   Ny rad på bildskärmen.

$ F01B    PRIOUT  Sänd ett tecken till skrivaren ansluten till
                  kort CÅ-813.

$ E101            Adress till IRQ-vektorns rutin.

$ E103               "     "  SWI1    "      "

$ E105               "     "  SWI2    "      "

$ E107               "     "  SWI3    "      "

Terminaldelen kan styras med följande kontrolltecken, som sänds
till rutinen OUTCH.

$ 1B + 01 - Page mode, utskriften scrollas ej utan börjar om upp-
            till, när sidan är fullskriven.

$ 1B + 02 - Tänd cursor

$ 1B + 03 - Tänd snabbt blinkande cursor

$ 1B + 04 - Tänd långsamt    "      "

$ 1B + 05 - Radera skärmen + cursor home

       07 - Bell, ger en tonpuls till tangentbordets högtalare

       08 - Backspace

   $ 0A - Line feed, radmatning

   $ 0D - Return, cursorn återgår till vänsterkanten

$ 1B + $ 10 - Normal scroll

$ 1B + $ 15 - Släck cursorn

$ 1B + $ 16 - Restore cursorn

$ 1B + $ 17 - Restore och tänd cursor

$ 1B + $ 18 - Save och släck cursor

$ 1B + $ 19 - Save cursor

$ 1B + $ 1A - Radera från cursorn till radens slut

$ 1B + $ 1C - Byt ej ut koderna för [, \, ] etc mot Å, Ä, Ö

$ 1B + $yy + $xx = cursorpositionering

yy är ett hexadecimalt tal mellan $ 40 och $ 57 och anger på
vilken rad cursorn skall stå.

xx är ett hexadecimalt tal mellan $ 30 och $ 7F och anger i
vilken kolumn (position på raden) cursorn ska stå.

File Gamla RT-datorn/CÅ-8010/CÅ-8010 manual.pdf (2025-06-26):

### Manual för CPROG/TPROG – CÅ-8010 EPROM-programmerare

Om programmeraren är placerad i datorns periferikontakt J7 och operativsystemet FLEX är uppstartat (tre plustecken i vänsterkanten på bildskärmen), anropas programmet genom att man skriver TPROG (för 6808) eller CPROG (för 6809) följt av ett tryck på returtangenten.

Efter några sekunder identifierar sig programmet och frågar: Epromtype:
På det svarar man genom att ange det EPROM som skall programmeras. Nu är det dock så, att det finns olika beteckningar på samma krets och vice versa. För att få en enhetlig vokabulär skall följande beteckningar användas till programmeraren:
* 2708:
Samtliga fabrikat av 2708, 1 kB EPROM med tre matningsspänningar.
* 2716 Texas och Motorola:
2 kB EPROM med tre matningsspänningar.
* 2516
Samtliga fabrikat 2516 eller 2716 2 kB EPROM med en matningsspänning.
* 2532
Texas 4 kB EPROM med en matningsspänning.
* 2732
Intel 4 kB EPROM med en matningsspänning.

När vi har talat om vilken typ av EPROM vi har (här 2516), skriver programmet:
Check switch position
Epromtype 2516
R-D-V-M-P-S-N-F-T ?:

Den första raden är en liten påminnelse om att vi bör kontrollera att S1 är intryckt för rätt EPROM . Den andra är en upprepning av den typ vi har valt och den tredje är en fråga om vilket kommando man önskar. Det finns som synes nio stycken.

R = kontrollera om EPROMkretsen är raderad.
Om så är fallet skrivs Eprom erased ut på skärmen. I annat fall skrivs nnn position(s) not erased där nnn är ett decimalt tal.

D = dumpa EPROM-kretsens innehåll
till valfri minnesarea i datorn . Med valfri menas den del av minnet som inte upptas av operativsystemet. Programmet frågar efter adresser. Från början skrivs 0000 ut för EPROM startadress och RAM startadress. Är man nöjd med vad programmet skriver ut (gäller samtliga adressfrågor), svarar man med att trycka på returtangenten. I annat fall svarar man med önskad adress följt av en tryckning på returtangenten. Inledande nollor behöver inte anges. Adress 0033 kan alltså anges som enbart 33. Alla adresser är i hexadecimal form. Om man gör något fel innan man trycker ner
returtangenten | går | det | bra | att | rätta | misstaget | med

backstegstangenten (CTRL H) som på det svenska tangentbordet är en tangent med en vänsterpil placerad längst upp till höger. Om det inte finns något RAM-minne på den angivna adressen skriver datorn No ram.

V = verifiering
vilket innebär att innehållet i EPROM-kretsen jämförs med ett visst minnesinnehåll. Om ingen skillnad finns, skrivs Verif OK ut på bildskärmen. I annat fall skrivs minnesadress och data i minnet resp EPROM-kretsen ut. En verifiering sker automatiskt efter programmering.

M = matchning.
Även om en EPROM-krets inte är helt raderad kan det hända att den går att programmera med önskat program. Om det i en cell står $F5 och i motsvarande adress i RAM-minnet (som skall programmera EPROM-kretsen) står $E4, går det utmärkt att göra om F5 till E4. En raderad EPROM har $FF i alla celler. Vid programmering ändras "ettor" till "nollor". För att kontrollera om det går att programmera en krets utan att radera den först, måste man titta på varje bitposition i EPROM-kretsen. Om det är en "etta" i kretsen och en nolla eller en etta på motsvarande position i minnet, kan kretsen programmeras. Om allt är som det skall, skriver datorn ut Eprom programmable. Om en eller flera celler inte går att programmera, skrivs nnn position(s) not programmable. Även här är nnn ett decimalt tal.

P = programmera.
Först kontrolleras om kretsen är raderad. Därpå frågar programmet efter adresserna i RAM-minnet från vilka data skall läggas in i EPROM-kretsen. Programmet ser till att man inte anger en större minnesarea än vad som får plats i den angivna EPROM-typen. Efter att ha svarat på detta kommer frågan
Start (Y) ? och den besvaras med Y om vi skall programmera. I
annat | fall | återgår | programmet | till | kontrollslingan.
Programmeringstiden varierar något mellan olika typer och om flera försök måste göras. En vanlig 2516 tar ca 100 s att programmera och verifiera.

S = dumpa till RAM och visa minnesinnehållet.
Med det här kommandot utförs först en överföring av EPROM-kretsens minnesinnehåll till datorns minne (från adress O och uppåt) och därpå en minnesdump. Det senare utförs med PDUMP-rutinen i TBUG resp CBUG-monitorerna. S-kommandot bör ej tillgripas om någon annan monitor används, eftersom programmet då kan spåra UT.

N = ny EPROM-typ.
Med kommandot börjar programmet om från början och man kan byta till en annan typ av EPROM.

F = gå till Flex operativsystem.
T eller C = gå till monitorprogrammet.
T används för 6800- och C för 6809-varianten.

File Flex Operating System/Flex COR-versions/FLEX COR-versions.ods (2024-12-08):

MD5SUM | Size | Path | Version | Date | Info
c66475842bfb4825c6602802ebd04a52 | 6048 | 6800FLEX/FLEX.COR | FLEX 2.0 | 1979-04-12 | Differs a lot against the other
c66475842bfb4825c6602802ebd04a52 | 6048 | BB012/FLEX.COR | FLEX 2.0 | 1984-03-17 | FLEX 2.0
c66475842bfb4825c6602802ebd04a52 | 6048 | FLEX2-01/FLEX.COR | FLEX 2.0 | 1979-04-12
c66475842bfb4825c6602802ebd04a52 | 6048 | FLEXSYS/ZFLEX.COR | FLEX 2.0 | 1981-03-08
c66475842bfb4825c6602802ebd04a52 | 6048 | ORG00-01/FLEX.COR | FLEX 2.0 | 1979-12-13
7e7aff69c23ac0b82ca94508da33dc3f | 6048 | AB115/FLEX.COR | FLEX 2.0 | 1980-10-26 | FF in this file
f1bf948886c930801c65135250c78f3a | 6048 | AB186/FLEX.COR | FLEX 2.0 | 1980-05-30 | Same as FLEX 2.0 above
f1bf948886c930801c65135250c78f3a | 6048 | FL2_0SWT/FLEX.COR | FLEX 2.0 | 1979-02-27 | Differs at 0x292, 0xD1A and
f1bf948886c930801c65135250c78f3a | 6048 | MSIFLX20/FLEX.COR | FLEX 2.0 | 1979-12-09 | 0xF68, FE in these files
f4796f5dc618c4e1adb785cb8a2275d8 | 4788 | FLEX_IBM/FLEX.COR | FLEX 2.7:3 | 1980-12-12
f4796f5dc618c4e1adb785cb8a2275d8 | 4788 | FLX2IBM/FLEX.COR | FLEX 2.7:3 | 1980-12-12
f4796f5dc618c4e1adb785cb8a2275d8 | 4788 | SWTFL273/FLEX.COR | FLEX 2.7:3 | 1980-12-12
5ebefa5478f33e199bb3a0134717d798 | 5040 | FLEX283/FLEX.COR | FLEX 2.8:3 | 1982-03-08 | Patched for BS and DEL | 03 08
5ebefa5478f33e199bb3a0134717d798 | 5040 | SJT007/FLEX.COR | FLEX 2.8:3 | 1981-03-08 | Patched for BS and DEL | 03 08
5ebefa5478f33e199bb3a0134717d798 | 5040 | SWTFL283/FLEX.COR | FLEX 2.8:3 | 1981-03-08 | Patched for BS and DEL | 03 08
5ebefa5478f33e199bb3a0134717d798 | 5040 | SWTPF283/FLEX.COR | FLEX 2.8:3 | 1981-03-08 | Patched for BS and DEL | 03 08
617b67e772e7655605033fc4339c3935 | 5040 | HDSYS/FLEX.COR | FLEX 2.8:3 | 1981-03-08 | Patched for BS and DEL | 02 03
7e8b3eb51d3f8dc3f748b052b6e44cf5 | 5040 | SJT029/FLEX.COR | FLEX 2.8:3 | 1981-03-08 | Patched for BS and DEL | 04 07
8190d193ee7ad5791060e038eff4e27b | 5040 | KN05/FLEX.COR | FLEX 2.8:3 | 1981-03-08 | Patched for DEL | 01 27
ab220490f90f7b4493d1895daba3e757 | 5040 | FLX2_8_1/FLEX.COR | FLEX 2.8:3 | 1981-03-08 | Patched for BS and DEL | 07
e3714323f7e21203e14fe350a7b19d32 | 5040 | DISK08/FLEX.COR | FLEX 2.8:3 | 1981-03-08 | Patched for BS and DEL | 07 22
e3714323f7e21203e14fe350a7b19d32 | 5040 | FLEX291/FLEX.COR | FLEX 2.8:3 | 1981-03-08 | Patched for BS and DEL | 07 22
245dd3f62197e7efdc735db41c288b4e | 4536 | AB083/FLEX.COR | FLEX 2.9:1 | 1985-05-25 | Same as FLEX 2.9.2
245dd3f62197e7efdc735db41c288b4e | 4536 | AB160/FLEX.COR | FLEX 2.9:1 | 1985-05-24 | One byte at 0x762 differs
245dd3f62197e7efdc735db41c288b4e | 4536 | BB019/FLEX.COR | FLEX 2.9:1 | 1985-07-28 | C6, FLEX 2.9.1 has C4
245dd3f62197e7efdc735db41c288b4e | 4536 | FLEX-291/FLEX.COR | FLEX 2.9:1 | 1991-03-08
245dd3f62197e7efdc735db41c288b4e | 4536 | S09-000/FLEX.COR | FLEX 2.9:1 | 1983-01-26
245dd3f62197e7efdc735db41c288b4e | 4536 | S09-012/FLEX.COR | FLEX 2.9:1 | 1983-01-26
245dd3f62197e7efdc735db41c288b4e | 4536 | S09-020/FLEX.COR | FLEX 2.9:1 | 1983-01-26
6f5f0867598252db7bc61694e1401647 | 4536 | 1024X8X32/Partition_000/FLEX.COR | FLEX 2.9:2 |  | Same as FLEX 2.9.1
6f5f0867598252db7bc61694e1401647 | 4536 | 2048X18X32/Partition_000/FLEX.COR | FLEX 2.9:2 |  | One byte at 0x762 differs
6f5f0867598252db7bc61694e1401647 | 4536 | 2048X8X32/Partition_000/FLEX.COR | FLEX 2.9:2 |  | C4 (ANDB)
6f5f0867598252db7bc61694e1401647 | 4536 | 6809BOOT/FLEX.COR | FLEX 2.9:2 | 1997-06-27 | FLEX 2.9.1 has C6 (LDB)
6f5f0867598252db7bc61694e1401647 | 4536 | DISK111/FLEX.COR | FLEX 2.9:2 | 1983-01-26
6f5f0867598252db7bc61694e1401647 | 4536 | DMAF2_BOOT/FLEX.COR | FLEX 2.9:2 | 1983-01-26
6f5f0867598252db7bc61694e1401647 | 4536 | FLEX09/FLEX.COR | FLEX 2.9:2 | 1983-01-26
6f5f0867598252db7bc61694e1401647 | 4536 | FLEX09BT/FLEX.COR | FLEX 2.9:2 | 1997-06-27
6f5f0867598252db7bc61694e1401647 | 4536 | FLEX292F/FLEX.COR | FLEX 2.9:2 | 1983-01-26
6f5f0867598252db7bc61694e1401647 | 4536 | FLEX292HD/FLEX.COR | FLEX 2.9:2 | 1983-01-26
6f5f0867598252db7bc61694e1401647 | 4536 | FLEX9MST/FLEX.COR | FLEX 2.9:2 | 1983-01-26
6f5f0867598252db7bc61694e1401647 | 4536 | FLEX9SYS/FLEX.COR | FLEX 2.9:2 | 1983-01-26
6f5f0867598252db7bc61694e1401647 | 4536 | FLEX9WIN/FLEX.COR | FLEX 2.9:2 | 1987-08-10
6f5f0867598252db7bc61694e1401647 | 4536 | HIERBOOT/FLEX.COR | FLEX 2.9:2 | 1983-01-26
6f5f0867598252db7bc61694e1401647 | 4536 | KP1/FLEX.COR | FLEX 2.9:2 | 1987-09-10
6f5f0867598252db7bc61694e1401647 | 4536 | PL9_MACE/FLEX.COR | FLEX 2.9:2 | 1983-01-26
6f5f0867598252db7bc61694e1401647 | 4536 | PL9_TEST/FLEX.COR | FLEX 2.9:2 | 1983-01-26
cccb62b4d0acea5852d2f3feda986ed6 | 5292 | FLEX/FLEX.COR | FLEX 3.01 | 1999-03-21
cccb62b4d0acea5852d2f3feda986ed6 | 5292 | FLEX_SRCES/FLEX.COR | FLEX 3.01 | 1999-03-21
612619398f32e525e8054c362f41a169 | 5544 | FLXMASTE/FLEX.COR | FLEX 3.01 | 1980-10-03
6ed938b629932138c4a40d0517ff4f9f | 5040 | FL265/FLEX.COR | FLEX 9.0 | 1980-04-01
6ed938b629932138c4a40d0517ff4f9f | 5040 | FLEXCMDS/FLEX.COR | FLEX 9.0 | 1999-03-21
6ed938b629932138c4a40d0517ff4f9f | 5040 | FLX_269/FLEX.COR | FLEX 9.0 | 1999-10-25
6ed938b629932138c4a40d0517ff4f9f | 5040 | FL_2_6SY/FLEX.COR | FLEX 9.0 | 1980-04-01
6ed938b629932138c4a40d0517ff4f9f | 5040 | KN13/FLEX.COR | FLEX 9.0 | 1980-04-01
6ed938b629932138c4a40d0517ff4f9f | 5040 | SWFLEX9/FLEX.COR | FLEX 9.0 | 2009-10-02
6ed938b629932138c4a40d0517ff4f9f | 5040 | WORK18/FLEX26.COR | FLEX 9.0 | 1980-04-01
0ff97473604e5c92daa5b0fe6525913b | 5796 | BRUNO10/FLEX.COR | FLEX 9.0 | 1980-01-05
206f36d8f7192776bd94dae79f0cabf8 | 5040 | LAKELAND/FLEX.COR | FLEX 9.0 | 1980-05-06
206f36d8f7192776bd94dae79f0cabf8 | 5040 | WORK18/FLEX24.COR |  | 1981-03-15
f095172b1a8faf256d5811a4578afe56 | 5544 | AB088/FLEX.COR | FLEX 9.1 | 1985-10-13
f095172b1a8faf256d5811a4578afe56 | 5544 | AB089/FLEX.COR | FLEX 9.1 | 1985-05-12
f095172b1a8faf256d5811a4578afe56 | 5544 | AB094/FLEX.COR | FLEX 9.1 | 1984-04-11
f095172b1a8faf256d5811a4578afe56 | 5544 | AB096/FLEX.COR | FLEX 9.1 | 1982-04-11
f095172b1a8faf256d5811a4578afe56 | 5544 | AB102/FLEX.COR | FLEX 9.1 | 1985-06-30
f095172b1a8faf256d5811a4578afe56 | 5544 | AB168/FLEX.COR | FLEX 9.1 | 1985-10-13
f095172b1a8faf256d5811a4578afe56 | 5544 | AB178/FLEX.COR | FLEX 9.1 | 1981-04-11
f095172b1a8faf256d5811a4578afe56 | 5544 | ORIGINAL_FLEX09_AB168/FLEX.COR | FLEX 9.1 | 1985-10-13
f095172b1a8faf256d5811a4578afe56 | 5544 | ORIGINAL_FLEX09_AB178/FLEX.COR | FLEX 9.1 | 1981-04-11
f095172b1a8faf256d5811a4578afe56 | 5544 | SYSTEM4/FLEX.COR | FLEX 9.1 | 1986-03-07
f095172b1a8faf256d5811a4578afe56 | 5544 | TSCFLX09/FLEX.COR | FLEX 9.1 | 1980-10-03
f095172b1a8faf256d5811a4578afe56 | 5544 | WORK33/FLEX.COR | FLEX 9.1 | 1984-08-09
591884b5896a027f6b323b05c85eaf14 | 6374 | PT69-HD/FLEX.COR | FLEX 9.1 | 1981-03-08
f88756878fd8389f79decf69cd329c2b | 5544 | 1024X8X32/Partition_000/FLEX-91P.COR | FLEX 9.1
f88756878fd8389f79decf69cd329c2b | 5544 | 2048X18X32/Partition_000/FLEX-91P.COR | FLEX 9.1
f88756878fd8389f79decf69cd329c2b | 5544 | 2048X18X32/Partition_002/FLEX-91P.COR | FLEX 9.1
f88756878fd8389f79decf69cd329c2b | 5544 | 2048X8X32/Partition_000/FLEX-91P.COR | FLEX 9.1
f88756878fd8389f79decf69cd329c2b | 5544 | PT69-HD/FLEX-91P.COR | FLEX 9.1
f88756878fd8389f79decf69cd329c2b | 5544 | PTFLXMON/FLEX-91P.COR | FLEX 9.1
f88756878fd8389f79decf69cd329c2b | 5544 | PTHD_SYS/FLEX-91P.COR | FLEX 9.1

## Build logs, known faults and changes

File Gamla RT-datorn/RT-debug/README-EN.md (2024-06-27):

## Simple Debug board for address and data bus
This is a simple peripheral board I made for debugging a problem with the RT-computer.  
It shows the current address for the address-bus and the status for the data-bus.

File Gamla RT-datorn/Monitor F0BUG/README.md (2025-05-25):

# F0BUG EPROM MONITOR FOR CÅ-8006
### AV ÅKE HOLM

## COMMANDS IN F0BUG
* TANGENTERNAS FUNKTIONER : 
* 0-9 SAMT A-F HEXADECIMAL TECKENINMATNING 
* A-F ÄR ÄVEN KOMMANDOTANGENTER 
* A ALTER MEMORY, MINNESMANIPULERING 
* B SÄTT IN EN BRYTPUNKT 
* C CONTINUE, FORTSÄTT PROGRAMMET FRÅN BRYTPUNKT 
* D DELETE BRKPT, TA BORT ALLA BRYTPUNKTER 
* E EXECUTE PROGRAM, GÅ TILL ADRESS OCH STARTA PROGRAM 
* L LADDA MINNET FRÅN KASSETT S1-FORMAT 
* P PUNCH MEMORY, SPELA IN DATA PÅ KASSETT S1-FORMAT 
* R DISPLAY REGISTERS

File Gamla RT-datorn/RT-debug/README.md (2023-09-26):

## Enkelt Debug-kort för adress och databussen
Här är ett enkelt periferikort jag gjort för att kunna debugga ett problem emd RT-datorn.  
Det visar aktuell adress på adress-bussen samt status på data-bussen.

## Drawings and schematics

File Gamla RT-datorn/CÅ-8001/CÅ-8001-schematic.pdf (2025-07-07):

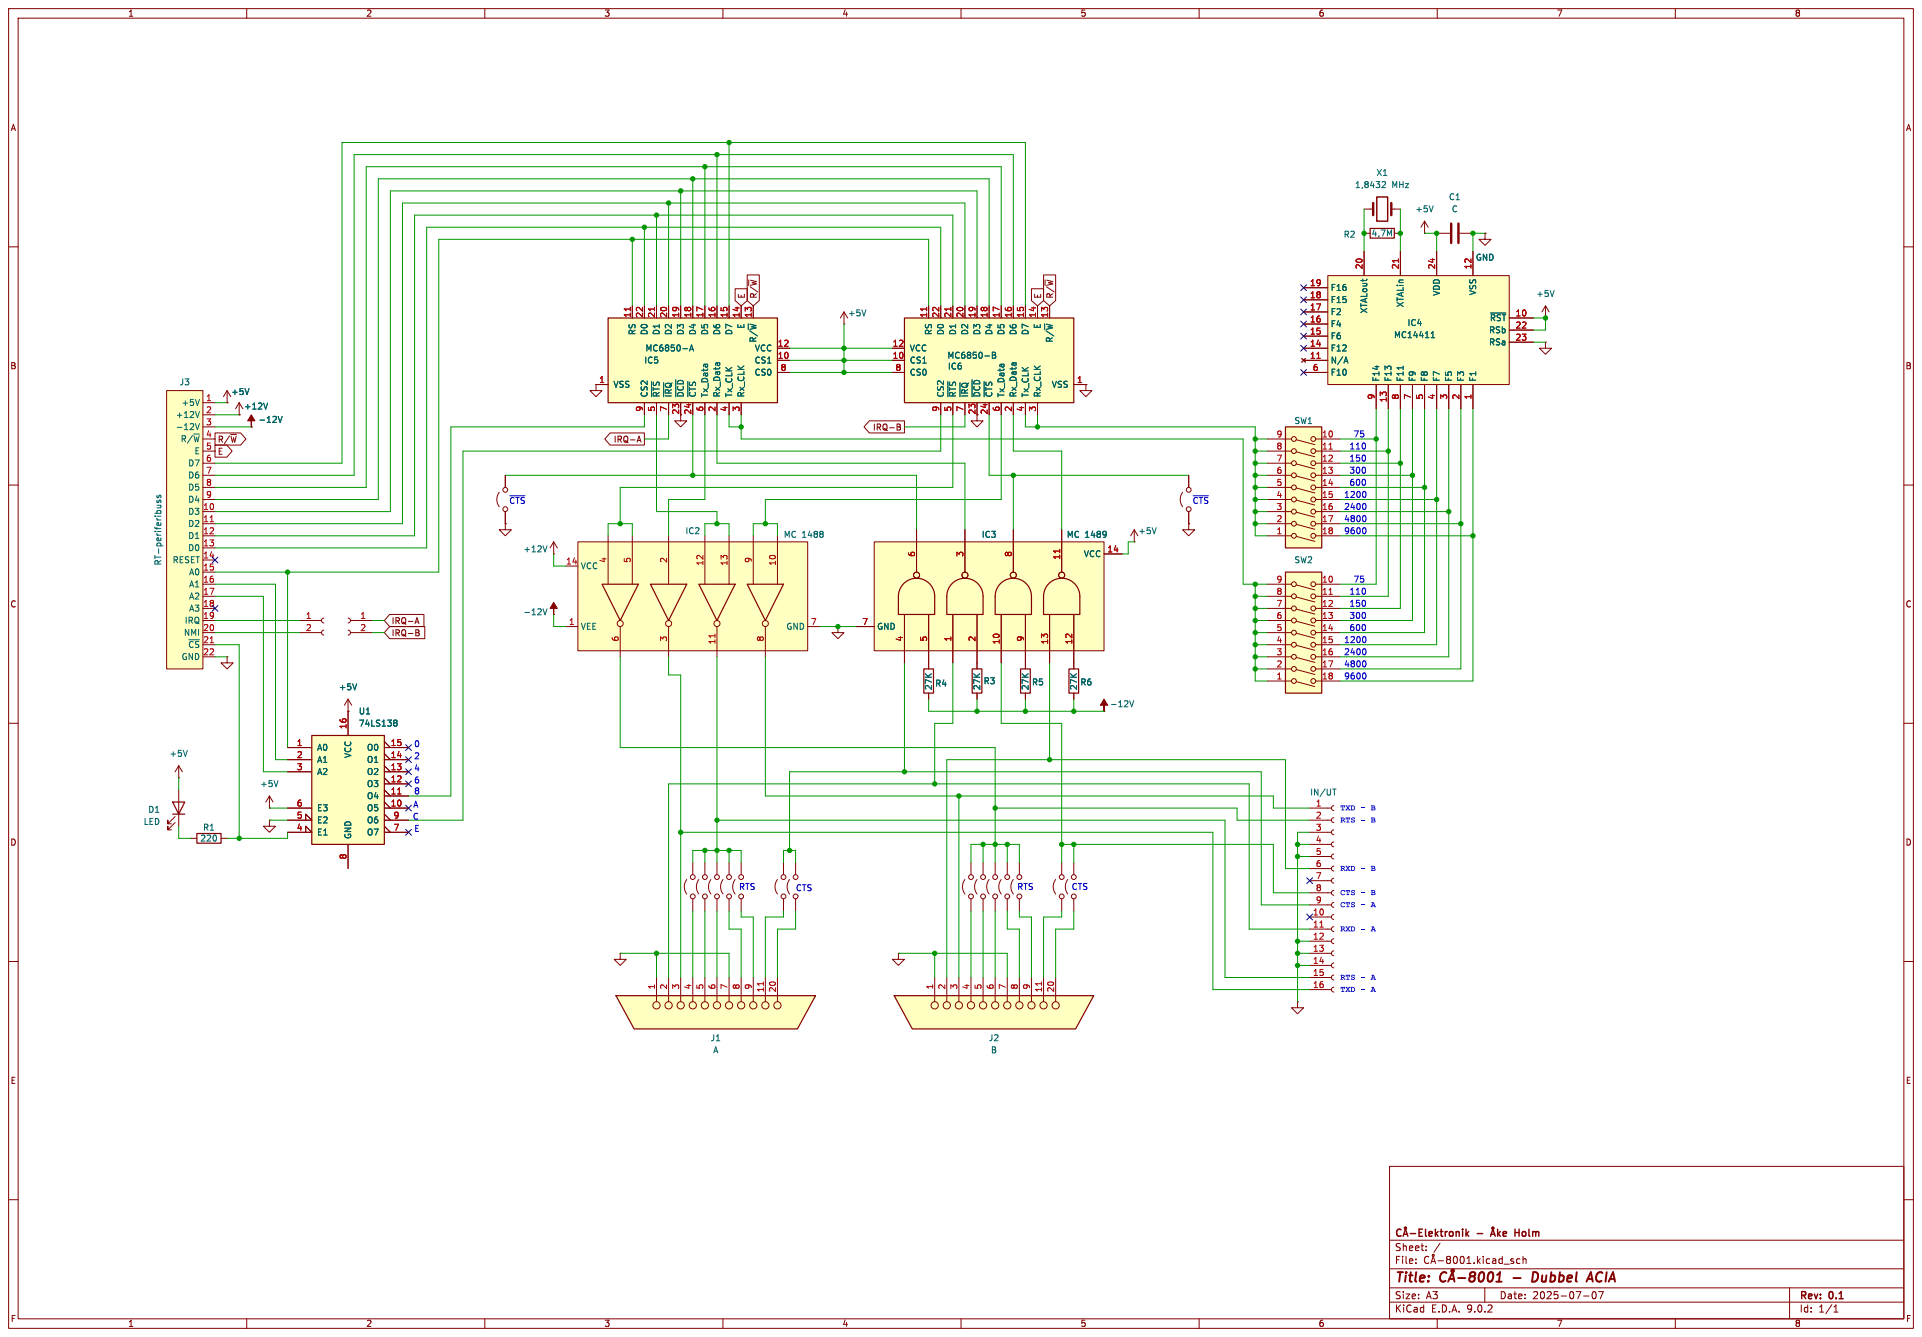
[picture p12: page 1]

9 D1 21 ~{RTS} 5 D2 20 ~{IRQ} 7 D3 19 ~{DCD} 23 D4 18 ~{CTS} 24 D5 17 Tx_Data

File: þÿCÅ-8001.kicad_sch Sheet: / þÿCÅ-Elektronik - þÿÅkeHolm

Id: 1/1 Title: þÿCÅ-8001 - Dubbel ACIA

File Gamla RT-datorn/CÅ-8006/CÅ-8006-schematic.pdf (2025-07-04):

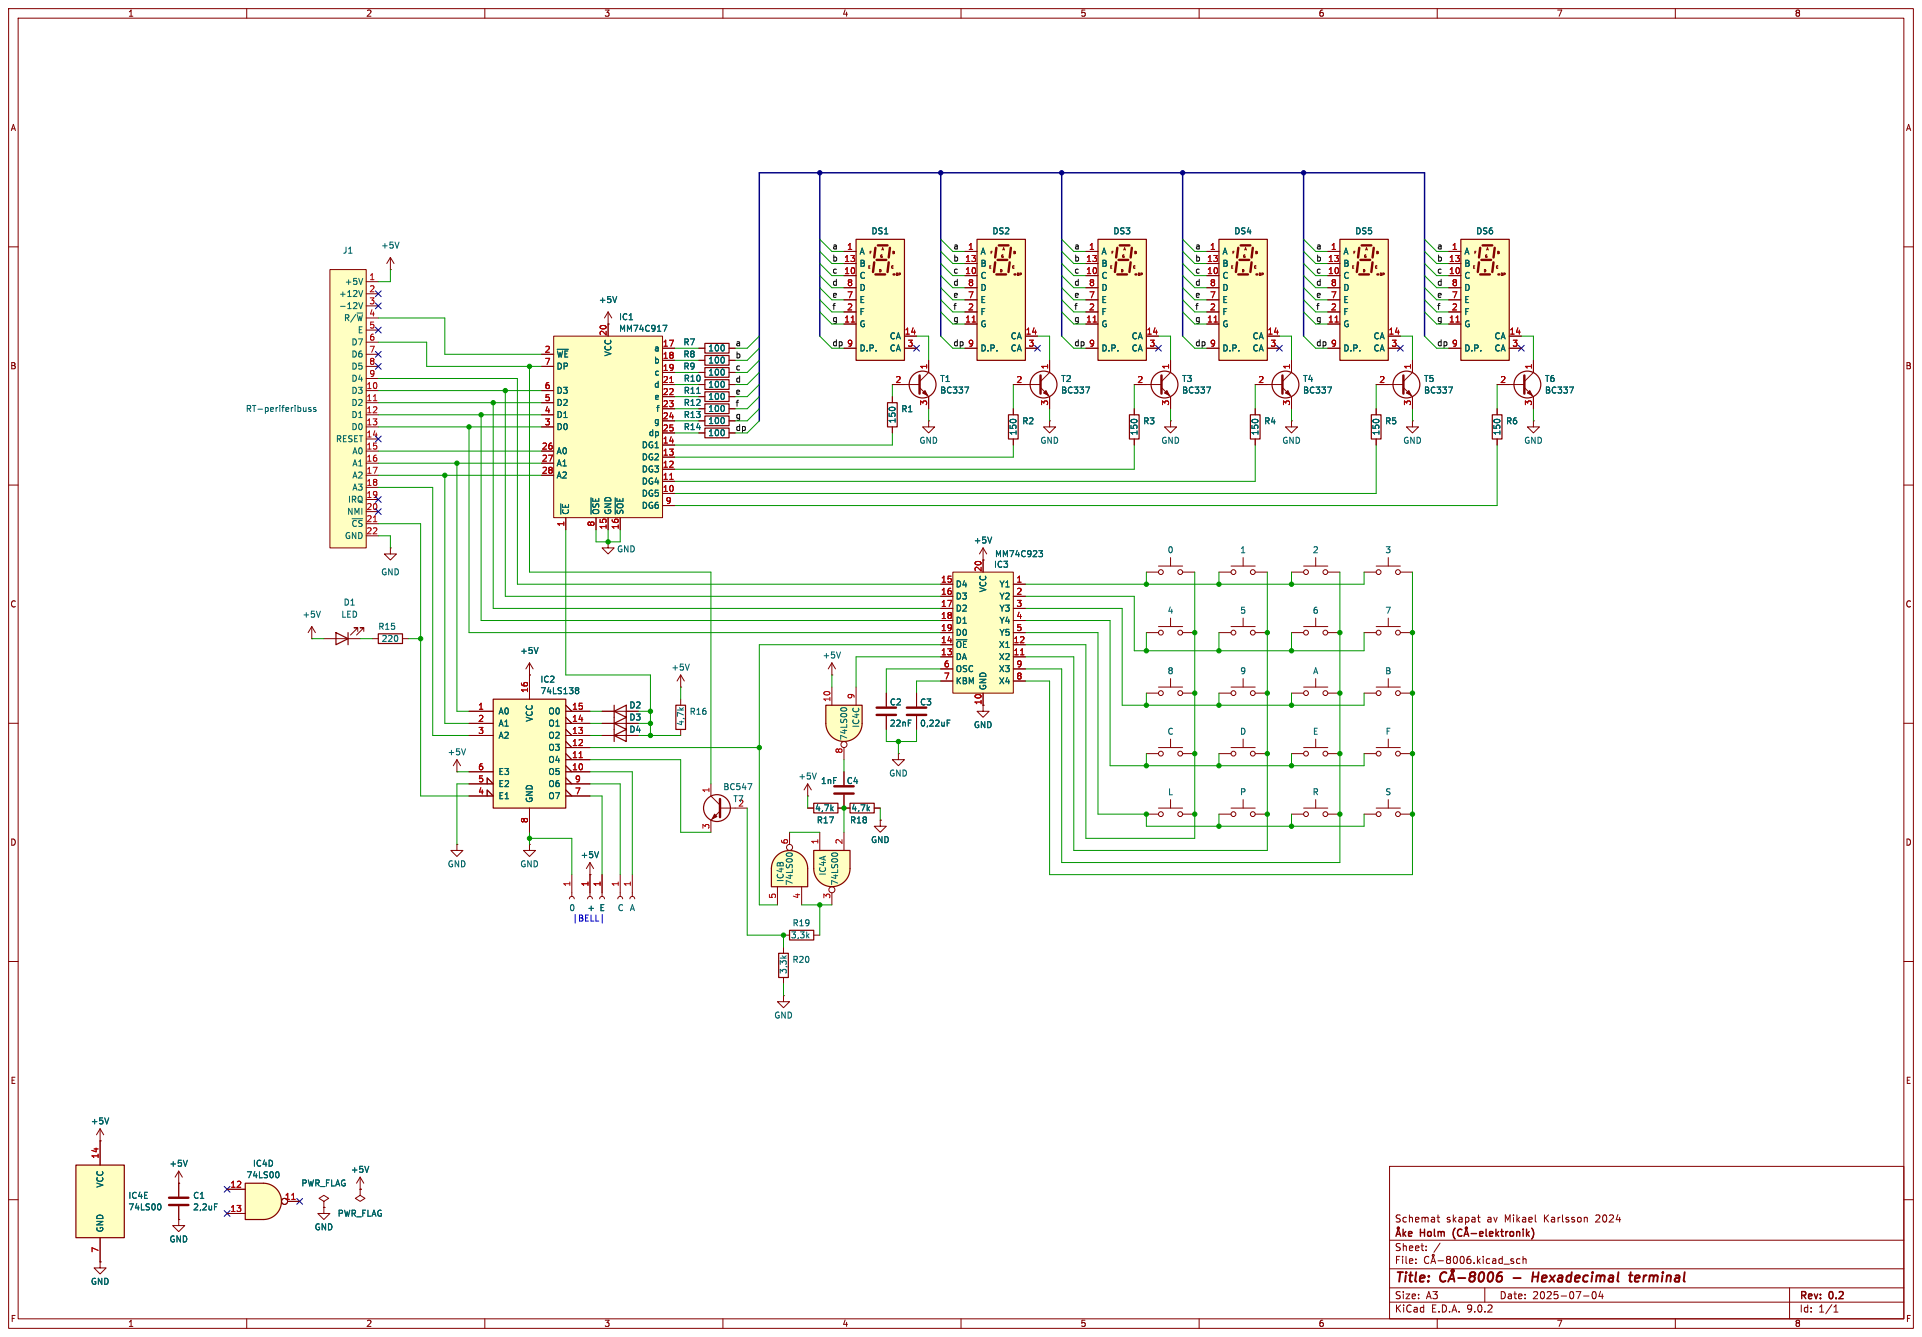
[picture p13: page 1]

IRQ 19 NMI 20 ~{CS} 21 GND 22 +5V 1 +12V 2 R/~{W}4
5 D7 6 D6 7 D5 8 D4 9 D3 10 D2 11 D1 12 D0 13 RESET 14 A0 15 A1 16 A2 17 A3 18

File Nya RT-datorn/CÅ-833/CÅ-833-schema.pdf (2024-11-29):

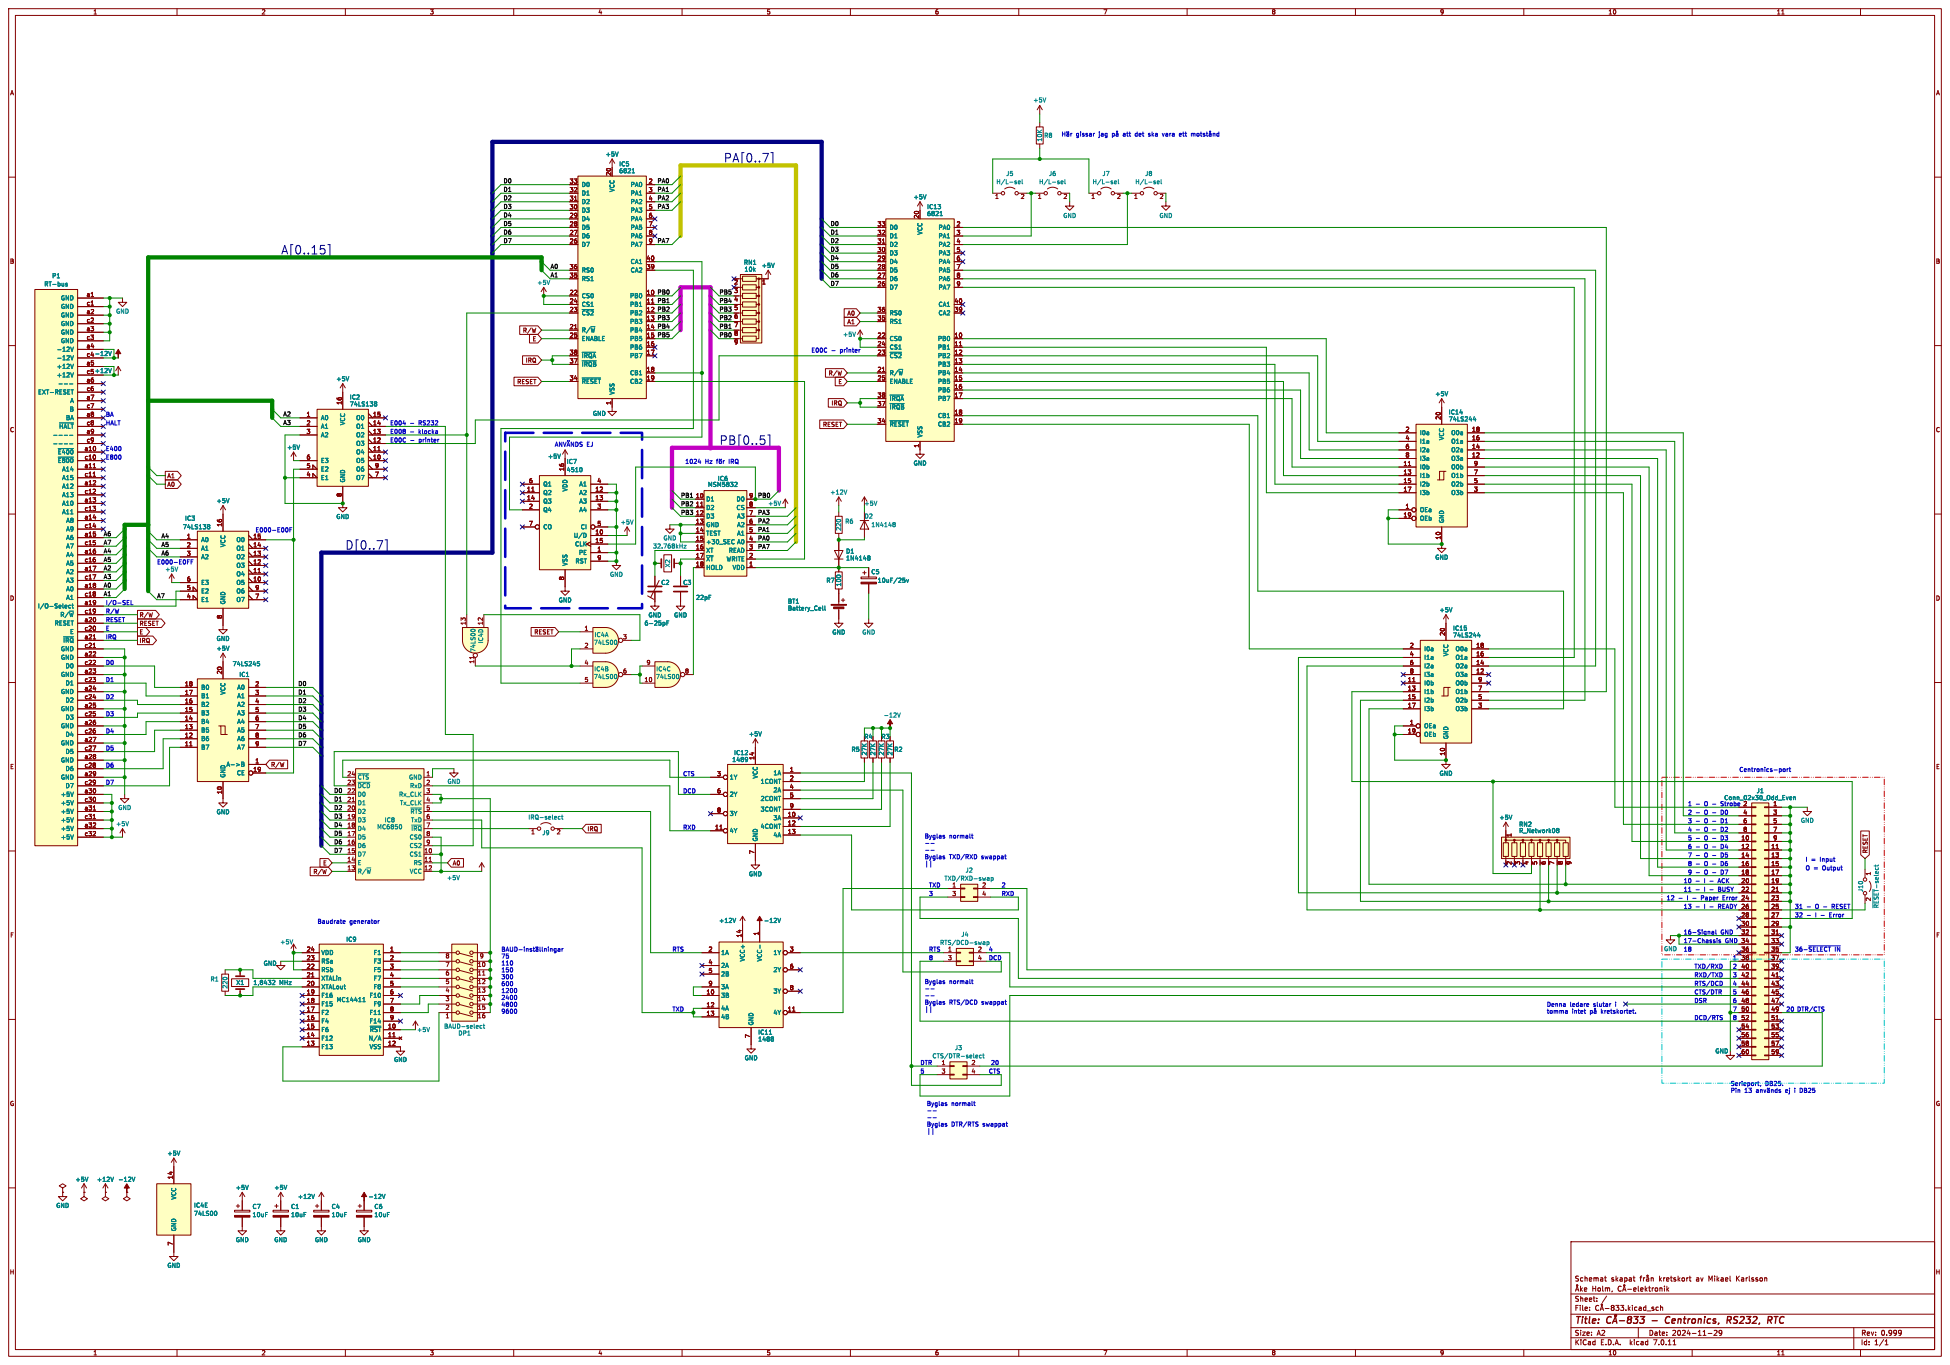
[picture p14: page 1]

þÿHär gissar jag þÿpåatt det ska vara ett þÿmotstånd

--Byglas TXD/RXD swappat

J2 TXD/RXD-swap GND
1488 VCC- 1

31 - O - RESET Denna ledare slutar i tomma intet þÿpåkretskortet.

--Byglas RTS/DCD swappat

--Byglas DTR/RTS swappat

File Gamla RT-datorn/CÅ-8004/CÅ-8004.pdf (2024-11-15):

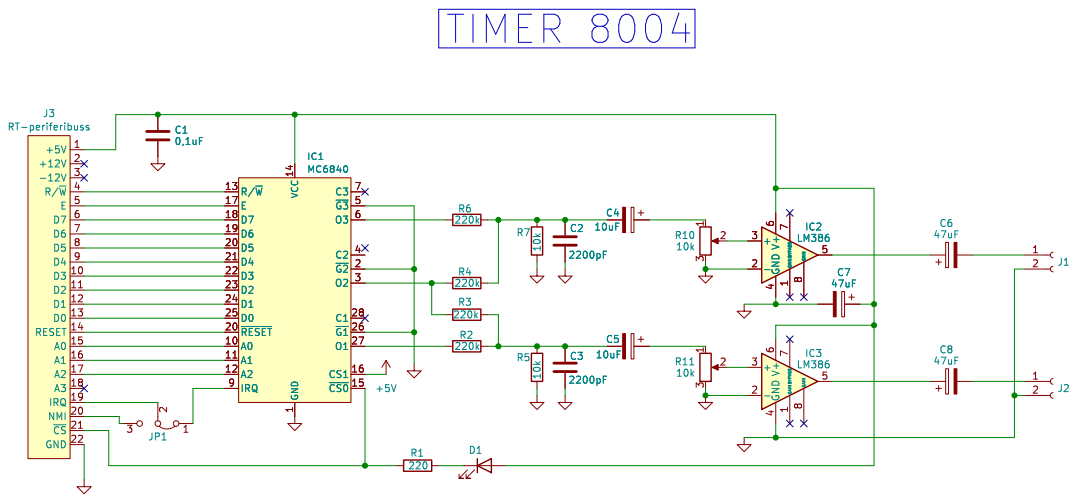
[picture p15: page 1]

Id: 1/1 Title: þÿCÅ-8004 TIMER

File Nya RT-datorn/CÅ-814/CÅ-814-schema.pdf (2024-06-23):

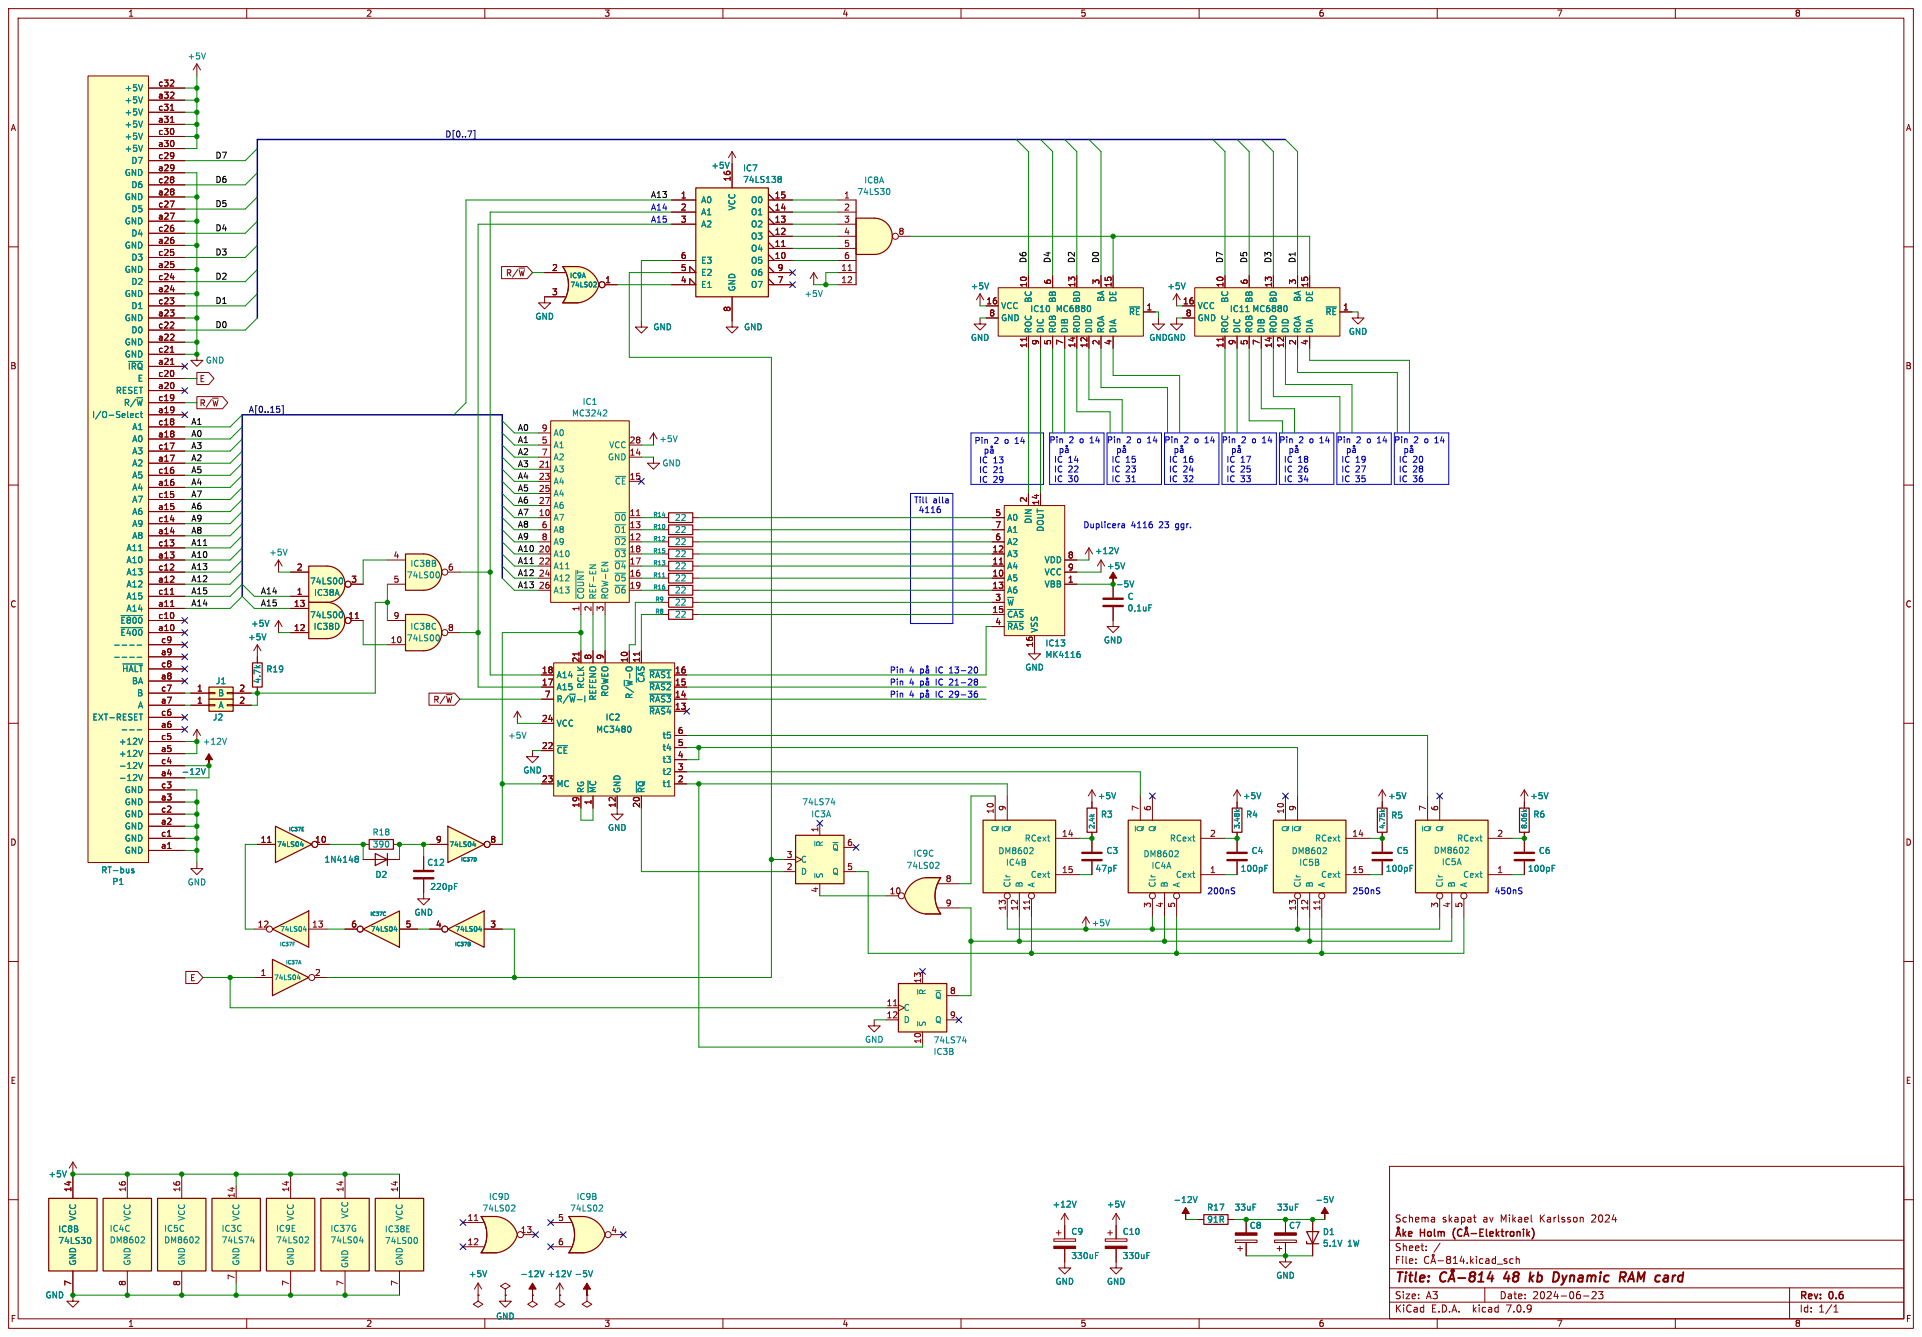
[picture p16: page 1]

2 ~{W} 3 ~{RAS} 4 A0 5 A2 6 A1 7 VDD 8 VCC 9 GND

Id: 1/1 Title: þÿCÅ-81448 kb Dynamic RAM card

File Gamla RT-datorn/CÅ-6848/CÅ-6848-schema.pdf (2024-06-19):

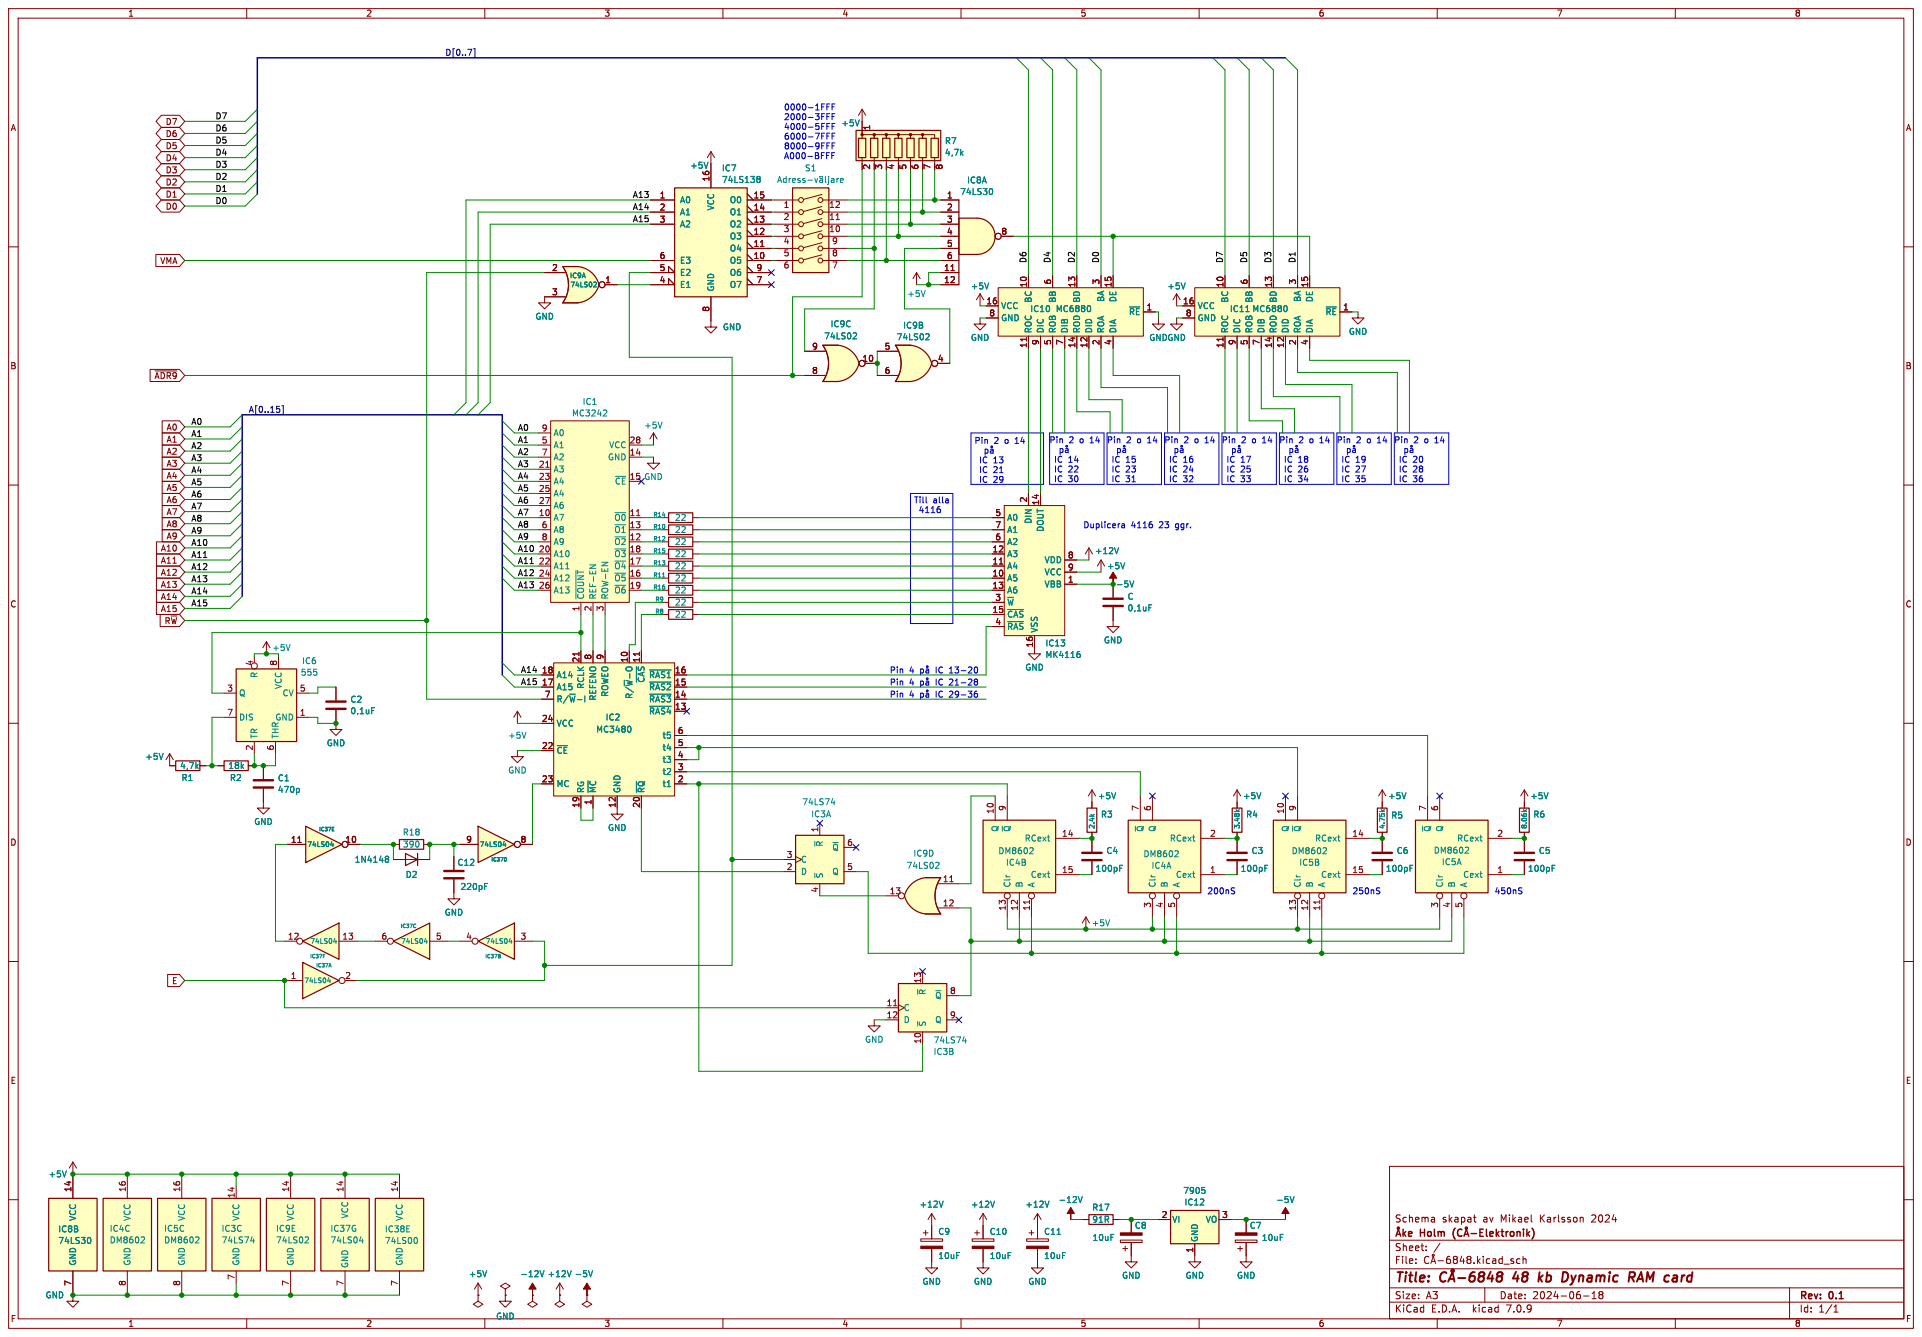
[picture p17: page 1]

IC 34 Pin 4 þÿpåIC 21-28 +5V

IC 35 Pin 4 þÿpåIC 13-20

+5V VCC 14 GND 74LS30 74LS30VCC 14 GND IC8B IC8B | VCC 16 GND IC4C | IC5C | 74LS74 VCC 16 GND IC3C | IC9E 74LS02

File: þÿCÅ-6848.kicad_sch Sheet: / þÿÅkeHolm þÿ(CÅ-Elektronik) Schema skapat av | Mikael | Karlsson 2024

Id: 1/1 Title: þÿCÅ-68488 kb Dynamic RAM card

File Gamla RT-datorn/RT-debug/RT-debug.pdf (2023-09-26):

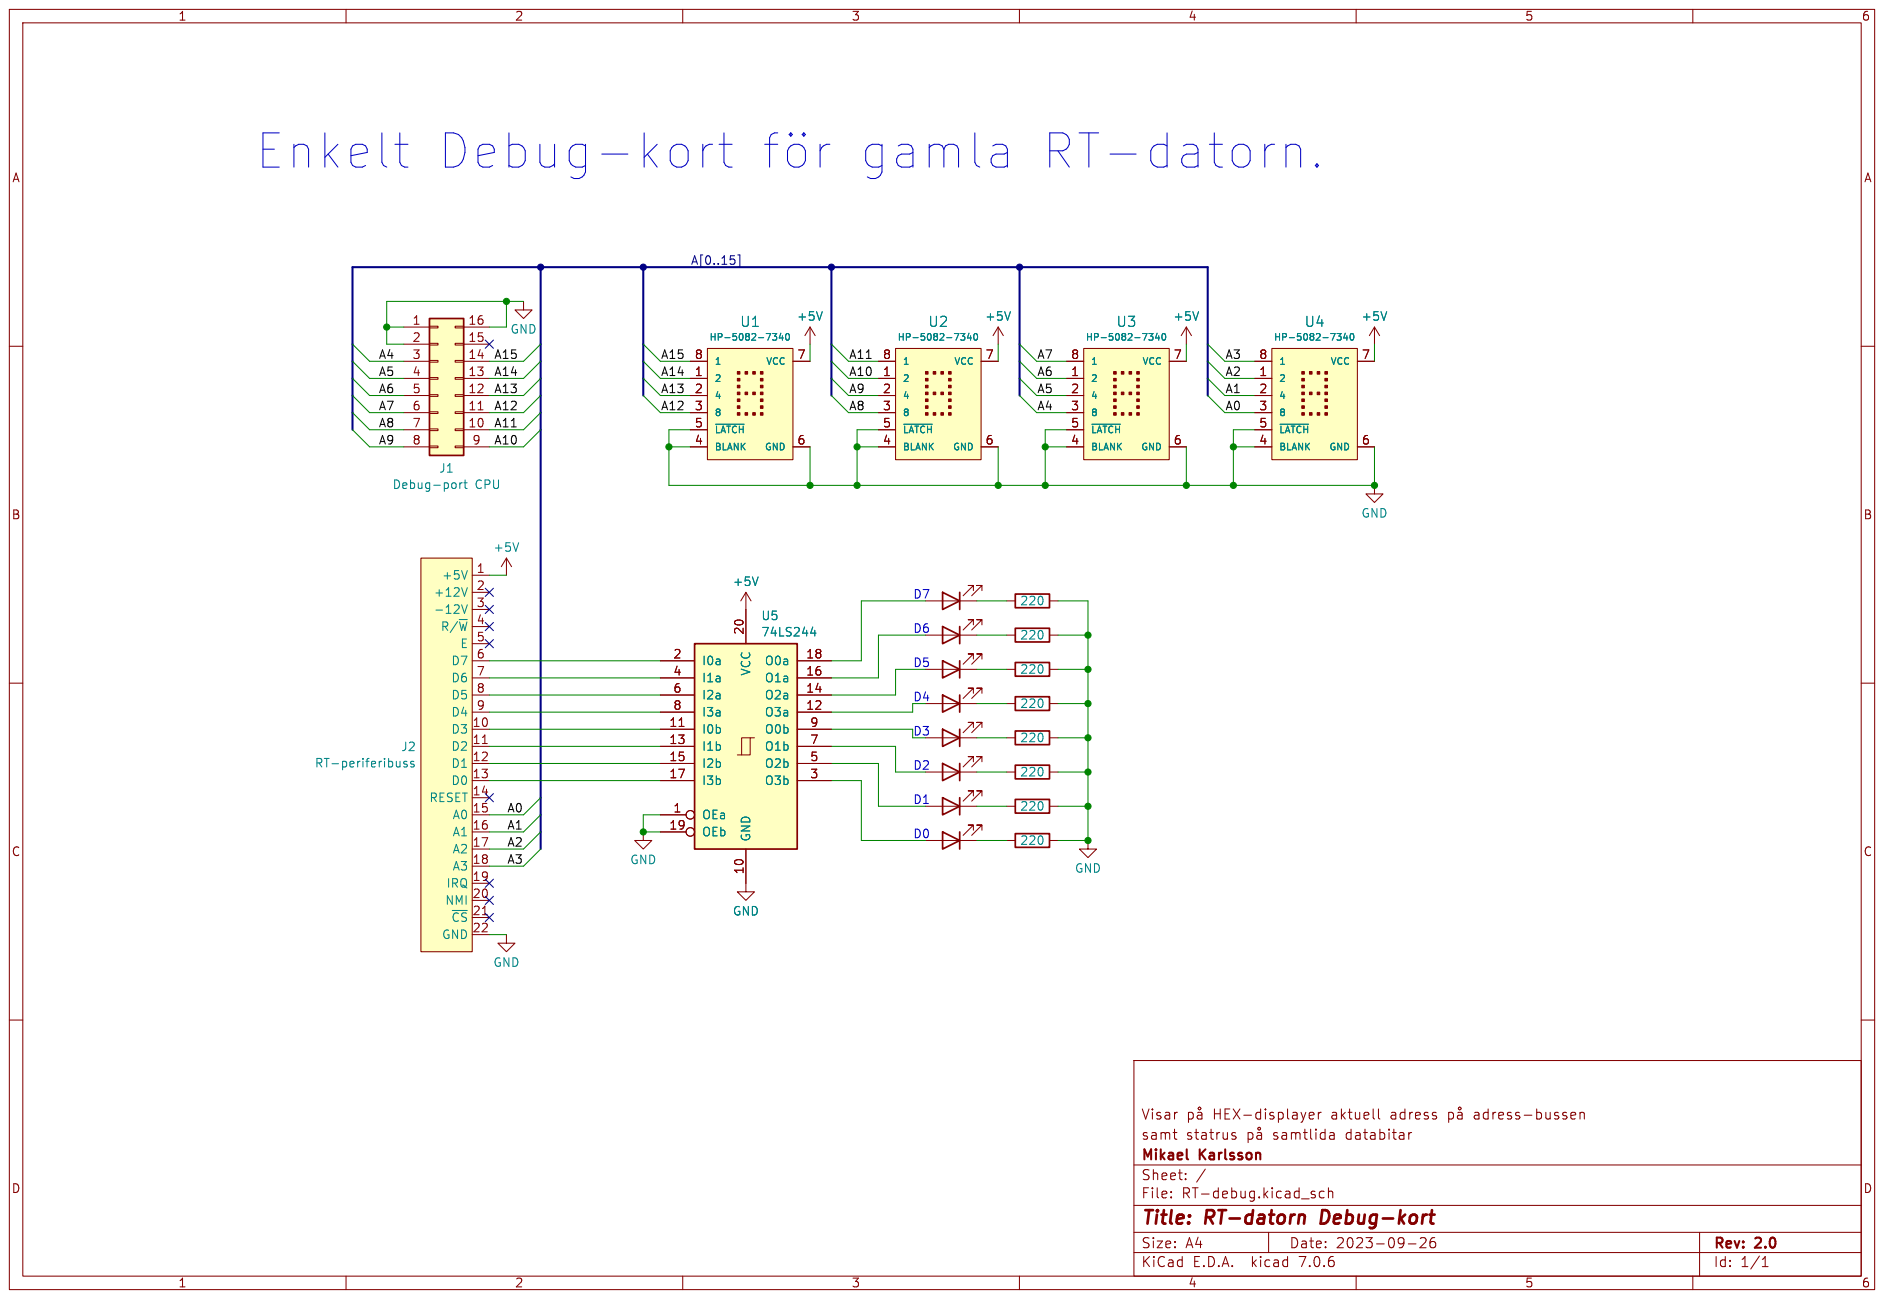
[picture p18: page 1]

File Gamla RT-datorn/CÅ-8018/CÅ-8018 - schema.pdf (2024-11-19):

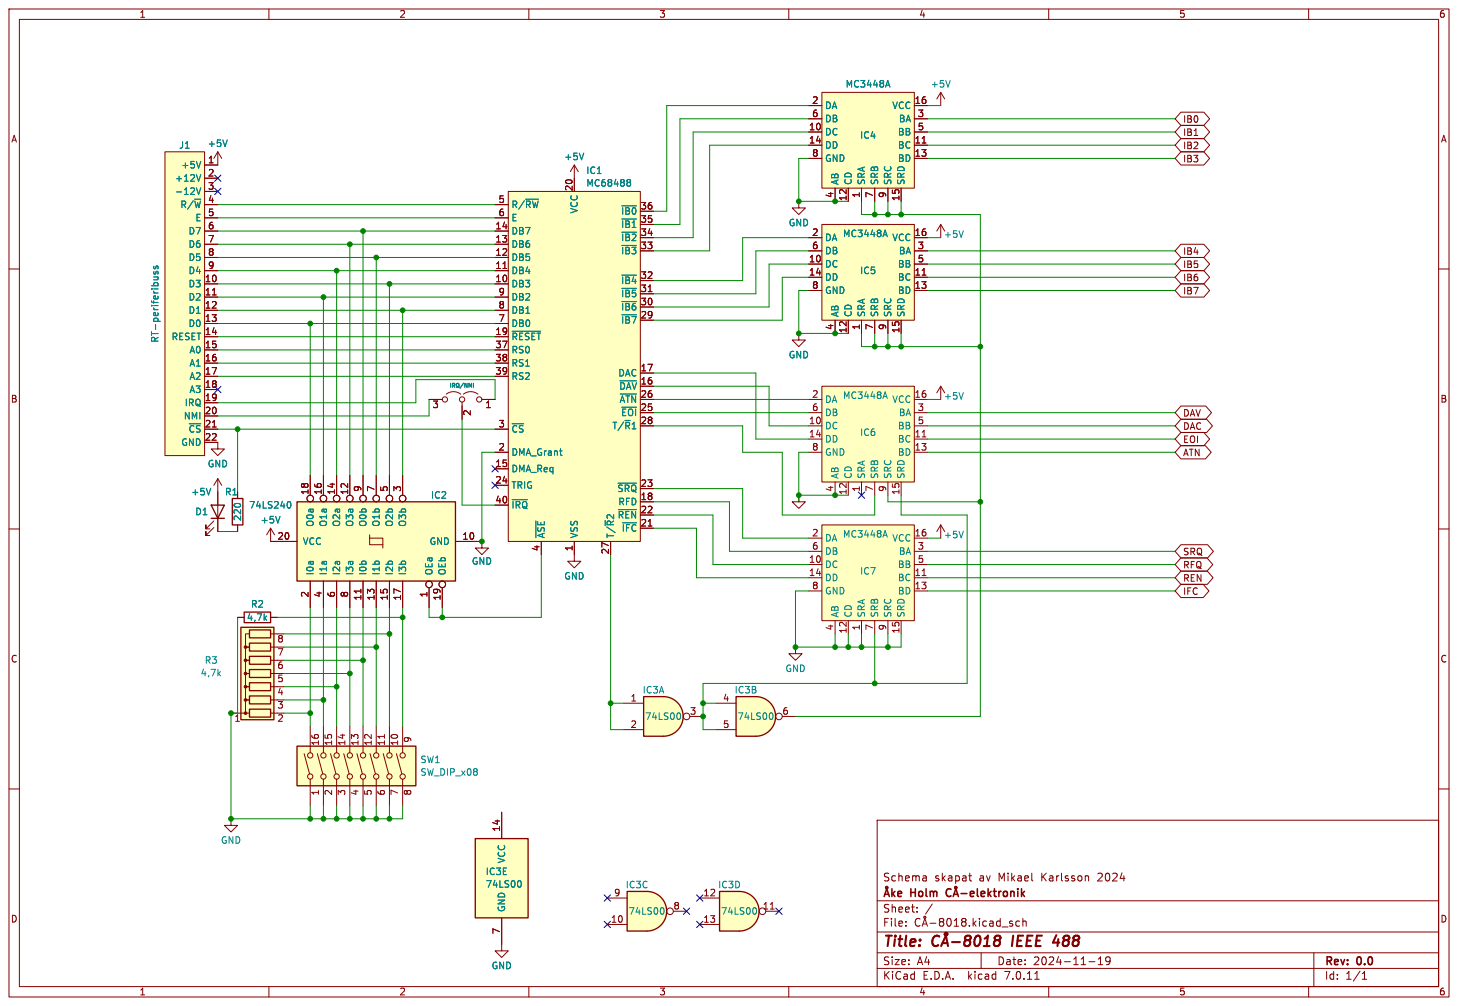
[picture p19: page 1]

Id: 1/1 Title: þÿCÅ-8018 IEEE 488

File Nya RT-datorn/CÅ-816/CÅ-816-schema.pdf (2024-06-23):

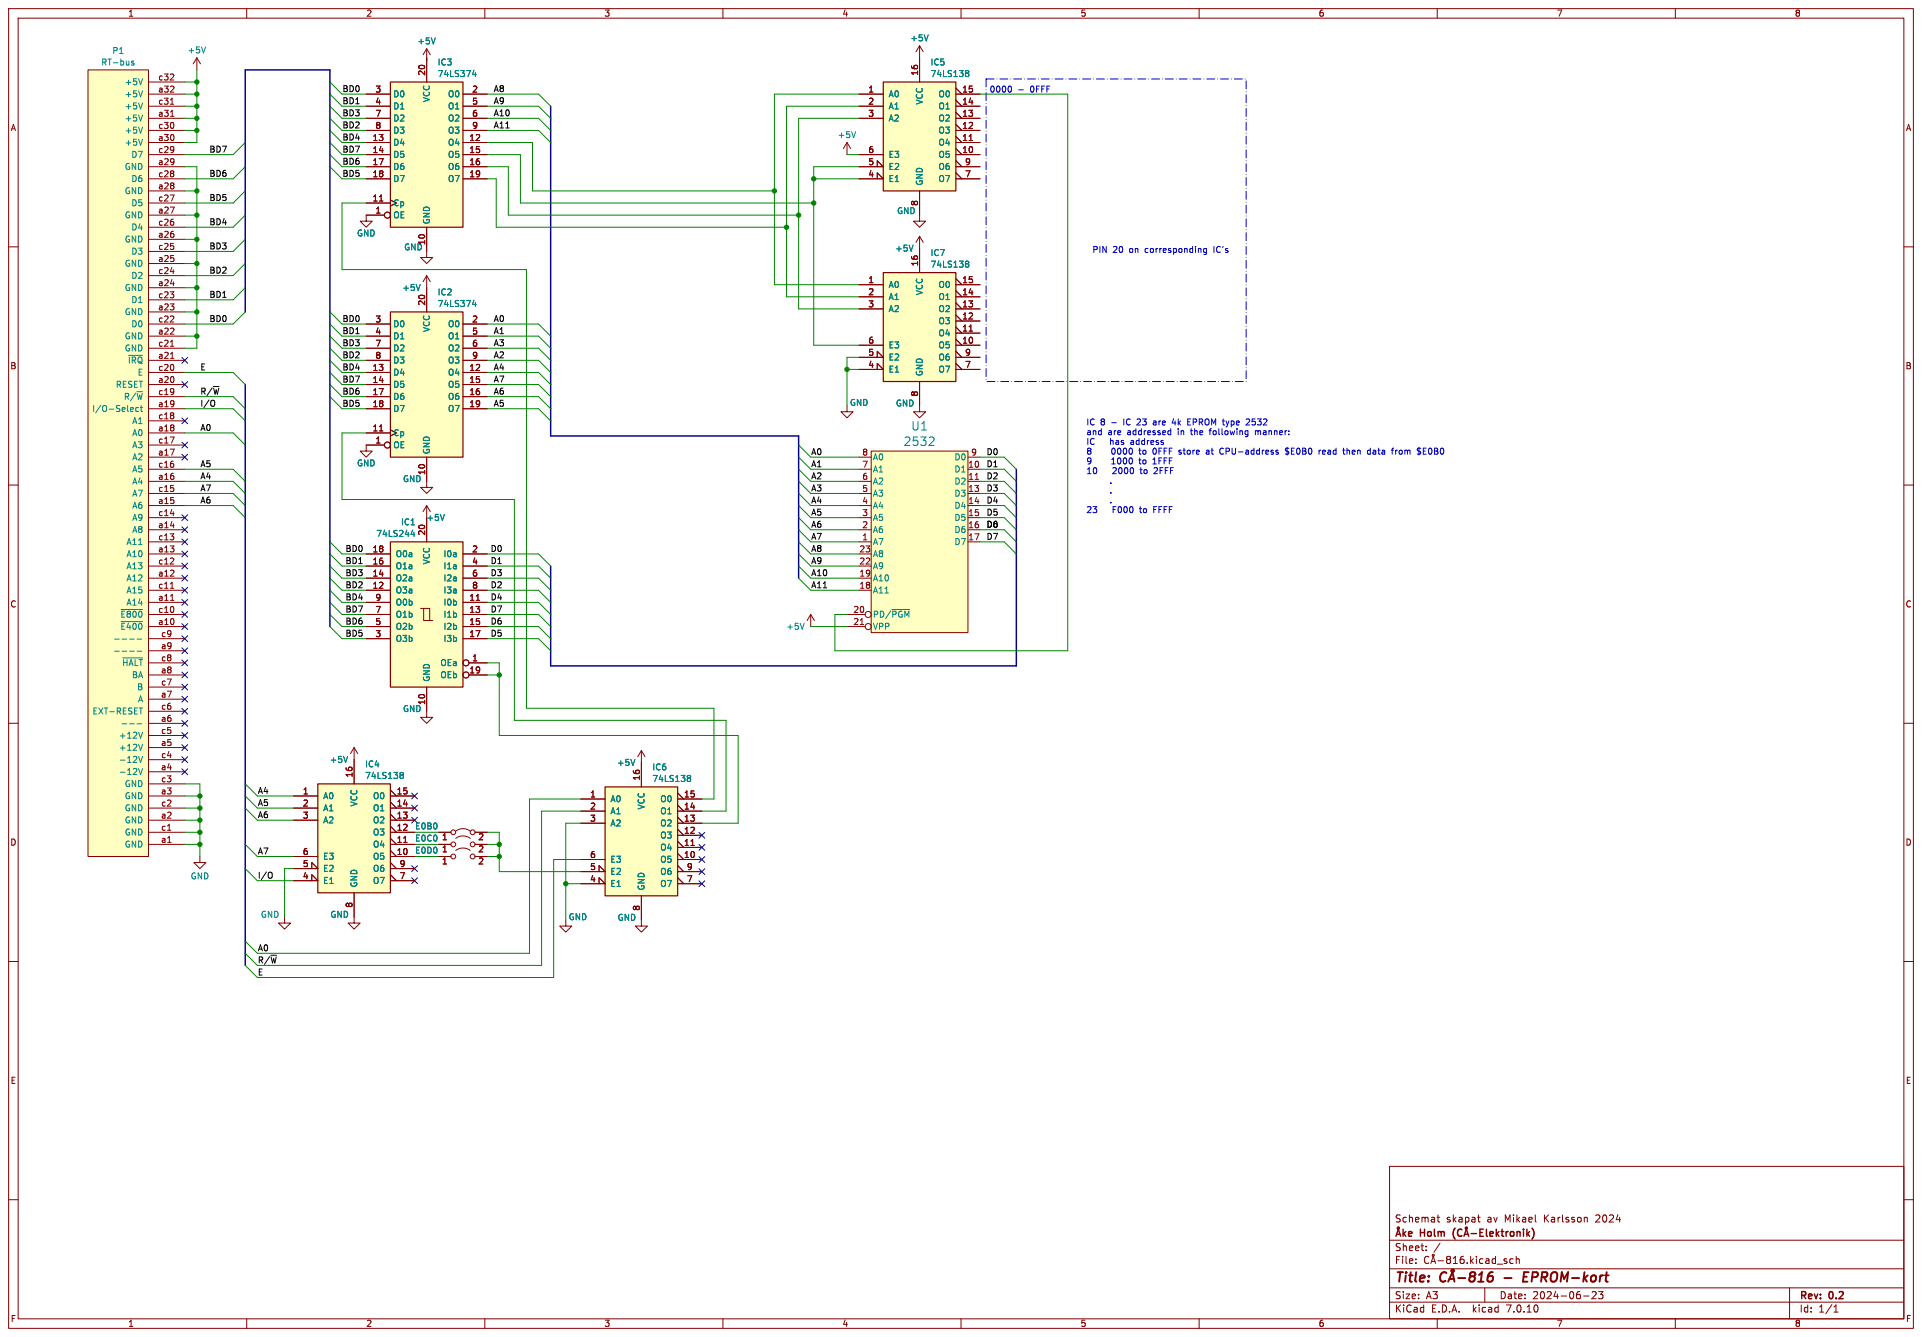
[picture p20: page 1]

IC 8 - IC 23 are 4k EPROM type 2532

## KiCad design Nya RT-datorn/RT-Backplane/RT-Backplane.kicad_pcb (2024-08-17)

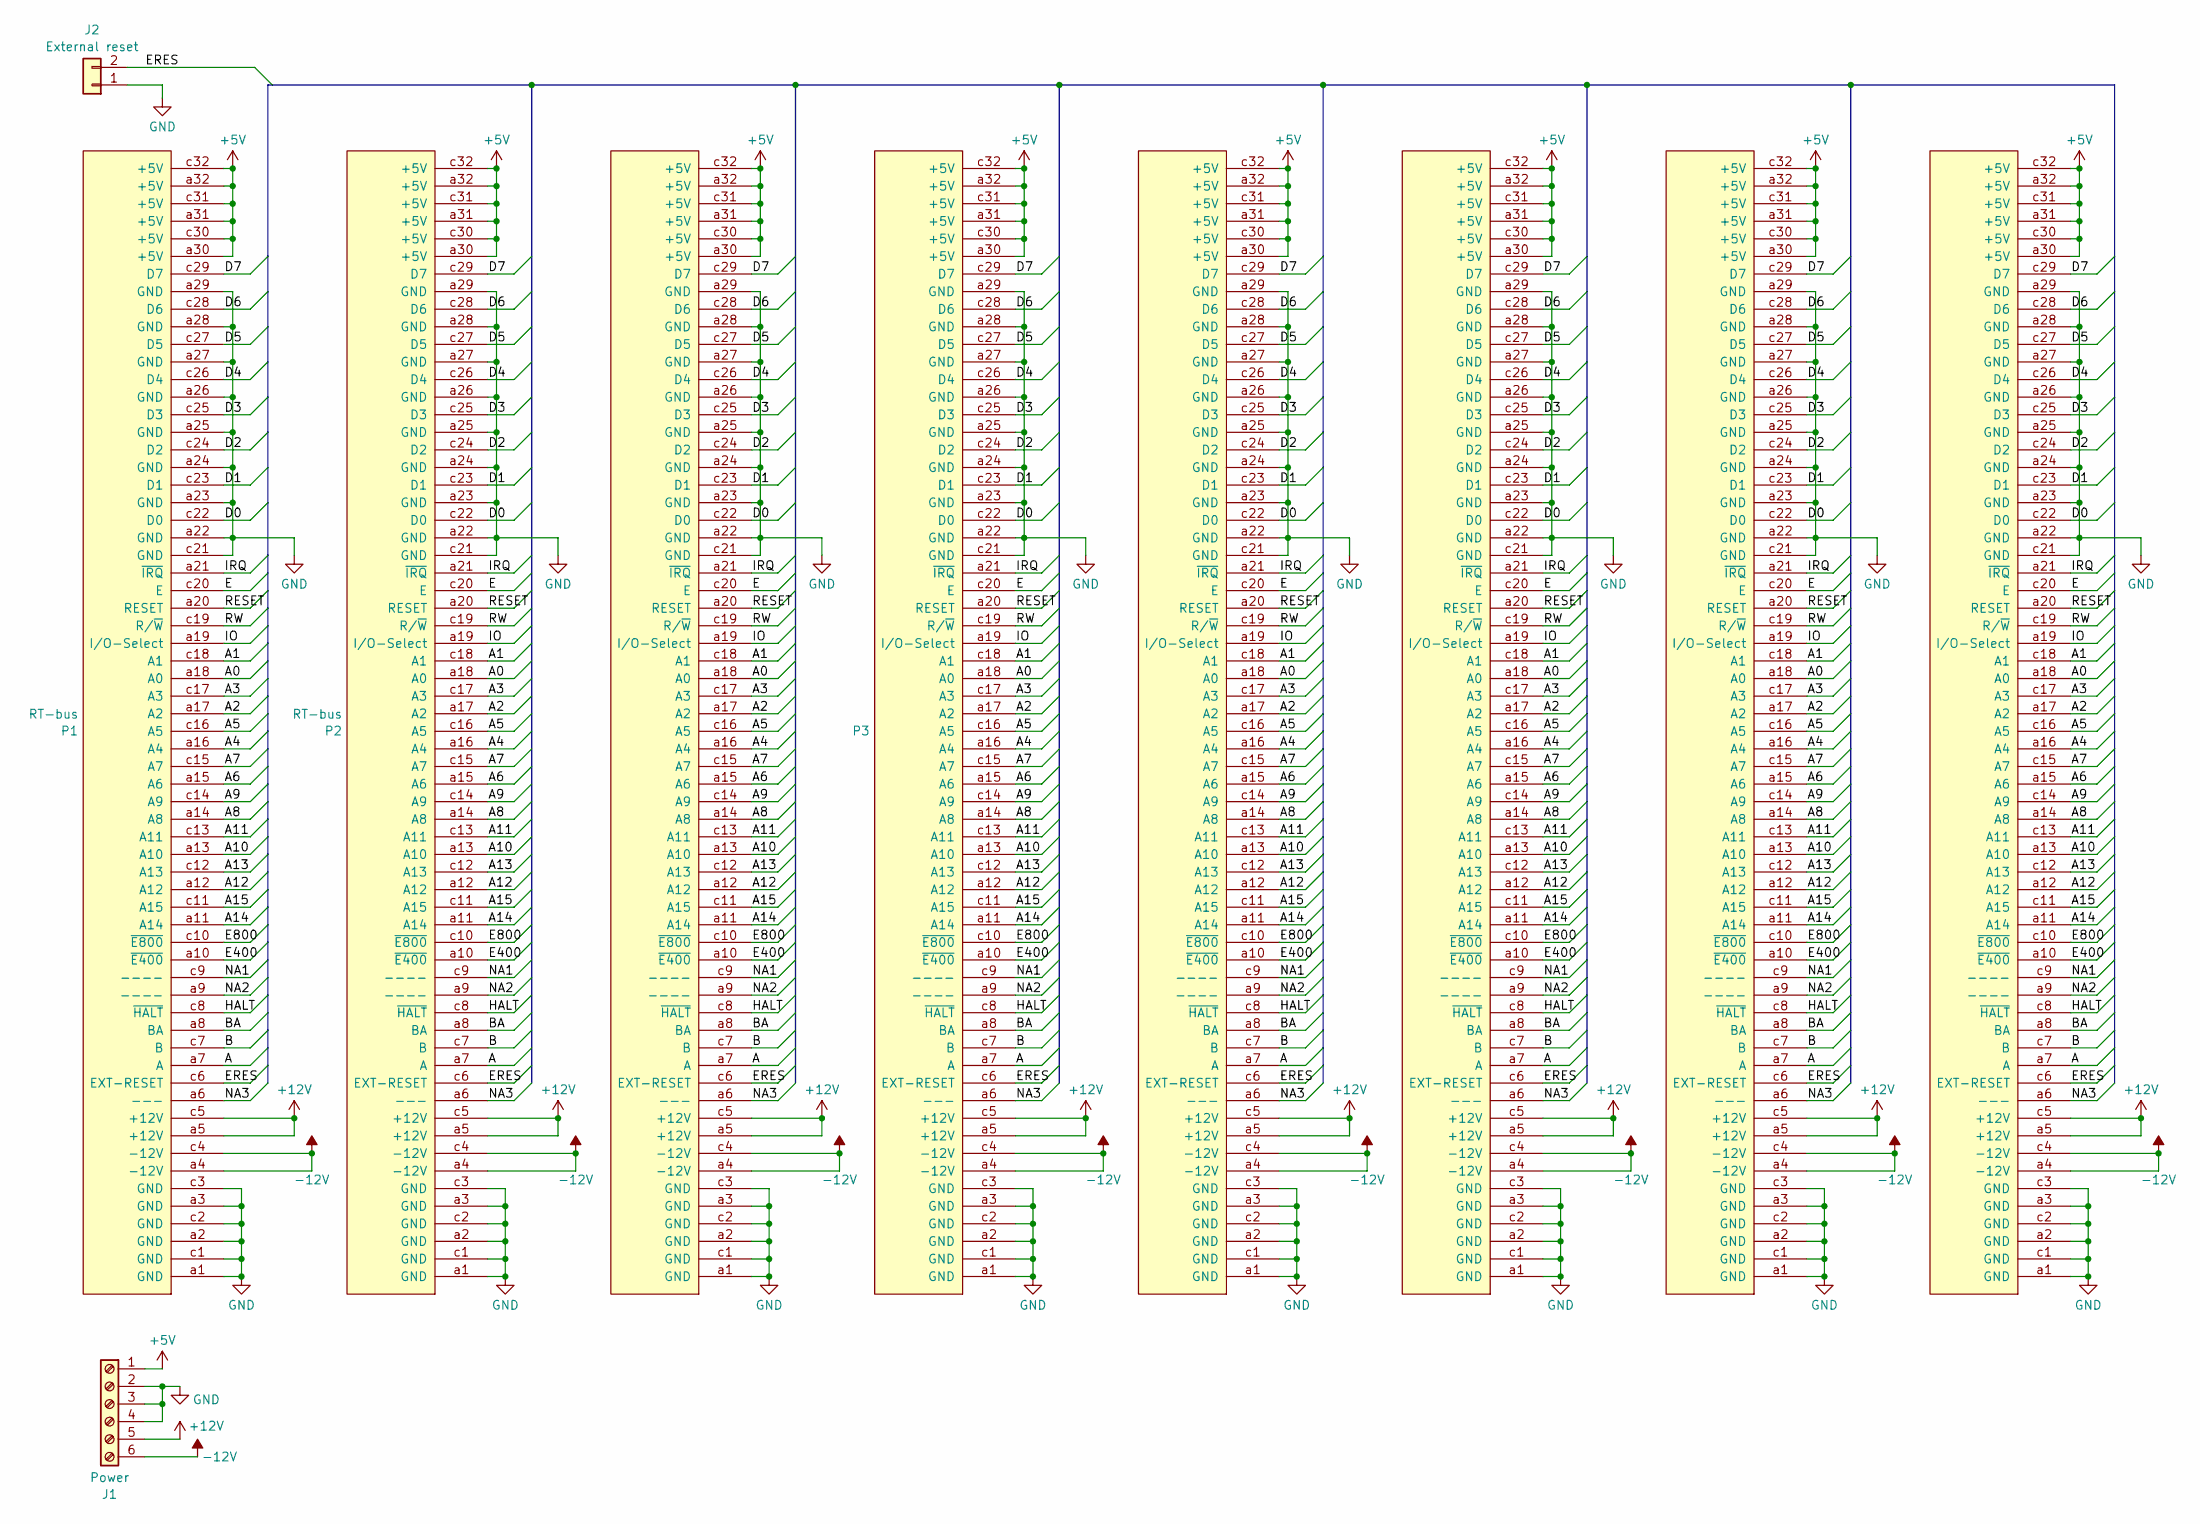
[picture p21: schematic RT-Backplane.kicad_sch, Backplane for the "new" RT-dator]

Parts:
J1: Power; PhoenixContact_MSTBA_2,5_6-G-5,08_1x06_P5.08mm_Horizontal
J2: External reset; PinHeader_1x02_P2.54mm_Vertical
P1, P2, P3, P4, P5, P6, P7, P8: RT-bus; DIN41612_C_2x32_Female_Vertical_THT

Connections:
+5V: J1.1, P1.a30 (+5V), P1.a31 (+5V), P1.a32 (+5V), P1.c30 (+5V), P1.c31 (+5V), P1.c32 (+5V), P2.a30 (+5V), P2.a31 (+5V), P2.a32 (+5V), P2.c30 (+5V), P2.c31 (+5V), P2.c32 (+5V), P3.a30 (+5V), P3.a31 (+5V), P3.a32 (+5V), P3.c30 (+5V), P3.c31 (+5V), P3.c32 (+5V), P4.a30 (+5V), P4.a31 (+5V), P4.a32 (+5V), P4.c30 (+5V), P4.c31 (+5V), P4.c32 (+5V), P5.a30 (+5V), P5.a31 (+5V), P5.a32 (+5V), P5.c30 (+5V), P5.c31 (+5V), P5.c32 (+5V), P6.a30 (+5V), P6.a31 (+5V), P6.a32 (+5V), P6.c30 (+5V), P6.c31 (+5V), P6.c32 (+5V), P7.a30 (+5V), P7.a31 (+5V), P7.a32 (+5V), P7.c30 (+5V), P7.c31 (+5V), P7.c32 (+5V), P8.a30 (+5V), P8.a31 (+5V), P8.a32 (+5V), P8.c30 (+5V), P8.c31 (+5V), P8.c32 (+5V)
+12V: J1.5, P1.a5 (+12V), P1.c5 (+12V), P2.a5 (+12V), P2.c5 (+12V), P3.a5 (+12V), P3.c5 (+12V), P4.a5 (+12V), P4.c5 (+12V), P5.a5 (+12V), P5.c5 (+12V), P6.a5 (+12V), P6.c5 (+12V), P7.a5 (+12V), P7.c5 (+12V), P8.a5 (+12V), P8.c5 (+12V)
-12V: J1.6, P1.a4 (-12V), P1.c4 (-12V), P2.a4 (-12V), P2.c4 (-12V), P3.a4 (-12V), P3.c4 (-12V), P4.a4 (-12V), P4.c4 (-12V), P5.a4 (-12V), P5.c4 (-12V), P6.a4 (-12V), P6.c4 (-12V), P7.a4 (-12V), P7.c4 (-12V), P8.a4 (-12V), P8.c4 (-12V)
/A: P1.a7 (A), P2.a7 (A), P3.a7 (A), P4.a7 (A), P5.a7 (A), P6.a7 (A), P7.a7 (A), P8.a7 (A)
/A0: P1.a18 (A0), P2.a18 (A0), P3.a18 (A0), P4.a18 (A0), P5.a18 (A0), P6.a18 (A0), P7.a18 (A0), P8.a18 (A0)
/A1: P1.c18 (A1), P2.c18 (A1), P3.c18 (A1), P4.c18 (A1), P5.c18 (A1), P6.c18 (A1), P7.c18 (A1), P8.c18 (A1)
/A2: P1.a17 (A2), P2.a17 (A2), P3.a17 (A2), P4.a17 (A2), P5.a17 (A2), P6.a17 (A2), P7.a17 (A2), P8.a17 (A2)
/A3: P1.c17 (A3), P2.c17 (A3), P3.c17 (A3), P4.c17 (A3), P5.c17 (A3), P6.c17 (A3), P7.c17 (A3), P8.c17 (A3)
/A4: P1.a16 (A4), P2.a16 (A4), P3.a16 (A4), P4.a16 (A4), P5.a16 (A4), P6.a16 (A4), P7.a16 (A4), P8.a16 (A4)
/A5: P1.c16 (A5), P2.c16 (A5), P3.c16 (A5), P4.c16 (A5), P5.c16 (A5), P6.c16 (A5), P7.c16 (A5), P8.c16 (A5)
/A6: P1.a15 (A6), P2.a15 (A6), P3.a15 (A6), P4.a15 (A6), P5.a15 (A6), P6.a15 (A6), P7.a15 (A6), P8.a15 (A6)
/A7: P1.c15 (A7), P2.c15 (A7), P3.c15 (A7), P4.c15 (A7), P5.c15 (A7), P6.c15 (A7), P7.c15 (A7), P8.c15 (A7)
/A8: P1.a14 (A8), P2.a14 (A8), P3.a14 (A8), P4.a14 (A8), P5.a14 (A8), P6.a14 (A8), P7.a14 (A8), P8.a14 (A8)
/A9: P1.c14 (A9), P2.c14 (A9), P3.c14 (A9), P4.c14 (A9), P5.c14 (A9), P6.c14 (A9), P7.c14 (A9), P8.c14 (A9)
/A10: P1.a13 (A10), P2.a13 (A10), P3.a13 (A10), P4.a13 (A10), P5.a13 (A10), P6.a13 (A10), P7.a13 (A10), P8.a13 (A10)
/A11: P1.c13 (A11), P2.c13 (A11), P3.c13 (A11), P4.c13 (A11), P5.c13 (A11), P6.c13 (A11), P7.c13 (A11), P8.c13 (A11)
/A12: P1.a12 (A12), P2.a12 (A12), P3.a12 (A12), P4.a12 (A12), P5.a12 (A12), P6.a12 (A12), P7.a12 (A12), P8.a12 (A12)
/A13: P1.c12 (A13), P2.c12 (A13), P3.c12 (A13), P4.c12 (A13), P5.c12 (A13), P6.c12 (A13), P7.c12 (A13), P8.c12 (A13)
/A14: P1.a11 (A14), P2.a11 (A14), P3.a11 (A14), P4.a11 (A14), P5.a11 (A14), P6.a11 (A14), P7.a11 (A14), P8.a11 (A14)
/A15: P1.c11 (A15), P2.c11 (A15), P3.c11 (A15), P4.c11 (A15), P5.c11 (A15), P6.c11 (A15), P7.c11 (A15), P8.c11 (A15)
/B: P1.c7 (B), P2.c7 (B), P3.c7 (B), P4.c7 (B), P5.c7 (B), P6.c7 (B), P7.c7 (B), P8.c7 (B)
/BA: P1.a8 (BA), P2.a8 (BA), P3.a8 (BA), P4.a8 (BA), P5.a8 (BA), P6.a8 (BA), P7.a8 (BA), P8.a8 (BA)
/D0: P1.c22 (D0), P2.c22 (D0), P3.c22 (D0), P4.c22 (D0), P5.c22 (D0), P6.c22 (D0), P7.c22 (D0), P8.c22 (D0)
/D1: P1.c23 (D1), P2.c23 (D1), P3.c23 (D1), P4.c23 (D1), P5.c23 (D1), P6.c23 (D1), P7.c23 (D1), P8.c23 (D1)
/D2: P1.c24 (D2), P2.c24 (D2), P3.c24 (D2), P4.c24 (D2), P5.c24 (D2), P6.c24 (D2), P7.c24 (D2), P8.c24 (D2)
/D3: P1.c25 (D3), P2.c25 (D3), P3.c25 (D3), P4.c25 (D3), P5.c25 (D3), P6.c25 (D3), P7.c25 (D3), P8.c25 (D3)
/D4: P1.c26 (D4), P2.c26 (D4), P3.c26 (D4), P4.c26 (D4), P5.c26 (D4), P6.c26 (D4), P7.c26 (D4), P8.c26 (D4)
/D5: P1.c27 (D5), P2.c27 (D5), P3.c27 (D5), P4.c27 (D5), P5.c27 (D5), P6.c27 (D5), P7.c27 (D5), P8.c27 (D5)
/D6: P1.c28 (D6), P2.c28 (D6), P3.c28 (D6), P4.c28 (D6), P5.c28 (D6), P6.c28 (D6), P7.c28 (D6), P8.c28 (D6)
/D7: P1.c29 (D7), P2.c29 (D7), P3.c29 (D7), P4.c29 (D7), P5.c29 (D7), P6.c29 (D7), P7.c29 (D7), P8.c29 (D7)
/E: P1.c20 (E), P2.c20 (E), P3.c20 (E), P4.c20 (E), P5.c20 (E), P6.c20 (E), P7.c20 (E), P8.c20 (E)
/E400: P1.a10 (~E400), P2.a10 (~E400), P3.a10 (~E400), P4.a10 (~E400), P5.a10 (~E400), P6.a10 (~E400), P7.a10 (~E400), P8.a10 (~E400)
/E800: P1.c10 (~E800), P2.c10 (~E800), P3.c10 (~E800), P4.c10 (~E800), P5.c10 (~E800), P6.c10 (~E800), P7.c10 (~E800), P8.c10 (~E800)
/ERES: J2.2, P1.c6 (EXT-RESET), P2.c6 (EXT-RESET), P3.c6 (EXT-RESET), P4.c6 (EXT-RESET), P5.c6 (EXT-RESET), P6.c6 (EXT-RESET), P7.c6 (EXT-RESET), P8.c6 (EXT-RESET)
/HALT: P1.c8 (~HALT), P2.c8 (~HALT), P3.c8 (~HALT), P4.c8 (~HALT), P5.c8 (~HALT), P6.c8 (~HALT), P7.c8 (~HALT), P8.c8 (~HALT)
/IO: P1.a19 (I/O-Select), P2.a19 (I/O-Select), P3.a19 (I/O-Select), P4.a19 (I/O-Select), P5.a19 (I/O-Select), P6.a19 (I/O-Select), P7.a19 (I/O-Select), P8.a19 (I/O-Select)
/IRQ: P1.a21 (~IRQ), P2.a21 (~IRQ), P3.a21 (~IRQ), P4.a21 (~IRQ), P5.a21 (~IRQ), P6.a21 (~IRQ), P7.a21 (~IRQ), P8.a21 (~IRQ)
/NA1: P1.c9 (----), P2.c9 (----), P3.c9 (----), P4.c9 (----), P5.c9 (----), P6.c9 (----), P7.c9 (----), P8.c9 (----)
/NA2: P1.a9 (----), P2.a9 (----), P3.a9 (----), P4.a9 (----), P5.a9 (----), P6.a9 (----), P7.a9 (----), P8.a9 (----)
/NA3: P1.a6 (---), P2.a6 (---), P3.a6 (---), P4.a6 (---), P5.a6 (---), P6.a6 (---), P7.a6 (---), P8.a6 (---)
/RESET: P1.a20 (RESET), P2.a20 (RESET), P3.a20 (RESET), P4.a20 (RESET), P5.a20 (RESET), P6.a20 (RESET), P7.a20 (RESET), P8.a20 (RESET)
/RW: P1.c19 (R/~W), P2.c19 (R/~W), P3.c19 (R/~W), P4.c19 (R/~W), P5.c19 (R/~W), P6.c19 (R/~W), P7.c19 (R/~W), P8.c19 (R/~W)
GND: J1.2, J1.3, J1.4, J2.1, P1.a1 (GND), P1.a2 (GND), P1.a3 (GND), P1.a22 (GND), P1.a23 (GND), P1.a24 (GND), P1.a25 (GND), P1.a26 (GND), P1.a27 (GND), P1.a28 (GND), P1.a29 (GND), P1.c1 (GND), P1.c2 (GND), P1.c3 (GND), P1.c21 (GND), P2.a1 (GND), P2.a2 (GND), P2.a3 (GND), P2.a22 (GND), P2.a23 (GND), P2.a24 (GND), P2.a25 (GND), P2.a26 (GND), P2.a27 (GND), P2.a28 (GND), P2.a29 (GND), P2.c1 (GND), P2.c2 (GND), P2.c3 (GND), P2.c21 (GND), P3.a1 (GND), P3.a2 (GND), P3.a3 (GND), P3.a22 (GND), P3.a23 (GND), P3.a24 (GND), P3.a25 (GND), P3.a26 (GND), P3.a27 (GND), P3.a28 (GND), P3.a29 (GND), P3.c1 (GND), P3.c2 (GND), P3.c3 (GND), P3.c21 (GND), P4.a1 (GND), P4.a2 (GND), P4.a3 (GND), P4.a22 (GND), P4.a23 (GND), P4.a24 (GND), P4.a25 (GND), P4.a26 (GND), P4.a27 (GND), P4.a28 (GND), P4.a29 (GND), P4.c1 (GND), P4.c2 (GND), P4.c3 (GND), P4.c21 (GND), P5.a1 (GND), P5.a2 (GND), P5.a3 (GND), P5.a22 (GND), P5.a23 (GND), P5.a24 (GND), P5.a25 (GND), P5.a26 (GND), P5.a27 (GND), P5.a28 (GND), P5.a29 (GND), P5.c1 (GND), P5.c2 (GND), P5.c3 (GND), P5.c21 (GND), P6.a1 (GND), P6.a2 (GND), P6.a3 (GND), P6.a22 (GND), P6.a23 (GND), P6.a24 (GND), P6.a25 (GND), P6.a26 (GND), P6.a27 (GND), P6.a28 (GND), P6.a29 (GND), P6.c1 (GND), P6.c2 (GND), P6.c3 (GND), P6.c21 (GND), P7.a1 (GND), P7.a2 (GND), P7.a3 (GND), P7.a22 (GND), P7.a23 (GND), P7.a24 (GND), P7.a25 (GND), P7.a26 (GND), P7.a27 (GND), P7.a28 (GND), P7.a29 (GND), P7.c1 (GND), P7.c2 (GND), P7.c3 (GND), P7.c21 (GND), P8.a1 (GND), P8.a2 (GND), P8.a3 (GND), P8.a22 (GND), P8.a23 (GND), P8.a24 (GND), P8.a25 (GND), P8.a26 (GND), P8.a27 (GND), P8.a28 (GND), P8.a29 (GND), P8.c1 (GND), P8.c2 (GND), P8.c3 (GND), P8.c21 (GND)

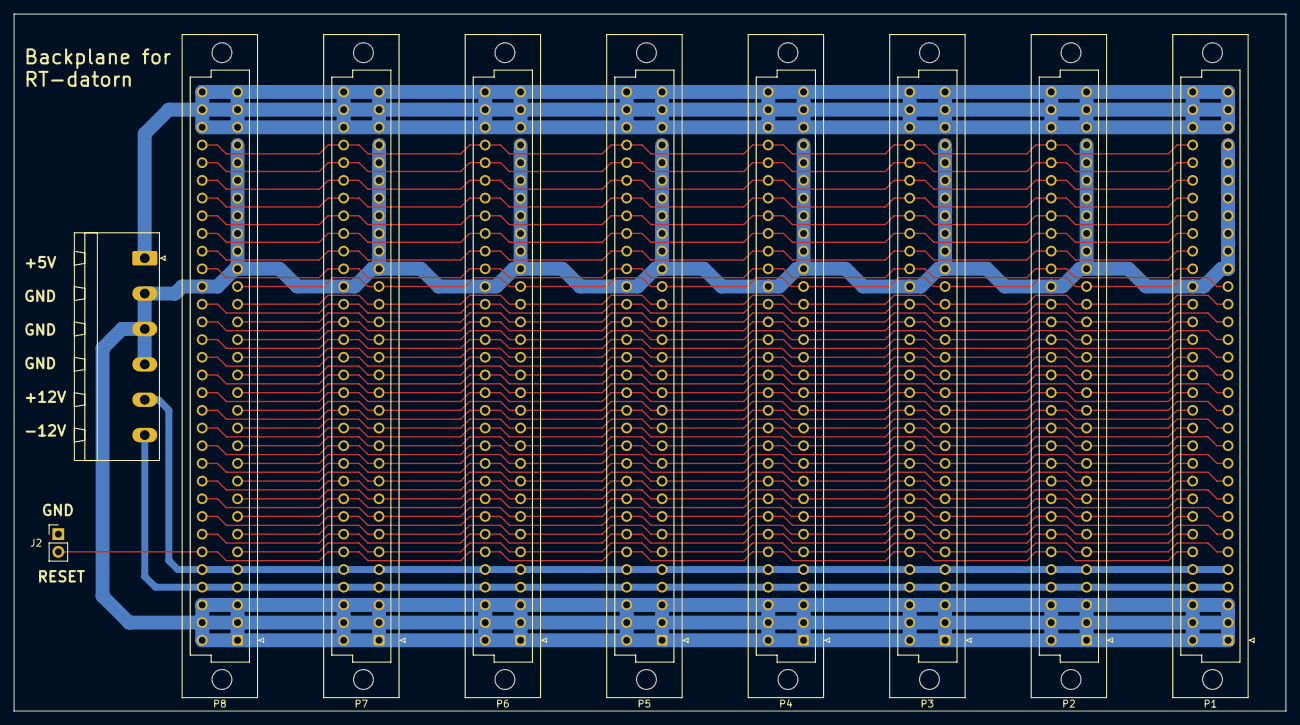
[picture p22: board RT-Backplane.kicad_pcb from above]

Board: 2 copper layers, 182.6 x 100.1 mm, 10 parts (0 on the bottom side), 43 nets.

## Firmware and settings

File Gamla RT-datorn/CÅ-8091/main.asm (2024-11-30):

* 
*  ( MAIN.CMD )
*
* AV TBL 80-07-02 REV 1
*
* BESKRIVNING:
* -----------
*
*   MAIN ÄR ETT KOMMANDO UNDER FLEX 9.
*   FUNKTIONEN BESTÅR I ATT AVKÄNNA ÅTTA
*   OMKOPPLARE ANSLUTNA TILL EN PIA OCH
*   TÄNDA RESPEKTIVE SLÄCKA ÅTTA
*   LYSDIODER SÅ ATT DE SPEGLAR OMKOPPLARNAS
*   STATUS. DÅ SAMTLIGA ÅTTA OMKOPPLARE
*   ÄR TILL AVSLUTAS MAIN. UTSKRIFTEN "KLART"
*   SKRIVS UT OCH KONTROLLEN ÅTERGÅR TILL FLEX.
*
*
* EXTERNA REFERENSER:
* ------------------
PSTRNG  EQU     $CD1E     SKRIV UT TEXTSTRÄNG (FLEX).
WARMS   EQU     $CD03     ÅTERGÅNGSPUNKT I FLEX
*
* LOKALA REFERENSER
* -----------------
*
PSTART  EQU     $C100     PROGRAMMETS START ADRESS.
PIAACR  EQU     $E061     KONTROLLREGISTER SIDA A
PIABCR  EQU     $E063     KONTROLLREGISTER SIDA B
PIAADR  EQU     $E060     DATA REGISTER SIDA A
PIABDR  EQU     $E062     DATA REGISTER SIDA B
*
        ORG     PSTART    GE ASSEMBLERN STARTADRESSEN
START   BRA     STRT      HOPPA ÖVER NÄSTA BYTE
        FCB     1         VERSIONSNUMMER. FLEX KONVENTION
STRT    JSR     INIT      SÄTT UPP PIAN
MAIN10  JSR     OKTEST    TESTA OMKOPPLARNA
        BEQ     SLUT      TESTA OM AVSLUTA
        JSR     LIGHT     TÄND LYSDIODEN
        BRA     MAIN10
*
SLUT    JSR     FINISH    AVSLUTA
        JMP     WARMS
*
* ****************************
*                            *
*  SUBRUTIN INIT             *
*                            *
******************************
*
* BESKRIVNING:
* -----------
*   DENNA RUTIN SÄTTER UPP EN PIA MED
*   A-SIDAN SOM ÅTTA INGÅNGAR.
*   B-SIDAN SOM ÅTTA UTGÅNGAR.
*
* INDATA:
* ------
*  INGA
*
* UTDATA:
* ------
*  INGA
*
INIT    EQU     *
        CLRA              A = 0000 0000
        STA     PIAACR    VÄLJ DATARIKTNINGSREGISTRET
        STA     PIABCR    VÄLJ DATARIKTNINGSREGISTRET
        STA     PIAADR    8 INGÅNGAR PÅ A-SIDAN
        COMA              A = 1111 1111
        STA     PIABDR    8 UTGÅNGAR PÅ B-SIDAN
        LDA     #$04      ÖPPNA FÖR DATA TRANSFER
        STA     PIAACR    STÄNG RIKTNINGSREG
        STA     PIABCR          -"-
        RTS
*
*
***************************************
*                                     *
*  SUBRUTIN OKTEST                    *
*                                     *
***************************************
*
* BESKRIVNING:
*   DENNA RUTIN LÄSER AV LÄGET PÅ
*   OMKOPPLARNA 1-8. TILLSTÅNDET
*   LEVERERAS I B-ACC. BIT 0 MOTSVARAR
*   OMKOPPLARE NR 0. BITEN ÄR 1
*   OM OMKOPPLAREN ÄR TILL.
*
*
* INDATA: 
*  INGA
*
* UTDATA:
*
*  A-ACC BITMÖNSTER FÖR OMKOPPLARNA.
*  B-ACC 0 OM ALLA OMKOPPLARE I TILLÄGE.
*       1 I ÖVRIGA FALL
*
OKTEST  EQU     *
        CLRB              RETURFLAGGAN
        LDA     PIAADR    LÄS TILLSTÅNDET
        CMPA    #$FF      ÄR ALLA TILL?
        BEQ     OKT100
        INCB    B=1 EJ ALLA I TILL LÄGE
        RTS
*
OKT100  TSTB              B=0 8 TILL
        RTS
*
*
******************************
*                            *
*  SUBRUTIN LIGHT            *
*                            *
******************************
*
* BESKRIVNING:
* -----------
*    SUBRUTIN FÖR ATT TÄNDA LYSDIODERNA ANSLUTNA       
*    TILL EN PIA. 8 DIODER ÄR ANSLUTNA, VILKEN
*    SOM SKA TÄNDAS ANGES I INDATA.
*
* INDATA:
* ------
*   A-ACC BITMÖNSTER FÖR TÄNDANDE AV
*         LYSDIODERNA 1-8
*
* UTDATA:
* ------
*  INGA
*
LIGHT   EQU     *
        STA     PIABDR    TÄND DIODERNA
        RTS
*
*
*****************************
*                           *
*  SUBRUTIN FINISH          *
*                           *
*****************************
*
* BESKRIVNING:
* -----------
*  SUBRUTIN FÖR ATT SKRIVA UT TEXTEN
*  "KLART" PÅ BILDSKÄRMEN.
*
* INDATA:
* ------
*  INGA
*
* UTDATA:
* ------
*  INGA
*
* ANVÄNDA RUTINER:
* ---------------
*   PSTRNG  FLEX STRÄNGUTSKRIVARE
*
FINISH  EQU     *
        LDX     #TEXT01   "KLART"
        JSR     PSTRNG
        RTS
*
TEXT01  FCC     "KLART"   ASCII TECKEN
        FCB     $D,$A     CR+LF
        FCB     4         EOT
*
*
        END     START

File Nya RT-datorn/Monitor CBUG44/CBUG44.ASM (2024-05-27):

        NAM    CBUG4.4
FILCHR  TEXT   $FF       * TA BORT OM ASMB SKA ANV[NDAS
*
* EPROM MONITOR OCH TERMINALPROGRAM
*
* COPYRIGHT C]-ELEKTRONIK AB
*           BOX 2010
*           135 02 TYRES\  SWEDEN
*
*
* AV ]KE HOLM 1983-01-04  :45
* REV 3 831108
*
* MODIFIERAT AV MIKAEL KARLSSON
* 2024-05-06
* REV 4
*
* COMMANDS IN CBUG4.3
*
* @ VARMSTART I FLEX 9.0
* B DISPLAY BREAKPOINTS
* C CONTINUE
* D DUMPA I HEX OCH ASCII 16 BYTES/RAD
* E EXTENDED INSTRUKTIONSS\KNING
* F G] TILL MINIDISK-BOOT F\R FLEX 9.0
* G G] TILL PROGRAMADRESS OCH EXEKVERA
* H BER[KNA CHECKSUMMA AAAA-BBBB
* I [NDRA REGISTREN P] ANV[NDARSTACKEN
* J G] TILL SUBRUTIN OCH SKRIV UT REGISTREN
* K KOPIERA MINNESINNEH]LL
* L LADDA FLEX 9.6 FR]N EPROM
* M MINNESMANIPULERING
* O FYLL ETT VISST MINNESBLOCK MED EN BYTE
* PL LADDA FR]N PROMKORT
* PH BER[KNA CHECKSUMMA P] PROMKORT
* PR LOOP P] PROMKORT
* Q M[T RAM-STORLEKEN
* R PRINTA REGISTREN
* S S\K 2 BYTES ADRESS
* U TA BORT BREAKPOINTS
* V S[TT IN BREAKPOINTS MAX 5 ST
* W MINNESTEST
* X LADDA FLEX 9.1 FR]N EPROM-KORT 836
* Y VERIFIERING
* Z DUMPA I HEX OCH ASCII 16 BYTES/RAD P] PRINTERN
*
*
****************************************
*
* PORTAR OCH PERIFERIKRETSAR
*
****************************************
*
* KORT C]-813B
*
PCIDR   EQU    $E000     SERIEKRETS 2651
PCISR   EQU    $E001
PCIMR   EQU    $E002
PCICR   EQU    $E003
*
KLOCKA  EQU    $E008
*   PA0-3 UT ADRESSVAL
*   PA7   UT 1=READ
* $E009  CA2   HOLD
* $E00A  PB0-3 IN (UT) DATA
* $E00B  CB1 IN INTERRUPT 1/60 HZ
*        CB2 UT WRITE
*
PRIPIA  EQU    $E00C     PIA F\R PRINTER
*
* KORT C]-817
*
FLOPPY  EQU    $E010
COMREG  EQU    $E018
*
* KORT C]-816
*
EPROM0  EQU    $E0B0
*
* KORT C]-815 TERMINAL
*
CRTREG  EQU    $E0F8
CRTC    EQU    $E0F9
PIAKBD  EQU    $E0FC
PIAKBC  EQU    PIAKBD+1
PIAKD   EQU    PIAKBD+2
PIAKC   EQU    PIAKBD+3
*
*
SKIP1   EQU    $85       SKIPPAR 1 INSTRUKTION
SKIP2   EQU    $8C       SKIPPAR 2 BYTE INSTR
E100    EQU    $E100
F000    EQU    $F000
*
****************************************
*
* RAM F\R VARIABLER OCH STACK
*
****************************************
*
STACK   EQU    $E100+$2FF
*
        ORG    E100
*
* PSEUDOSTACK
*
STRAD   RMB    1
SIRQR   RMB    2         IRQ VEKTOR
SWI1R   RMB    2
SWI2R   RMB    2
SWI3R   RMB    2
USECC   RMB    1
USEA    RMB    1
USEB    RMB    1
USEDP   RMB    1
USEX    RMB    2
USEY    RMB    2
USEU    RMB    2
USEPC   RMB    2
USESP   RMB    2         USER STACKPOINTER VALUE
SLASK   RMB    2
*
VFLAG   RMB    1         NUMBER OF BREAKPOINTS
BPTAB   RMB    15        TABELL F\R BREAKPOINTS
BYTECT  RMB    1         LOAD & PUNCH
MCONT   RMB    1
TEMP    RMB    2         TEMP MEMORY
BEGA    RMB    2         STARTADRESS VID DUMP MM
ENDA    RMB    2         STOPPADRESS VID DUMP MM
TILL    RMB    2         HJ[LPCELL VID KOP VER OCH MEM CHG
CKTMP   RMB    2
PEKARE  RMB    2         AKTUELL LEDIG BILDPOSITION
PIXBEG  RMB    2         START AV VIDEOMINNE
CURPOS  RMB    2         ADRESS F\R CURSORN
ROLADR  RMB    2         STARTADRESS VID SCROLL
CURTMP  RMB    2
PEKTMP  RMB    2
PIXEND  RMB    2         SISTA POS AV VIDEOMINNET
CURRAM  RMB    2
TTEMMP  RMB    2         XTEMP
POSPEK  RMB    2         NY PEKARE VID CURSORPOS
ALFLOK  RMB    1         ALFA LOCK FLAGGA
*
TERAMA  EQU    *
HPOS    RMB    1         HORISONTALPOSITION 0-39
PRIFLG  RMB    1         OUT TO PRINTER
EXCFLG  RMB    1         FLAGGA F\R SPECIALBOKST[VER
CURFLG  RMB    1         FLAGGA F\R CURSOR
ROLFLG  RMB    1         O= SCROLL EJ B\RJAT
CURPFL  RMB    1
ESCFLG  RMB    1
CUSFLG  RMB    1
PAGFLG  RMB    1
HPOSTM  RMB    1
TERAMZ  EQU    *
*
PIX     EQU    $E800
PIXSLU  EQU    $EFFF
RADER   EQU    24
*
        ORG    F000
*
INKEY   JMP    INKEY0
INCHK   JMP    INCHK0
OUTCRT  JMP    OUTCR0
INCHA   JMP    INCHA0    ONLY VERSALER
MONITOR JMP    CONTRL
        JMP    PDATA
        JMP    OUT2HS
        JMP    OUT4HS
        JMP    PCRLF
        JMP    PRIOUT
*
****************************************
* LIB 1.C815TERM
*
* --------------
* REV 16 831108 ]H
*
****************************************
LLENGD  EQU    80
*
OUTCR0  TSTA             IGNORE NULLS
        BNE    OUTCR1
        RTS
*
OUTCR1  PSHS   A,B,X,U,Y SAVE INHOPPSADRESS
        LDB    HPOS
        LDU    CURPOS
        TST    CURPFL    CURSORPOS ?
        BEQ    OUT10
        LBSR   POS500    COLUMN ADRESS
        BRA    OUT090
*
*
OUT10   TST    ESCFLG    VAR F\REG ESCAPE
        BEQ    OUT18
        CLR    ESCFLG
        CMPA   #$40      OM ST\RRE = RADADRESS
        BLO    OUT15
        LBSR   POS100
        BRA    OUT090
*
OUT15   LDX    #INTABE   ESCAPETABELL
        BRA    OUT22
*
OUT18   TST    PAGFLG
OUT20   LDX    #INTAB
OUT22   CMPA   ,X
        BEQ    OUT30
        LEAX   3,X
        CMPX   #INTBND
        BNE    OUT22
        CMPA   #$20      SYNLIGT TECKEN ?
        BLO    OUT095
        BSR    OUT70
OUT090  LBSR   DISCUR    DISPLAY CURSOR
OUT095  PULS   A,B,X,U,Y,PC
*
OUT30   JSR    [1,X]     SUB F\R SPECIALARE
        BRA    OUT090
*
*
OUT70   TST    EXCFLG
        BNE    OUT160
OUT71   LDX    #EXCHTB   EXCHANGE TABELL F\R ][\ MM
OUT110  CMPA   ,X        MATCH ?
        BEQ    OUT150
        LEAX   2,X       N[STA
        CMPX   #EXTBND   SLUT P] TABELL ?
        BNE    OUT110
        FCB    SKIP2
*
OUT150  LDA    1,X       H[MTA NY KOD
OUT160  LEAU   1,U       N[STA POSITION
        STU    CURPOS
        LDX    PEKARE
OUT165  STA    0,X+      LAGRA P] SK[RMEN
OUT167  CMPX   #PIXSLU+1
        BNE    OUT170
        LDX    #PIX
OUT170  STX    PEKARE
        INCB             N[STA HORISONTALPOS
        CMPB   #LLENGD   SLUT P] RADEN
        BNE    OUT200
        CLR    HPOS
        TST    PAGFLG
        BEQ    OUT180
        CMPX   PIXEND
        BNE    OUT180
        LDU    CURPOS
        LEAU   -LLENGD,U
        STU    CURPOS
        BRA    OUT280
*
OUT180  TST    ROLFLG
        BEQ    OUT250
        BRA    OUT300
*
OUT200  STB    HPOS
OUT250  CMPX   PIXEND    SLUT P] BILDEN ?
        BNE    OUT900
*
* UTANF\R BILDEN SCROLLA !
*
OUT280  STA    ROLFLG
OUT300  LBSR   SCROLL
        LDY    #LLENGD   RADERA EN RAD
        LBSR   ERAS20
        TST    PAGFLG
        BNE    OUT309
        STX    PIXEND    NYTT V[RDE
OUT309  RTS
*
LFEED   TST    PAGFLG    SIDMODE ?
        BEQ    LFED01    NIX
        LEAU   LLENGD,U
        CMPU   PIXEND
        BLO    LFED08
        LEAU   -LLENGD,U
        BRA    LFED08
*
LFED01  TST    ROLFLG
        BEQ    LFED02
LFED02  LEAU   LLENGD,U  INCREMENT CURSOR
LFED08  STU    CURPOS
        LDX    PEKARE
        LDB    #LLENGD
LFED12  LEAX   1,X       INCR PEKARE
        CMPX   #PIXSLU+1
        BNE    LFED14
        LDX    #PIX
LFED14  CMPX   PIXEND
        BNE    LFED16
        TST    PAGFLG    PAGEMOD ?
        BEQ    LFED15
        PSHS   X
        LBSR   SCRL50
        PULS   X
        LEAX   -LLENGD,X
        BRA    LFED16
*
LFED15  PSHS   B,X
        BSR    OUT900    SCROLLA
        BSR    OUT280
        PULS   B,X
LFED16  DECB
        BNE    LFED12
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

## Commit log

2023-06-13 Mer info om de olika korten
2023-06-16 Major bug in schematic fixed
2023-06-21 Uppdaterade komponentförteckning
    [CÅ-815.kicad_pcb, CÅ-815.kicad_sch]
2023-07-11 KiCad schema och PCB
    [CÅ-815.kicad_pcb, CÅ-815.kicad_sch]
2023-07-24 Schema och PCB-layout CÅ-833
2023-07-25 Uppdaterade schema och PCB-layout
2023-07-30 Uppdaterade CÅ-8008, schema och KiCad
    [CÅ-8008.kicad_sch]
2023-07-30 Uppdaterade CÅ-8027
    [CÅ-8027.kicad_sch]
2023-07-30 Uppdaterade CÅ-8025
    [CÅ-8025.kicad_sch]
2023-07-30 Uppdaterade CÅ-834
    [CÅ-834.kicad_sch]
2023-07-30 Uppdaterade CÅ-815
    [CÅ-815.kicad_pcb, CÅ-815.kicad_sch]
2023-08-18 Uppdaterade flex.cfg
    [flex.cfg]
2023-09-26 Debug-kort till gamla RT-datorn
    [RT-debug.kicad_sch]
2024-01-08 Updated PCB and BOM för CÅ-.837
2024-03-11 Info om Flex
    [flex.cfg]
2024-03-14 Uppdaterade schema CÅ-8027
    [CÅ-8027.kicad_sch]
2024-04-21 Updated RT-bus connector on all schematics
    [CÅ-815.kicad_sch]
2024-04-23 Uppdaterade schema CÅ-814A
    [CÅ-834.kicad_sch]
2024-05-27 Updaterade schmea CÅ-836 + Gerber
    [CÅ-836-B_Cu.gbr, CÅ-836-B_Mask.gbr, CÅ-836-B_Paste.gbr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]
2024-07-12 Drivers for CA-837 and description how to compile, append and link a new FLEX.
2024-08-17 Backplane for RT-datorn for 19 inch racks
    [RT-Backplane.kicad_pcb, RT-Backplane.kicad_sch]
2024-09-02 Added images for populated boards for Nya RT-datorn
2024-11-13 Update CÅ-8008 - bom.txt
2024-12-08 List of all FLEX.COR versions found
    [FLEX COR-versions.ods]
2025-05-25 F0BUG assembler listing addedd
2025-07-07 Added (corrected) schematic för CÅ-8001

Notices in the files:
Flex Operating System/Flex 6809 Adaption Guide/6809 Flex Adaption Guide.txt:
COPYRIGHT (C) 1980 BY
